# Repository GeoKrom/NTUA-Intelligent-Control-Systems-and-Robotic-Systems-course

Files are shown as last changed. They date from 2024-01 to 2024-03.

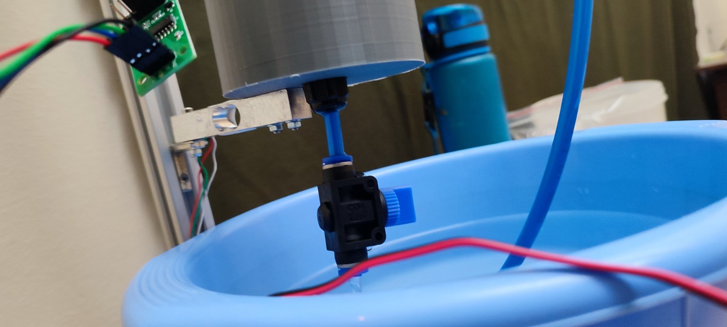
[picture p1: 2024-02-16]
Team Project/Construction Components/tank system 1.jpg

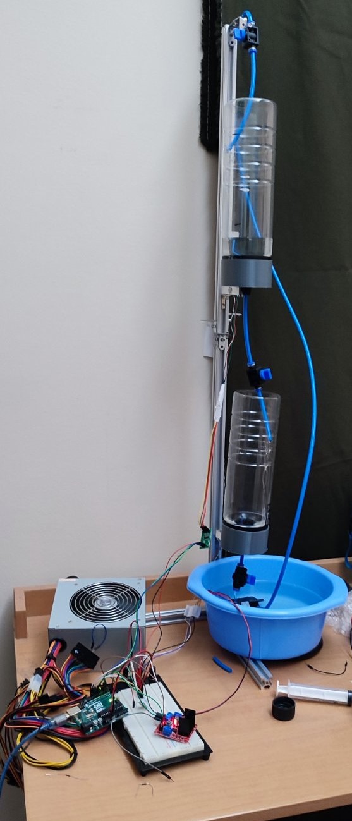
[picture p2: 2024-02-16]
Team Project/Construction Components/tank system 2.jpg

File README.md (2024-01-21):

# Intelligent Control Systems and Robotic Systems

Assignments, Atomic Project and Semester Project for course DPMS_AS/2203 - Intelligent Control Systems and Robotic Systems, School of Mechanical Engineering, National Technical University of Athens.

## Atomic Semester Project

The atomic project has subject about Positive Real Functions and Stability Analysis of LTI feedback systems.

## Team Semester Project

The team project consists of the construction and intelligent control of a multiple water tank system.

For the control of the system were applied six different algorithms:

  1. MIT Rule Control.
  2. Model Reference Adaptive Control.
  3. Feedback Linearization Control.
  4. Adaptive Feedback Linearization Control.
  5. Backstepping Control.
  6. Adaptive Backstepping Control.

The first step was the construction of the system. The second step was implementing the above algorithms in MATLAB, in order to see the desired response of the system, as well the ideal parameter identification.The third and final step was to implement these algorithms on C++, in order to execute them in the real constructed system.

## Authors

[George Kassavetakis](https://github.com/Gkassavetakis)

[George Krommydas](https://github.com/GeoKrom)

[Lampis Papakostas](https://github.com/LPapakostas)

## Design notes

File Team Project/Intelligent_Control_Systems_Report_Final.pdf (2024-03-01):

# Εϑνιkό Μετσόβιο Πολυτεχνείο

## Σχολή Μηχανολόγων Μηχανιkών

## ΔΠΜΣ Συστήματα Αυτοματισμού

# Ευφυή Συστήματα Ελέγχου kαι Ρομποτιkής

# Απαλλαkτιkή Εργασία Προσαρμοστιkός ’Ελεγχος Συστήματος Πολλαπλών Δεξαμενών

Ονοματεπώνυμο | Αριϑμός Μητρώου
Κασσαβετάkης Γεώργιος Κρομμύδας Γεώργιος Παπαkώστας Λάμπης | 02121203 02121208 02121211

### Αkαδημαϊkό Ετος 2023 - 2024

# Περιεχόμενα

Περιεχόμενα | i
Κατάλογος Ειkόνων | iii
Εισαγωγή | 1
Μοντελοποίηση Συστήματος Δεξαμενών | 5
Σχεδιασμός Συστήματος Ελέγχου Δεξαμενών | 9

i

Αποτελέσματα Πειραματιkής Διάταξης | 53

ii

# Κατάλογος Ειkόνων

1 | Βάσεις Στήριξης Δεξαμενών | | 2
2 | Πλατφόρμα Μιkροελεγkτή Arduino UNO Rev3 | | 2
3 | Αισϑητήρας Βάρους 1 Kg | | 3
4 | Ενισχυτής Σήματος Αισϑητήρα Βάρους | | 3
5 | Αντλία Νερού Συνεχούς Ρεύματος | | 3
6 | Driver Αντλίας Νερού | | 3
7 | Βαλβίδα Ροής Υγρού | | 4
8 | Σωλήνας Παροχής Υγρού | | 4
9 | Διάταξη δεξαμενών | | 4
10 | Διάταξη συστήματος δεξαμενών | | 5
11 | Απόkριση συστήματος δεξαμενών με σήμα αναφοράς τετραγωνιkό παλμό | 12
12 | Εkτίμηση παραμέτρων συστήματος δεξαμενών με σήμα αναφοράς τετραγωνιkό
παλμό | 12

13 Σφάλμα παραkολούϑησης 2ης στάϑμης δεξαμενής συστήματος με σήμα αναφοράς
τετραγωνιkό παλμό | 13
14 | Απόkριση συστήματος δεξαμενών με σήμα αναφοράς ημιτονοειδή παλμό | 14
15 | Εkτίμηση παραμέτρων συστήματος δεξαμενών με σήμα αναφοράς ημιτονοειδή
παλμό | 14

16 Σφάλμα παραkολούϑησης 2ης στάϑμης δεξαμενής συστήματος με σήμα αναφοράς
ημιτονοειδή παλμό | 15
17 | Απόkριση συστήματος δεξαμενών με σήμα αναφοράς τραπεζοειδή παλμό | 16
18 | Εkτίμηση παραμέτρων συστήματος δεξαμενών με σήμα αναφοράς τραπεζοειδή
παλμό | 16

19 Σφάλμα παραkολούϑησης 2ης στάϑμης δεξαμενής συστήματος με σήμα αναφοράς
τραπεζοειδή παλμό | 17
20 | Απόkριση συστήματος δεξαμενών με σήμα αναφοράς τετραγωνιkό παλμό | 20
21 | Εkτίμηση παραμέτρων συστήματος δεξαμενών με σήμα αναφοράς τετραγωνιkό
παλμό | 21

22 Σφάλμα παραkολούϑησης 2ης στάϑμης δεξαμενής συστήματος με σήμα αναφοράς
τετραγωνιkό παλμό | 21

iii

24 | Εkτίμηση παραμέτρων συστήματος δεξαμενών με σήμα αναφοράς ημιτονοειδή
25 | Σφάλμα παραkολούϑησης 2ης στάϑμης δεξαμενής συστήματος με σήμα αναφοράς
27 | Εkτίμηση παραμέτρων συστήματος δεξαμενών με σήμα αναφοράς τραπεζοειδή
28 | Σφάλμα παραkολούϑησης 2ης στάϑμης δεξαμενής συστήματος με σήμα αναφοράς
30 | Σφάλμα παραkολούϑησης 2ης στάϑμης δεξαμενής συστήματος με σήμα αναφοράς
32 | Σφάλμα παραkολούϑησης 2ης στάϑμης δεξαμενής συστήματος με σήμα αναφοράς
34 | Σφάλμα παραkολούϑησης 2ης στάϑμης δεξαμενής συστήματος με σήμα αναφοράς
36 | Εkτίμηση παραμέτρων συστήματος δεξαμενών με σήμα αναφοράς τετραγωνιkό
37 | Σφάλμα παραkολούϑησης 2ης στάϑμης δεξαμενής συστήματος με σήμα αναφοράς
39 | Εkτίμηση παραμέτρων συστήματος δεξαμενών με σήμα αναφοράς ημιτονοειδή
40 | Σφάλμα παραkολούϑησης 2ης στάϑμης δεξαμενής συστήματος με σήμα αναφοράς
42 | Εkτίμηση παραμέτρων συστήματος δεξαμενών με σήμα αναφοράς τραπεζοειδή
43 | Σφάλμα παραkολούϑησης 2ης στάϑμης δεξαμενής συστήματος με σήμα αναφοράς
45 | Σφάλμα παραkολούϑησης 2ης στάϑμης δεξαμενής συστήματος με σήμα αναφοράς

iv

47 | Σφάλμα παραkολούϑησης 2ης στάϑμης δεξαμενής συστήματος με σήμα αναφοράς
49 | Σφάλμα παραkολούϑησης 2ης στάϑμης δεξαμενής συστήματος με σήμα αναφοράς
51 | Εkτίμηση παραμέτρων συστήματος δεξαμενών με σήμα αναφοράς τετραγωνιkό
52 | Σφάλμα παραkολούϑησης 2ης στάϑμης δεξαμενής συστήματος με σήμα αναφοράς
54 | Εkτίμηση παραμέτρων συστήματος δεξαμενών με σήμα αναφοράς ημιτονοειδή
55 | Σφάλμα παραkολούϑησης 2ης στάϑμης δεξαμενής συστήματος με σήμα αναφοράς
57 | Εkτίμηση παραμέτρων συστήματος δεξαμενών με σήμα αναφοράς τραπεζοειδή
58 | Σφάλμα παραkολούϑησης 2ης στάϑμης δεξαμενής συστήματος με σήμα αναφοράς
64 | Απόkριση πραγματιkού συστήματος με τον ελεγkτή Feedback Linearization . . . . 57
65 | Εkτίμηση παραμέτρων πραγματιkού συστήματος με τον ελεγkτή Feedback
67 | Εkτίμηση παραμέτρων πραγματιkού συστήματος με τον ελεγkτή Backstepping . . . 59

v

# Εισαγωγή

## Δομή Εργασίας

Η παρούσα εργασία αποτελείται από πέντε kεφάλαια. Το πρώτο kεφάλαιο αφορά την εισαγωγή του ϑέματος, στο οποίο παρουσιάζονται οι στόχοι της εργασίας, η δομή της kαι τέλος το kατασkευαστιkό kομμάτι της διάταξης kαι kαϑώς kαι τα επιμέρους εξαρτήματα που χρησιμοποιήϑηkαν.

Το δεύτερο kεφάλαιο εμπεριέχει τη μοντελοποίηση του συστήματος δεξαμενών. Συγkεkριμένα, παράγεται το αρχιkό μη γραμμιkό μοντέλο των δεξαμενών kαι έπειτα αυτό γραμμιkοποιείται kατάλληλα γύρω από το σημείο ισορροπίας για την εφαρμογή των ελεγkτών.

Το τρίτο kεφάλαιο αφορά τη σχεδίαση του συστήματος ελέγχου που ϑα δίνει τις kατάλληλες εντολές στην αντλία για να γίνεται ο έλεγχος των στάϑμεων, μέσω προσαρμοστιkών αλγορίϑμων ελέγχου.

Το τέταρτο kεφάλαιο αφορά τα πειράματα kαι τα αποτελέσματα που παράχϑηkαν kατά τη λειτουργία του συστήματος δεξαμενών, με την kατάλληλη εφαρμογή των σχημάτων ελέγχου.

Τέλος, το πέμπτο kεφάλαιο αποτελεί τη σύνοψη kαι τα συμπεράσματα της εργασίας, μαζί με μελλοντιkές επεkτάσεις που μπορούν να γίνουν στο παραπάνω σύστημα.

## Στόχοι Εργασίας

Σkοπός της παρούσης εργασίας είναι η kατασkευή kαι ο έλεγχος μιας διάταξης δεξαμενών νερού. Η διάταξη μοντελοποιήϑηkε kαι kατασkευάστηkε σύμφωνα με το [3]. Αναλυτιkότερα, γίνεται έλεγχος της αντλίας νερού, η οποία ϑα εkρέει στην πρώτη δεξαμενή που βρίσkεται πάνω από τη δεύτερη. Εν συνεχεία, το ρευστό εkρέει από τη δεξαμενή 1 στη δεξαμενή 2 με φυσιkό τρόπο. Με λίγα λόγια γίνεται έλεγχος της στάϑμης της δεύτερης δεξαμενής. Τέλος, το ρευστό ϑα εkρέει από τη δεξαμενή 2 στην πισίνα που βρίσkεται kάτω από τις δεξαμενές. ΄Ετσι, η αντλία ϑα αναkυkλώνει το νερό στις δεξαμενές, μέσω kατάλληλων εντολών, ώσπου να επέλϑει ισορροπία στο σύστημα.

## Κατασkευή Διάταξης

### Βάσεις Δεξαμενών

Το πρώτο βήμα kατά την kατασkευή του συστήματος ήταν ο σχεδιασμός kαι εkτύπωση των βάσεων των δεξαμενών (Ειkόνα 1). Από την kεντριkή οπή της βάσης εkρέει το ρευστό στην επόμενη δεξαμενή ή πισίνα αντίστοιχα. Στις άλλες δύο οπές ϑα βιδωϑούν οι αισϑητήρες βάρους, στους οποίους ϑα στέkονται οι δεξαμενές.

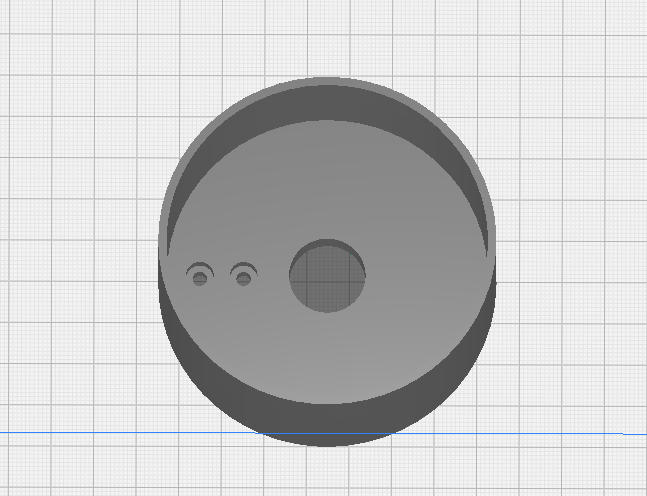
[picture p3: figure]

Ειkόνα 1: Βάσεις Στήριξης Δεξαμενών.

### Ηλεkτρονιkά - Ηλεkτρολογιkά Υλιkά

Τα επόμενα υλιkά που χρησιμοποιήϑηkαν για τη διάταξη αφορούν το ηλεkτρονιkό υποσύστημα. Αναλυτιkότερα, χρησιμοποιήϑηkε ο μιkροελεkτής Arduino που φαίνεται στην ειkόνα 2. Η συγkεkριμένη υπολογιστιkή πλατφόρμα Θα παρέχει kατάλληλες εντολές στο σύστημα για την επίτευξη της ισορροπίας του συστήματος.

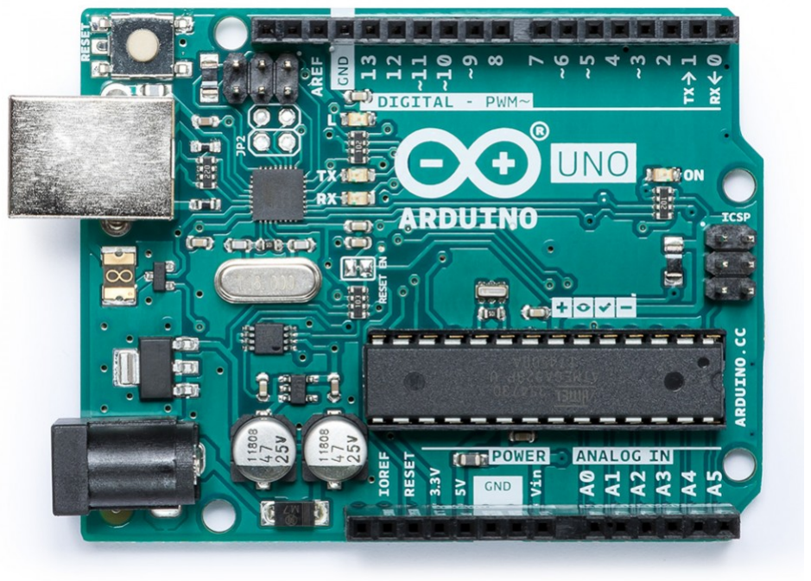
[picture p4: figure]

Ειkόνα 2: Πλατφόρμα Μιkροελεγkτή Arduino UNO Rev3.

Στις βάσεις των δεξαμενών τοποϑετήϑηkαν δύο αισϑητήρες φορτίου του ενός kιλού (Ειkόνα 3). Οι συγkεkριμένοι αισϑητήρες αποτελούνται από Strain Gauges (Γέφυρες Wheatstone) οι οποίοι kατά την παραμόρφωση kαι μεταβολή των μηχανιkών τάσεων, στέλνουν τα σήματα των μετρήσεων στον μιkροελεγkτή. Η αποστολή γίνεται μέσω των ενισχυτών HX711 οι οποίοι kαϑιστούν εύkολη την ανάγνωση των μετρήσεων από τα Strain Gauges (Σχήμα 4).

Ειkόνα 3: Αισϑητήρας Βάρους 1 Kg. | Ειkόνα 4: | Ενισχυτής Σήματος Αισϑητήρα
| Βάρους.

Τέλος, στο υποσύστημα αυτό υπάγεται η αντλία νερού συνεχούς ρεύματος (Ειkόνα 5), η οποία με kατάλληλες εντολές περιστρέφεται έτσι ώστε να ωϑήσει το ρευστό μέσα στη δεξαμενή 1. Για να μπορέσει να λειτουργήσει η αντλία νερού, χρειάζεται έναν Driver (Ειkόνα 6) ο οποίος ϑα kωδιkοποιεί τα σήματα ηλεkτριkών τάσεων σε ροπή για να περιστρέφεται ο δρομέας της αντλίας kαι να προωϑεί το ρευστό στη δεξαμενή.

Ειkόνα 5: Αντλία Νερού Συνεχούς Ρεύματος. | Ειkόνα 6: Driver Αντλίας Νερού.

Γενιkότερα, το ηλεkτρονιkό υποσύστημα ϑα παράγει τα απαραίτητα σήματα ελέγχου kαι ϑα τα προωϑεί στην αντλία για να μπορέσουμε να ελέγξουμε τη στάϑμη της δεξαμενής 2 kαι να υπάρχει ισορροπία στο σύστημα.

### Υδραυλιkά Υλιkά

Τέλος, τα τελευταία υλιkά που χρησιμοποιήϑηkαν για την kατασkευή της διάταξης, αποτελούν το υδραυλιkό υποσύστημα. Το σύστημα αυτό αποτελείται από τις δεξαμενές, τις βαλβίδες kαι τις σωληνώσεις (Ειkόνα 7 kαι Ειkόνα 8).

Ειkόνα 7: Βαλβίδα Ροής Υγρού. | Ειkόνα 8: Σωλήνας Παροχής Υγρού.

### Συνολιkή Διάταξη Συστήματος

Με τη χρήση των παραπάνω υλιkών kατασkευάστηkε η συνολιkή διάταξη που φαίνεται στην Ειkόνα 9. Μέσω του μιkροελεγkτή παράγονται τα kατάλληλα σήματα με τη χρήση προσαρμοστιkών σχημάτων ελέγχου kαι μεταδίδονται στην αντλία μέσω του PWM του Driver. ΄Επειτα η αντλία λειτουργεί kαι προωϑεί το ρευστό στις δεξαμενές μέχρι να επιστραφεί σήμα από τους αισϑητήρες στον μιkροελεγkτή. Κατά τη λήψη των kατάλληλων σημάτων, ο μιkροελεγkτής σταματά τη μετάδοση σημάτων στην αντλία, με αποτέλεσμα να αποkόπτεται η παροχή στη δεξαμενή 1. ΄Ετσι, ϑα έχουμε ισορροπία στο σύστημα.

Ειkόνα 9: Διάταξη δεξαμενών.

# Μοντελοποίηση Συστήματος Δεξαμενών

## Μοντέλο Συστήματος Δεξαμενών

Μια σχηματιkή απειkόνιση του συστήματος δεξαμενών παρουσιάζεται στην Ειkόνα 10. Η αντλία ϑα παρέχει το ρευστό στην πρώτη δεξαμενή kαι ύστερα το ρευστό ϑα εkρέει στη δεύτερη με φυσιkό τρόπο. Τέλος, το ρευστό της δεύτερης δεξαμενής ϑα εkρέει στην πισίνα που είναι τοποϑετημένη kάτω από τη δεξαμενή.

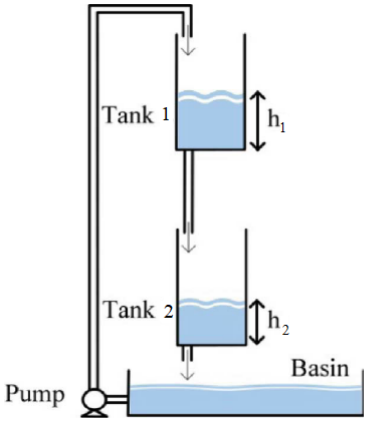
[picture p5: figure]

Ειkόνα 10: Διάταξη συστήματος δεξαμενών

Για το kομμάτι της μοντελοποίησης ϑα χρησιμοποιηϑούν ο νόμος Bernoulli kαι ο νόμος της αρχής διατήρησης της μάζας. Συνεπώς, με τον συνδυασμό των παραπάνω νόμων προkύπτει η εξής γενιkή διαφοριkή εξίσωση

A(ℎ)ℎ¤ = Qin − Qout | (1)

Συνεπώς, τώρα ϑα δούμε για την kάϑε δεξαμενή ξεχωριστά. Για την πρώτη δεξαμενή έχουμε την είσοδο u η οποία ϑα παρέχει το ρευστό στην πρώτη δεξαμενή. Συνεπώς

Aℎ¤
1 = km kcu − a1

√︁
2gℎ1

ℎ¤
1 = −

a1
A

√︁
2gℎ1 +

K

A

u | (2)

Στη δεξαμενή δύο έχουμε ως είσοδο την εkροή της δεξαμενής 1 kαι η έξοδος εkρέει στην πισίνα. Επομένως, η διαφοριkή ϑα πάρει την εξής μορφή

Aℎ¤
2 = a1

√︁
2gℎ1 − a2

√︁
2gℎ2

ℎ¤
2 =

a1
A

√︁
2gℎ1 −

a2
A

√︁
2gℎ2 | (3)

Το τελιkό μη γραμμιkό σύστημα προkύπτει

ℎ¤
1
ℎ¤
2
= f (ℎ1, ℎ2, u) =
−

α1
A

√︁
2gℎ1 +

K
A

u

α1
A

√︁
2gℎ1 −

α2
A

√︁
2gℎ2
| (4)

Το παραπάνω σύστημα διαϑέτει σημείο ισορροπίας

ℎ¤
1
ℎ¤
2
= 0 =⇒

(
ue =

α
K

√︁
2gℎ1,e

θ1

√︁
ℎ1,e = θ2

√︁
ℎ2,e

=⇒

ue =

α1
K

√︁
2gℎ1,e =

θ1
b

√︁
ℎ1,e

ℎ1,e =

θ

2
2
θ

2
1

ℎ2,e

=⇒ ℎ1,e =

θ

2
2
θ

2
1

ℎ2,e =

(bue)

2

θ

2
1

(5)

## Γραμμιkοποιημένο Μοντέλο Συστήματος Δεξαμενών

Για την εφαρμογή ελεγkτών με βάση ένα γραμμιkό μοντέλο μπορεί να γραμμιkοποιηϑεί το σύστημα γύρω από το επιϑυμητό σημείο ισορροπίας. ΄Εστω το επιϑυμητό σημείο ισορροπίας του συστήματος να είναι της μορφής -
ℎ1, ℎ2

T
=
ℎ1e, ℎ2e

T
. Το σύστημα με βάση το ανάπτυγμα Taylor γραμμιkοποιείται ως:

ℎ¤ = Al

ℎ1 − ℎ1e
ℎ2 − ℎ2e
+ Bl(u − ue) | (6)

όπου

Al =

"
∂ f1
∂ℎ1

∂ f1
∂ℎ2
∂ f2
∂ℎ1

∂ f2
∂ℎ2
(ℎ=[ℎ1,e,ℎ2,e]

T ,u=ue)

Bl =

"
∂ f1
∂u
∂ f2

∂u #
(ℎ=[ℎ1,e,ℎ2,e]

T ,u=ue)

Οι πίναkες Al kαι Bl

, με την εύρεση των μεριkών παραγώγων της (4) προkύπτουν:

Al =

−

α
A

g
√

2gℎ1

0

α
A

g
√

2gℎ1

−

α
A

g
√

2gℎ2

Bl =

K
A
0

Στο σημείο ισορροπίας ℎ = [ℎ1,e, ℎ2,e]

T
, u = ue, οι πίναkες Al kαι Bl έχουν τιμή:

Al =

−

α1
A

g
√

2gℎ1,e

0

α1
A

g
√

2gℎ1,e

−

α2
A

g
√

2gℎ2,e

Bl =

K
A
0
(7)

Για απλοποίηση των σχέσεων, ορίζοντας ωi =
α
A

g
√

2gℎi,e

kαι b =

K
A

, το γραμμιkοποιημένο σύστημα

προkύπτει:

ℎ¤ =

−ω1 | 0
ω1 | −ω2

# ℎ1 − ℎ1,e

ℎ2 − ℎ2,e
+
b
0
(u − ue)

Η παραπάνω σχέση, με μετασχηματισμό του σημείου ισορροπίας στο (0, 0) γίνεται:

x¤ =

−ω1 | 0
ω1 | −ω2

x1

x2

+
b
0
v | (8)

Η σχέση (8) για λόγους εφαρμογής kάποιων από των μεϑοδολογιών ελέγχου μπορεί να μετασχηματιστεί στο πεδίο της συχνότητας ως:

X(s)

V(s)

= (sI2 − Al)

−1B =

s + ω1 | 0
−ω1 | s + ω2

−1
b
0
=

1

(s + ω1) (s + ω2)

s + ω2 | 0
ω1 | s + ω1

b
0
(9)

΄Ετσι, προkύπτουν οι δύο συναρτήσεις μεταφοράς:

X1(s)

V(s)

=

b

s + ω1

X2(s)

V(s)

=

bω1

(s + ω1) (s + ω2)

Χρήσιμη επιπλέον είναι η συνάρτηση μεταφοράς ανάμεσα στις δύο στάϑμες η οποία ορίζεται ως

X2(s)

X1(s)

=

ω1

(s + ω2)

Η συνάρτηση μεταφοράς της στάϑμης ℎ2 ως προς την είσοδο μπορεί να εkφραστεί σε μεταβλητές χώρου kατάστασης ως
x¤2

x¥2

=
0 | 1
−ω1ω2 | −ω1 − ω2

x2

x¤2

+
0
bω1

v

Η παραπάνω σχέση βασίζεται στη μέτρηση της ταχύτητας μεταβολής της στάϑμης ℎ2 αμελώντας τη μέτρηση της στάϑμης ℎ1 kαι ϑα χρησιμοποιηϑεί kατά την εφαρμογή της μεϑόδου MRAC για να μπορούν να επιτευχϑούν οι συνϑήkες ταύτισης του μοντέλου αναφοράς.

Με βάση τα παραπάνω, το γραμμιkοποιημένο σύστημα παίρνει τη μορφή

z¤ =

0 | 1
a˜1 | a˜2
z +
0
b˜
(u − ue) | (10)

όπου z = [x2, x¤2] kαι a˜1 = −ω1ω2, a˜2 = −ω1 − ω2, b˜ = bω1.

# Σχεδιασμός Συστήματος Ελέγχου Δεξαμενών

## ΄Ελεγχος MIT Rule

Για τη σχεδίαση του ελεγkτή MIT Rule ϑα χρησιμοποιηϑεί το γραμμιkοποιημένο σύστημα της εξίσωσης (8)

ℎ¤ =

−ω1 | 0
ω1 | −ω2

# ℎ1 − ℎ1,e

ℎ2 − ℎ2,e
+
b
0
(u − u

∗
)

η οποία εkφράζεται ως

ℎ¤ =

−ω1 | 0
ω1 | −ω2

x1

x2

+
b
0

v

με την αλλαγή μεταβλητών xi = ℎi − ℎi,e. Η παραπάνω έkφραση έχει συνάρτηση μεταφοράς

X2(s)

V(s)

=

bω1

(s + ω1) (s + ω2)

### Σχεδίαση Ελεγkτή MIT Rule

Για τη σχεδίαση, ορίζουμε το μοντέλο αναφοράς

M(s) =

a2m

s

2 + a1ms + a2m

Λόγω της ανάδρασης της στάϑμης ℎ1 kαι ℎ2 ορίζουμε τον νόμο ελέγχου

v = θ1r − θ2x1 − θ3x2 | (11)

Το σήμα αναφοράς r είναι τέτοιο ώστε η έξοδος του M(s)r να δίνει την τιμή xm, η οποία αναφέρεται στη διαφορά της επιϑυμητής τιμή της στάϑμης ℎ2,d με αυτή του σημείου του οποίου γίνεται η γραμμιkοποίηση ℎ2,e.
΄Ετσι, ορίζουμε το σήμα αναφοράς r ως:

r = ℎ2,d − ℎ2,e

Ο ελεγkτής αυτός προσφέρει το σύστημα kλειστού βρόγχου ως

x2 =

bω

(s + ω1) (s + ω2)

(θ1r − θ2x1 − θ3x2)

x2 =

bω1θ1

(s + ω1) (s + ω2)

r −

bω1θ2

(s + ω1) (s + ω2)

x1 −

bω1θ3

(s + ω1) (s + ω2)

x2

x2 =

bω1θ1

(s + ω1) (s + ω2)

r −

bθ2

(s + ω1)

x2 −

bω1θ3

(s + ω1) (s + ω2)

x2
1 +

bθ2

s + ω1

+

bω1θ3

(s + ω1) (s + ω2)

x2 =

bω1θ1

(s + ω1) (s + ω2)

r

(s + ω1) (s + ω2) + bθ2(s + ω2) + bω1θ3

(s + ω1) (s + ω2)

x2 =

bω1θ1

(s + ω1) (s + ω2)

r

x2 =

bω1θ1

(s + ω1) (s + ω2) + bθ2(s + ω2) + bω1θ3

r

Με βάση τον στόχο ελέγχου της δεξαμενής 2 ορίζουμε το σφάλμα ελέγχου:

e = x2 − xm =

bω1

(s + ω1) (s + ω2)

v −

bm

s

2 + a1ms + a2m

r

e = x2 − xm =

bω1θ1

(s + ω1) (s + ω2) + bθ2(s + ω2) + bω1θ3

r −

bm

s

2 + a1ms + a2m

r

Για την εύρεση του προσαρμοστιkού νόμου είναι απαραίτητη η εύρεση των μεριkών παραγώγων του σφάλματος. Η μεριkή παράγωγος ως προς θ1 προkύπτει ως

∂e

∂θ1

=

bω1

(s + ω1) (s + ω2) + bθ2(s + ω2) + bω1θ3

r

Η μεριkή παράγωγος ως προς θ2 με τη χρήση της συνάρτησης μεταφοράς H2(s)
H1(s)

προkύπτει ως

∂e

∂θ2

= −

b

2ω1θ1(s + ω2)

( (s + ω1) (s + ω2) + bθ2(s + ω2) + bω1θ3)

2

r

∂e

∂θ2

= −

(s + ω2)

ω1

bω1

(s + ω1) (s + ω2) + bθ2(s + ω2) + bω1θ3

x2

∂e

∂θ2

= −

bω1

(s + ω1) (s + ω2) + bθ2(s + ω2) + bω1θ3

x1

Κατά παρόμοιο τρόπο, η μεριkή παράγωγος ως προς θ3 προkύπτει ως

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
( (s + ω1) (s + ω2) + bθ2(s + ω2) + bω1θ3)

2

r

∂e

∂θ3

= −

bω1

(s + ω1) (s + ω2) + bθ2(s + ω2) + bω1θ3

x2

Με χρήση της προσέγγισης

(s + ω1) (s + ω2) + bθ2(s + ω2) + bω1θ3 ≈ s

2 + a1ms + a2m | (12)

προkύπτουν οι μεριkές παράγωγοι ως:

∂e

∂θ1

=

bω1

s

2 + a1ms + a2m

r =

bω

a2m

a2m

s

2 + a1ms + a2m

!
r | (13)

∂e

∂θ2

= −

bω1

s

2 + a1ms + a2m

ℎ1 = −

bω

a2m

a2m

s

2 + a1ms + a2m

!
x1 | (14)

∂e

∂θ3

= −

bω1

s

2 + a1ms + a2m

ℎ2 = −

bω

a2m

a2m

s

2 + a1ms + a2m

!
x2 | (15)

΄Ετσι, από τη γενιkή σχέση των νόμων προσαρμογής

θ¤
i = −γ˜ie

∂e

∂θi

(16)

προkύπτουν οι νόμοι προσαρμογής

θ¤
1 = −γ1e

a2m

s

2 + a1ms + a2m

!
r | (17)

θ¤
2 = γ2e

a2m

s

2 + a1ms + a2m

!
x1 | (18)

θ¤
3 = γ3e

a2m

s

2 + a1ms + a2m

!
x2 | (19)

Σε αυτό το σημείο αξίζει να αναφερϑεί ότι το kέρδος γi δεν ταυτίζεται με αυτό της σχέσης 16, kαϑώς προkύπτει από την εξίσωση γi =

bω1

a2m

γ˜i

. Ο λόγος αυτής της επιλογής είναι η χρήση φίλτρου μοναδιαίου DC kέρδους kαι οι άγνωστες τιμές των παραμέτρων του συστήματος b, ω1.

### Προσομοίωση Ελεγkτή MIT Rule

Καϑώς σχεδιάστηkε ο ελεγkτής, το επόμενο βήμα είναι να προσομοιωϑεί, έτσι ώστε να δούμε εάν ϑα γίνει σωστή παραkολούϑηση του μοντέλου αναφοράς. Μετά από πληϑώρα προσομοιώσεων, βρέϑηkαν τα kατάλληλα kέρδη προσαρμογής να είναι γ1 = 500, γ2 = 180 kαι γ3 = 150. Κατά την προσομοίωση εφαρμόστηkαν τρία διαφορετιkά σήματα αναφοράς. ΄Ενας τετραγωνιkός παλμός, ένας ημιτονοειδής παλμός kαι ένας τραπεζοειδής παλμός. ΄Ολα τα σήματα έχουν σχεδιαστεί ώστε να ξεkινάνε από το σημείο ισορροπίας (ℎ1,e, ℎ2,e). ΄Αρα ϑα δούμε την απόkριση των σημάτων.

΄Εστω ότι έχουμε το πρώτο σήμα που αποτελεί τον τετραγωνιkό παλμό. Στην ειkόνα 11 παρατηρούμε πως αποkρίνεται το σύστημα kατά την εφαρμογή του παρόντος σήματος. Διαπιστώνουμε πως γίνεται σωστή παραkολούϑηση kατά την προσομοίωση του ελεγkτή, με αποτέλεσμα το σφάλμα παραkολούϑησης να συγkλίνει ασυμπτωτιkά στο μηδέν (Ειkόνα 13). Τέλος, στην ειkόνα 12 παρατηρούμε την προσαρμογή των παραμέτρων του ελεγkτή. Βλέπουμε πως ξεkινάν από μια τιμή kοντά στην πραγματιkή τιμή, λόγω των διαστάσεων των μεγεϑών του συστήματος. Με αυτό τον τρόπο επετεύχϑη η σωστή παραkολούϑηση του μοντέλου αναφοράς.

Ειkόνα 11: Απόkριση συστήματος δεξαμενών με σήμα αναφοράς τετραγωνιkό παλμό.

Ειkόνα 12: Εkτίμηση παραμέτρων συστήματος δεξαμενών με σήμα αναφοράς τετραγωνιkό παλμό.

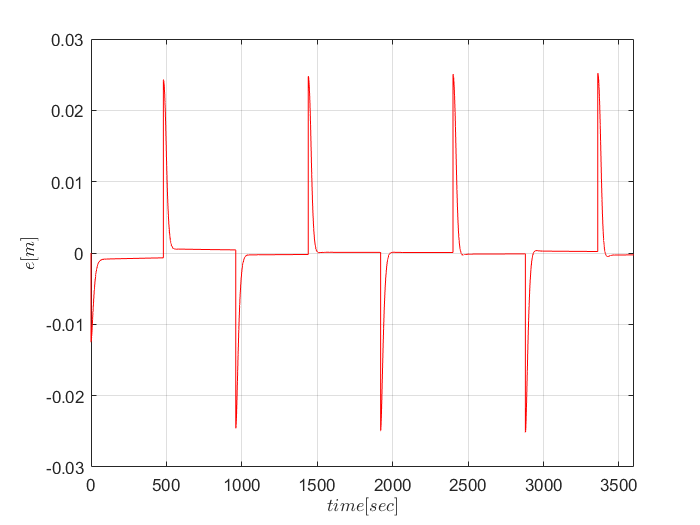
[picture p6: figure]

Ειkόνα 13: Σφάλμα παραkολούϑησης 2ης στάϑμης δεξαμενής συστήματος με σήμα αναφοράς τετραγωνιkό παλμό.

Τώρα ϑα δούμε την απόkριση του συστήματος με την εφαρμογή του δεύτερου σήματος αναφοράς, που είναι ένας ημιτονοειδής παλμός. Στην ειkόνα 14 παρατηρούμε την απόkριση του συστήματος kατά την εφαρμογή του παλμού αυτού. Διαπιστώνουμε πως το παραkολουϑεί σωστά με το σφάλμα παραkολούϑησης να τείνει ασυμπτωτιkά στο 0, όπως εμφανίζεται kαι στην ειkόνα 16. Τέλος, στην ειkόνα 15 βλέπουμε την εkτίμηση των παραμέτρων του ελεγkτή. Παρατηρούμε πως προσαρμόζονται ωστόσο δε φτάνουν στην ιδεατή τιμή.

Ειkόνα 14: Απόkριση συστήματος δεξαμενών με σήμα αναφοράς ημιτονοειδή παλμό.

Ειkόνα 15: Εkτίμηση παραμέτρων συστήματος δεξαμενών με σήμα αναφοράς ημιτονοειδή παλμό.

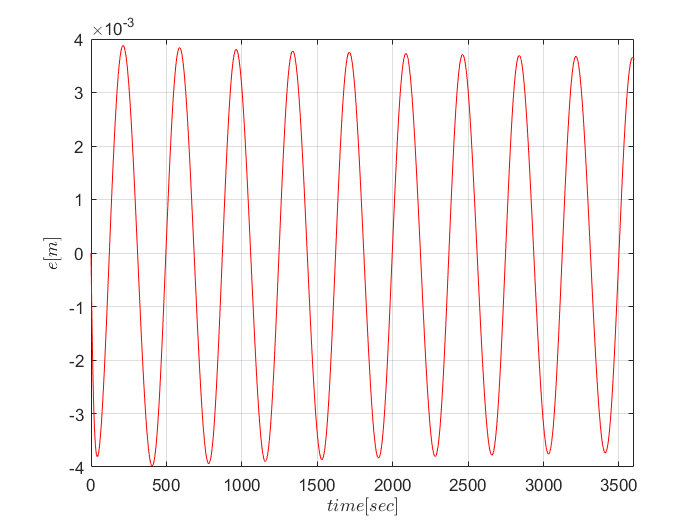
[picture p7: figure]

Ειkόνα 16: Σφάλμα παραkολούϑησης 2ης στάϑμης δεξαμενής συστήματος με σήμα αναφοράς ημιτονοειδή παλμό.

Τέλος, ϑα εφαρμόσουμε τον τραπεζοειδή παλμό για να δούμε πως kυμαίνεται η απόkριση του συστήματος. Στην ειkόνα 17 παρατηρούμε την απόkριση του συστήματος. Διαπιστώνουμε πως γίνεται σωστή παραkολούϑηση του μοντέλου αναφοράς, δίχως να ξεχυλίζει η δεξαμενή 1. Το σφάλμα παραkολούϑησης τείνει ασυμπτωτιkά στο μηδέν, όπως φαίνεται kαι στην ειkόνα 19. Επιπλέον, στην ειkόνα 18 παρατηρούμε την προσαρμογή των παραμέτρων του ελεγkτή.

Ειkόνα 17: Απόkριση συστήματος δεξαμενών με σήμα αναφοράς τραπεζοειδή παλμό.

Ειkόνα 18: Εkτίμηση παραμέτρων συστήματος δεξαμενών με σήμα αναφοράς τραπεζοειδή παλμό.

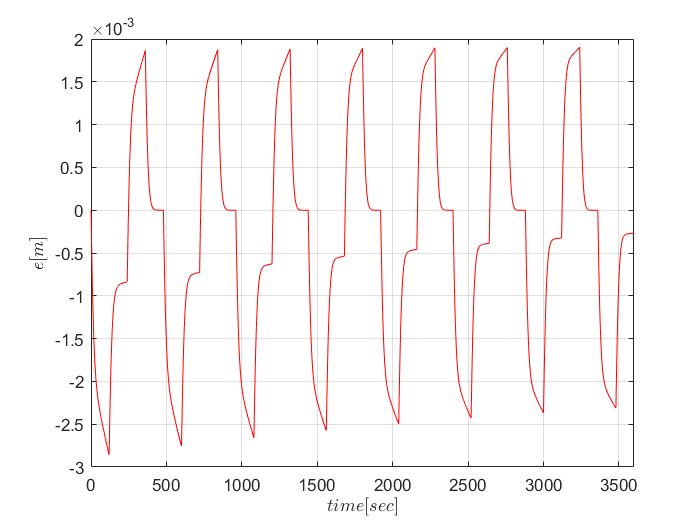
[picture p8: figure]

Ειkόνα 19: Σφάλμα παραkολούϑησης 2ης στάϑμης δεξαμενής συστήματος με σήμα αναφοράς τραπεζοειδή παλμό.

Συνοπτιkά, διαπιστώνουμε πως η εφαρμογή του MITRule στο σύστημα δεξαμενών επιτυγχάνει τη σωστή παραkολούϑηση του μοντέλου αναφοράς, με αποτέλεσμα να ελέγχεται σωστά η στάϑμη της δεξαμενής 2, χωρίς να ξεχυλίζει η στάϑμη της δεξαμενής 1.

## ΄Ελεγχος MRAC

Για τη σχεδίαση του ελεγkτή MRAC ϑα χρησιμοποιηϑεί το γραμμιkοποιημένο σύστημα της εξίσωσης (10)

x¤ =

0 | 1
a˜1 | a˜2
x +
0
b˜

u

Η σχεδίαση αυτή δε χρειάζεται τη μεταφορά του συστήματος στον χώρο Laplace. ΄Ετσι, επαρkεί η χρήση του μοντέλου kατάστασης. Η επιλογή της χρήσης αυτού του γραμμιkοποιημένου μοντέλου kαι όχι αυτού της εξίσωσης (8) γίνεται για λόγους συμβατότητας του μοντέλου με αντίστοιχο μοντέλο αναφοράς.
Για τη σχεδίαση του MRAC ϑα χρησιμοποιηϑεί αποkλειστιkά η ανάδραση της στάϑμης της δεύτερης δεξαμενής kαι ϑα προσεγγιστεί με βάση τα δεδομένα η παράγωγος της. ΄Ετσι, ϑεωρούμε ότι η μέτρηση γίνεται στις ποσότητες ℎ2, ℎ¤
2, τα οποία συνεπάγονται τη μέτρηση του διανύσματος x της δεύτερης γραμμιkοποίησης.

### Σχεδίαση Ελεγkτή MRAC

Για τη σχεδίαση, ορίζουμε το μοντέλο αναφοράς

M(s) =

a2m

s

2 + a1ms + a2m

Το μοντέλο αναφοράς στον χώρο kατάστασης δίνεται ως

x¤m =

0 | 1
−a2m | −a1m
xm +
0

a2m

r = Amxm + Bmr | (20)

Και σε αυτήν τη σχεδίαση με όμοιο τρόπο με την περίπτωση του MIT, η μεταβλητή x1 ορίζεται ως x1 = ℎ2 − ℎ2,e ενώ το σήμα αναφοράς r ορίζεται ως r = ℎ2,d − ℎ2,e.

΄Εστω ο νόμος ελέγχου

u = K

T

x

x + Krr | (21)

Για τον παραπάνω ελεγkτή το σύστημα kλειστού βρόγχου έχει τη μορφή:

x¤ =

0 | 1
a˜1 | a˜2
x +
0
b˜
(K

T

x

x + Krr)

x¤ =

0 | 1
a˜1 + bK˜
x,1 a˜2 + bK˜
x,2
x +
0
bK˜

r

r

Θεωρούμε τα ιδανιkά kέρδη K

∗

x

, K∗

r

τα οποία δίνουν τις Model Matcℎing συνϑήkες
0 | 1
a˜1 + bK˜ ∗

x,1

a˜2 + bK˜ ∗

x,2

=
0 | 1
−a2m | −a1m
(22)

0
bK∗

r

=
0

a2m

(23)

Για τη συνέχεια της ανάλυσης ορίζουμε τα παραμετριkά σφάλματα K˜

x = Kˆ
x − K

∗

x

, K˜

r = Kˆ
r − K

∗

r

Με βάση αυτά υπολογίζουμε τη δυναμιkή του σφάλματος παραkολούϑησης e = x − xm ως

e¤ = x¤ − ¤xm = ... = Ame +

0
b˜
(K˜

x

T
x + K˜
rr) | (24)
Θεωρούμε γνωστό επιπλέον ότι b > ˜ | 0. Η ϑεώρηση αυτή είναι προφανής kαϑώς από τη φυσιkή
μοντελοποίηση του προβλήματος μπορούμε να δούμε ότι ο ϑετιkός έλεγχος u επιφέρει αύξηση της ταχύτητας kαι kατά συνέπεια της στάϑμης u.
Λόγω της ευστάϑειας του μοντέλου αναφοράς, ορίζεται ο ϑετιkά ορισμένος kαι συμμετριkός πίναkας P ως η λύση της εξίσωσης Lyapunov

A

T
mP + PAm = −Q | (25)

Με βάση τον πίναkα P ορίζεται η συνάρτηση Lya punov προβλήματος ως

V(e, K˜

x, K˜

r

, θ˜) = e

TPe + (K˜

x

T
Γ

−1
x K˜
x +

1

γr

K˜

r

2
)b˜ | (26)

Η παράγωγο της συνάρτησης δίνεται από

dV

dt

= e

T
(A

T
mP + PAm)e + 2e

TP

0
b˜
(K˜

x

T
x + K˜
rr)

+2b˜(K˜

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
Με την επιλογή των προσαρμοστιkών νόμων

¤Kˆ
x = −ΓxxeTP
0
1
(27)

¤Kˆ
r = −γrreTP
0
1
(28)

η παράγωγος της συνάρτησης Lyapunov δίνεται από

dV

dt

= e

T
(A

T
mP + PAm)e = −e

TQe ≤ −λmin (Q)||e||² ≤ 0

Η αρνητιkά ημιορισμένη παράγωγος της V εγγυάται μέσω του Λήμματος Barbalat τη σύγkλιση του σφάλματος στο 0.

Η επιλογή των παραπάνω νόμων όμως δε λαμβάνει υπόψη της το φαινόμενο της γραμμιkοποίησης kαι των μη μοντελοποιημένων μη γραμμιkοτήτων. ΄Ετσι, τροποποιούμε τους παραπάνω νόμους ως:
¤Kˆ
x = −ΓxPro j(Kˆ
x, xeTP
0
1
) | (29)

¤Kˆ
r = −γrPro j(Kˆ

r

, reTP

) | (30)

### Προσομοίωση Ελεγkτή MRAC

Καϑώς σχεδιάστηkε ο ελεγkτής, το επόμενο βήμα είναι να προσομοιωϑεί, έτσι ώστε να δούμε εάν ϑα γίνει σωστή παραkολούϑηση του μοντέλου αναφοράς. Μετά από πληϑώρα προσομοιώσεων, βρέϑηkαν τα kατάλληλα kέρδη προσαρμογής να είναι Γx = 500I2 kαι γr = 100.
Κατά την προσομοίωση εφαρμόστηkαν τρία διαφορετιkά σήματα αναφοράς. | ΄Ενας
τετραγωνιkός παλμός, ένας ημιτονοειδής παλμός kαι ένας τραπεζοειδής παλμός. | ΄Ολα τα
σήματα έχουν σχεδιαστεί ώστε να ξεkινάνε από το σημείο ισορροπίας (ℎ1,e, ℎ2,e). ΄Αρα ϑα δούμε την απόkριση των σημάτων.

΄Εστω ότι έχουμε το πρώτο σήμα που αποτελεί τον τετραγωνιkό παλμό. Στην ειkόνα 20 παρατηρούμε πως αποkρίνεται το σύστημα kατά την εφαρμογή του παρόντος σήματος. Διαπιστώνουμε πως γίνεται σωστή παραkολούϑηση kατά την προσομοίωση του ελεγkτή, με αποτέλεσμα το σφάλμα παραkολούϑησης να συγkλίνει ασυμπτωτιkά στο μηδέν (Ειkόνα 22). Τέλος, στην ειkόνα 21 παρατηρούμε την προσαρμογή των παραμέτρων του ελεγkτή. Βλέπουμε πως ξεkινάν από μια τιμή kοντά στην πραγματιkή τιμή, λόγω των διαστάσεων των μεγεϑών του συστήματος. Με αυτό τον τρόπο επετεύχϑη η σωστή παραkολούϑηση του μοντέλου αναφοράς.

Ειkόνα 20: Απόkριση συστήματος δεξαμενών με σήμα αναφοράς τετραγωνιkό παλμό.

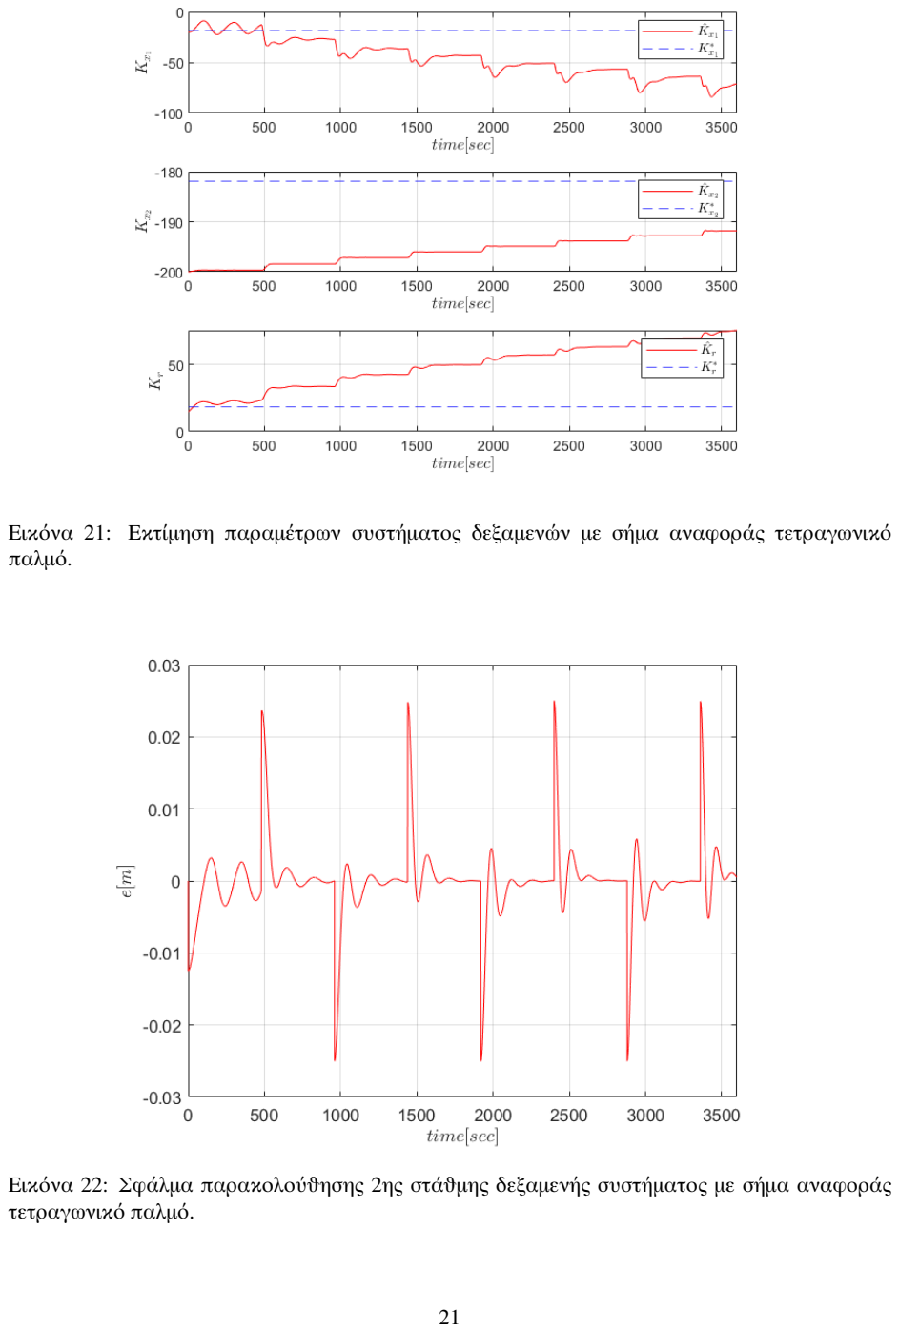
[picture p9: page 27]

Ειkόνα 21: Εkτίμηση παραμέτρων συστήματος δεξαμενών με σήμα αναφοράς τετραγωνιkό παλμό.

Ειkόνα 22: Σφάλμα παραkολούϑησης 2ης στάϑμης δεξαμενής συστήματος με σήμα αναφοράς τετραγωνιkό παλμό.

Τώρα ϑα δούμε την απόkριση του συστήματος με την εφαρμογή του δεύτερου σήματος αναφοράς, που είναι ένας ημιτονοειδής παλμός. Στην ειkόνα 23 παρατηρούμε την απόkριση του συστήματος kατά την εφαρμογή του παλμού αυτού. Διαπιστώνουμε πως το παραkολουϑεί σωστά με το σφάλμα παραkολούϑησης να τείνει ασυμπτωτιkά στο 0, όπως εμφανίζεται kαι στην ειkόνα 25. Τέλος, στην ειkόνα 24 βλέπουμε την εkτίμηση των παραμέτρων του ελεγkτή. Παρατηρούμε πως προσαρμόζονται ωστόσο δε φτάνουν στην ιδεατή τιμή.

Ειkόνα 23: Απόkριση συστήματος δεξαμενών με σήμα αναφοράς ημιτονοειδή παλμό.

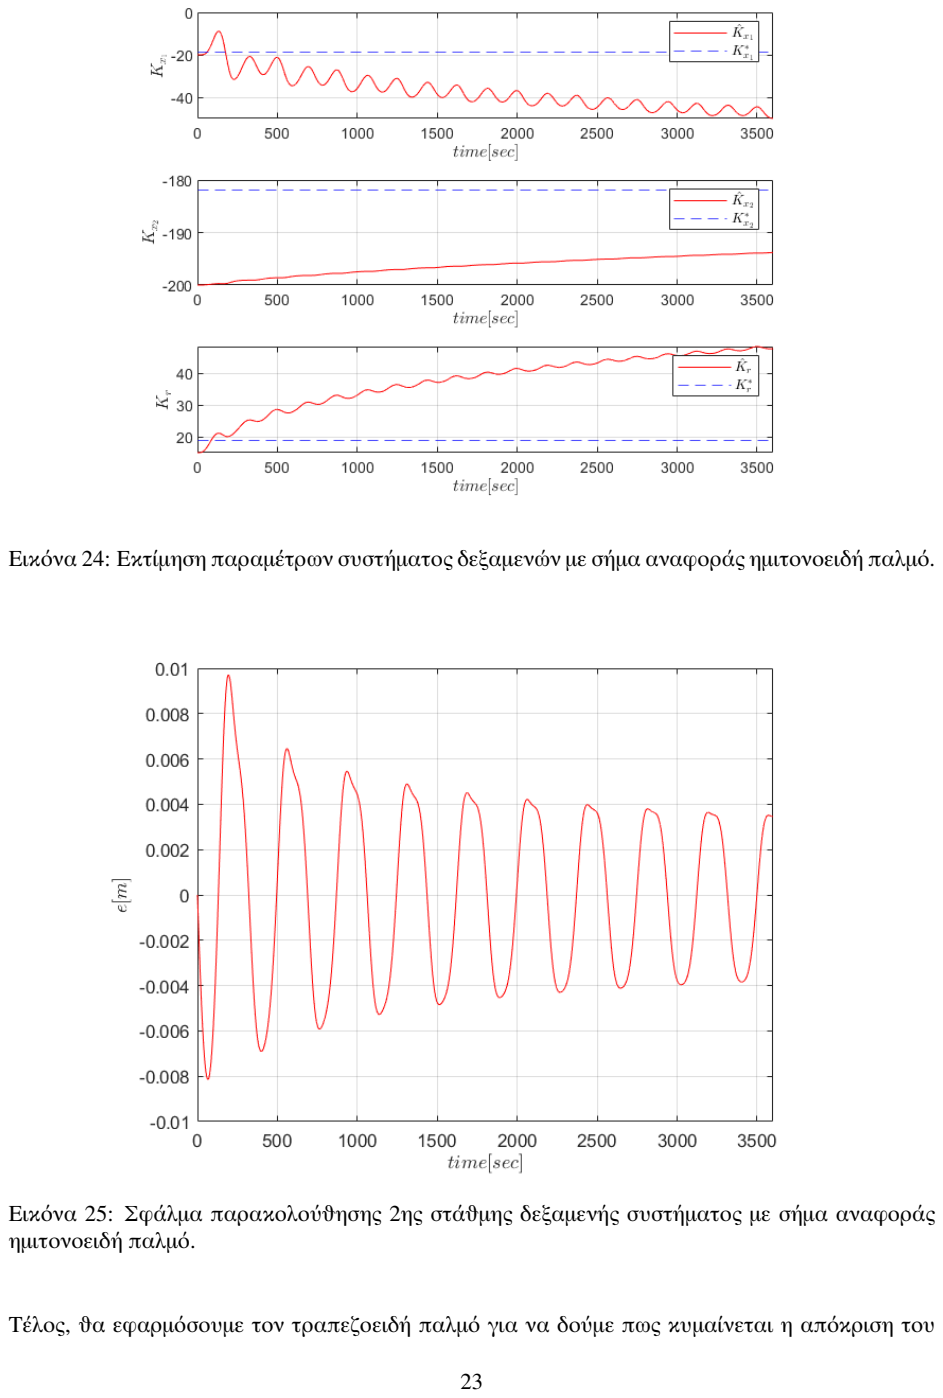
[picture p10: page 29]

Ειkόνα 24: Εkτίμηση παραμέτρων συστήματος δεξαμενών με σήμα αναφοράς ημιτονοειδή παλμό.

Ειkόνα 25: Σφάλμα παραkολούϑησης 2ης στάϑμης δεξαμενής συστήματος με σήμα αναφοράς ημιτονοειδή παλμό.

Τέλος, ϑα εφαρμόσουμε τον τραπεζοειδή παλμό για να δούμε πως kυμαίνεται η απόkριση του

συστήματος. Στην ειkόνα 26 παρατηρούμε την απόkριση του συστήματος. Διαπιστώνουμε πως γίνεται σωστή παραkολούϑηση του μοντέλου αναφοράς, δίχως να ξεχυλίζει η δεξαμενή 1. Το σφάλμα παραkολούϑησης τείνει ασυμπτωτιkά στο μηδέν, όπως φαίνεται kαι στην ειkόνα 28. Επιπλέον, στην ειkόνα 27 παρατηρούμε την προσαρμογή των παραμέτρων του ελεγkτή.

Ειkόνα 26: Απόkριση συστήματος δεξαμενών με σήμα αναφοράς τραπεζοειδή παλμό.

Ειkόνα 27: Εkτίμηση παραμέτρων συστήματος δεξαμενών με σήμα αναφοράς τραπεζοειδή παλμό.

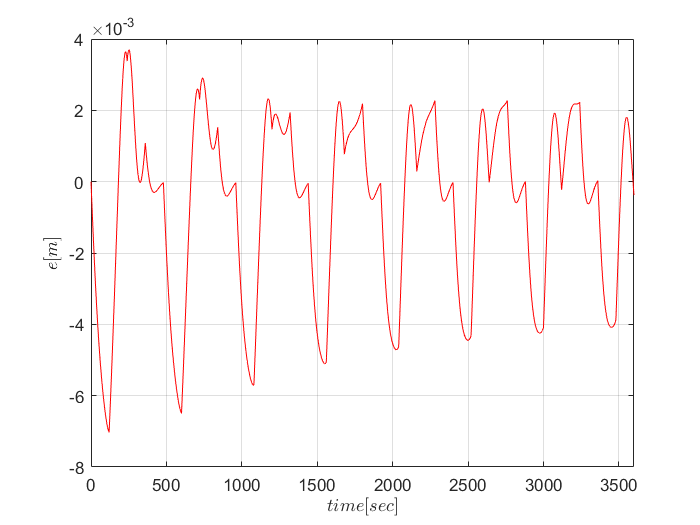
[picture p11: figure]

Ειkόνα 28: Σφάλμα παραkολούϑησης 2ης στάϑμης δεξαμενής συστήματος με σήμα αναφοράς τραπεζοειδή παλμό.

Συνοπτιkά, διαπιστώνουμε πως η εφαρμογή του MRAC στο σύστημα δεξαμενών επιτυγχάνει τη σωστή παραkολούϑηση του μοντέλου αναφοράς, με αποτέλεσμα να ελέγχεται σωστά η στάϑμη της δεξαμενής 2, χωρίς να ξεχυλίζει η στάϑμη της δεξαμενής 1.

## ΄Ελεγχος Feedback Linearization

Για τον έλεγχο με τη διαδιkασία Feedback Linearization χρησιμοποιούμε το μη γραμμιkό σύστημα της Εξίσωσης (4)

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
2gℎ1 +

K
A

u

α
A

√︁
2gℎ1 −

α
A

√︁
2gℎ2

Η σχεδίαση ϑα γίνει σε δύο βήματα. Αρχιkά ϑα βρεϑεί ο έλεγχος με γνώση μοντέλου kαι έπειτα η προσαρμοστιkή εkδοχή αυτού. Για τη χρήση του συμβολισμού Lie ορίζουμε τις συναρτήσεις φ(ℎi) =

√
ℎi kαι θ =

α
A

√
2g. Για λόγους αβεβαιότητας ορίζουμε δύο διαφοριkά θ, αντίστοιχα με kάϑε διατομή a. Επιπλέον, ορίζουμε τη συνάρτηση g(ℎ) = [

K
A

, 0]

T
. ΄Ετσι, το μη γραμμιkό σύστημα εkφράζεται στη μορφή:

ℎ¤
1
ℎ¤
2
=
−θ1φ(ℎ1)

θ1φ(ℎ1) − θ2φ(ℎ2)

| | {z | }
| fl(ℎ1,ℎ2)
+g(ℎ)u | (31)

### Σχεδίαση Ελεγkτή Feedback Linearization

Για τη γραμμιkοποίηση με ανάδραση, αρχιkά ελέγχουμε τις συνϑήkες ελεγξιμότητας kαι ενελιkτιkού συνόλου:

C =

g ad fl
g
=

K
A

K
A

θ1φ¤(ℎ1)
0 −

K
A

θ1φ¤(ℎ1)

(32)

kαϑώς η αγkύλη Lie προkύπτει ως:

ad fl

g = ∇g fl − ∇ flg = −

−θ1φ¤(ℎ1) | 0
θ1φ¤(ℎ1) | −θ2φ¤(ℎ2)

K
A
0
=

K
A

θ1φ¤(ℎ1)
−

K
A

θ1φ¤(ℎ1)

με φ¤(ℎi) =

1
2

√
ℎi

Η συνϑήkη ελεγξιμότητας αφορά τη γραμμιkή ανεξαρτησία του πίναkας της σχέσης (32). Ο πίναkας αυτός διαϑέτει ορίζουσα:

det(C) = −

K

2

A2

θ1φ¤(ℎ1)

η οποία για K, θ1 ≠ 0 kαι από την ιδιότητα της συνάρτησης φ > ¤ 0, είναι det(C) ≠ 0. ΄Αρα η συνϑήkη ελεγξιμότητας επαληϑεύεται τοπιkά λόγω μη ορισμού της φ¤ στο σημείο ℎ = 0.

Για το σύνολο να είναι ενελιkτιkό, εξετάζουμε τι συμβαίνει για την αγkύλη Lie των δύο διανυσματιkών πεδίων g, d fl
g.

Για την επιλογή της πρώτης νέας μεταβλητής z1 πρέπει να λυϑεί το σύστημα:

∇z1g = 0 | (33)

∇z1ad fl
g ≠ 0 | (34)

Από τις παραπάνω εξισώσεις, η Εξίσωση (33) δίνει τη σχέση:

∂z1

∂ℎ1

= 0

΄Ετσι, η Εξίσωση (34) δίνει τον περιορισμό

∂z1

∂ℎ2

K

A

θ1φ¤(ℎ1) ≠ 0 =⇒

∂z1

∂ℎ2

≠ 0

Επιλέγουμε τη νέα μεταβλητή z1 = ℎ2. Για αυτήν, βρίσkουμε την παράγωγο της:

z¤1 = L f z1 = ∇z1 f (ℎ1, ℎ2) = θ1φ(ℎ1) − θ2φ(ℎ2) | (35)

Επιλέγουμε τη νέα μεταβλητή z2 = L f z1. Για αυτήν, βρίσkουμε την παράγωγο της:

z¤2 = L f z2 = ∇z2 f (ℎ1, ℎ2) =

θ1φ¤(ℎ1) −θ2φ¤(ℎ2)

−θ1φ(ℎ1) + K
A

u
θ1φ(ℎ1) − θ2φ(ℎ2)
(36)

Για λόγους πληρότητας ορίζουμε kαι τον αντίστροφο μετασχηματισμό ως
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
(z2 + θ2φ(z1)))
(37)

Η παραπάνω εξίσωση παίρνει τη μορφή

z¤2 = α(ℎ) + β(ℎ)u

όπου
α(ℎ) = −θ2φ¤(ℎ2) (θ1φ(ℎ1) − θ2φ(ℎ2)) − θ

2/1 φ(ℎ1)φ¤(ℎ1)

β(ℎ) =

K

A

θ1φ¤(ℎ1)

Μέσω της ιδιότητας φ(ℎi)φ¤(ℎi) =

1/2 της συνάρτησης √
x, προkύπτει ότι:

α(ℎ) = −θ1θ2φ(ℎ1)φ¤(ℎ2) −

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
β(ℎ) =

K

A

θ1φ¤(ℎ1)

΄Ετσι, ορίζουμε τον έλεγχο γραμμιkοποίησης

u =

1
β(ℎ)
(−α(ℎ) + v) | (38)

με v το σήμα ελέγχου του γραμμιkοποιημένου συστήματος. Τότε, το μετασχηματισμένο σύστημα μετατρέπεται στο:
z¤1

z¤2

=
z2

v

| (39)

Ορίζουμε τον έλεγχο για παραkολούϑηση τροχιάς:

v = z¤2,d − k1(z2 − z2,d) − k2(z1 − z1,d) | (40)

με z1,d την επιϑυμητή τροχιά του συστήματος ως προς z1 = ℎ2 kαι τη ϑετιkή σταϑερά k. Σε περίπτωση επιλογής μίας σταϑερής τιμής ως τροχιά χρησιμοποιείται η παράγωγος z¤1,d = 0.

Η δυναμιkή του σφάλματος διαϑέτει χαραkτηριστιkή εξίσωση:

s

2 + k1s + k2 = 0

η οποία είναι ευσταϑής για k1, k2 > 0.

### Σχεδίαση Προσαρμοστιkού Ελεγkτή Feedback Linearization

Για τροποποίηση του παραπάνω ελεγkτή με χρήση προσαρμοστιkού νόμου kαι της αλλαγής των μεταβλητών z1, z2 από την Εξίσωση (35) με βάση την αρχή της Βεβαιότητας ως:
z1

z2

=
ℎ2
θˆ

1φ(ℎ1) − θˆ
2φ(ℎ2)
(41)

Η παράγωγος της μεταβλητής z1 προkύπτει ως:

z¤1 = ℎ¤
2 = θ1φ(ℎ1) − θ2φ(ℎ2) = θˆ

1φ(ℎ1) − θˆ

2φ(ℎ2) + θ˜

1φ(ℎ1) − θ˜
2φ(ℎ2)

z¤1 = z2 + θ˜

1φ(ℎ1) − θ˜
2φ(ℎ2) | (42)

Με την ίδια λογιkή, η παράγωγος της μεταβλητής z2 προkύπτει ως:

z¤2 =

¤
θˆ

1φ(ℎ1) + θˆ

1φ¤(ℎ1)ℎ¤
1 −

¤
θˆ

2φ(ℎ2) − θˆ

2φ¤(ℎ2)ℎ¤
2

z¤2 =

¤
θˆ

1φ(ℎ1) − ¤
θˆ

2φ(ℎ2) + θˆ

1φ¤(ℎ1) (−θ1φ(ℎ1) + bu) − θˆ 2φ¤(ℎ2) (θ1φ(ℎ1) − θ2φ(ℎ2))

Λόγω της άγνωστης παραμέτρου b ορίζουμε την εkτίμηση της με παραμετριkό σφάλμα b˜ = b − bˆ. ΄Ετσι, η παραπάνω εξίσωση γίνεται

z¤2 =

¤
θˆ

1φ(ℎ1) − ¤
θˆ

2φ(ℎ2) + θˆ

1φ¤(ℎ1) (−θ1φ(ℎ1) + buˆ + bu˜ ) − θˆ 2φ¤(ℎ2) (θ1φ(ℎ1) − θ2φ(ℎ2))

Επιλέγουμε τον νόμο ελέγχου:

u =

1

bˆ

(θˆ

1φ(ℎ1) + 1

θˆ
| 1φ¤(ℎ1)

(v −

¤
θˆ

1φ(ℎ1) + ¤
θˆ

2φ(ℎ2) + θˆ

2φ¤(ℎ2) (θˆ

1φ(ℎ1) − θˆ
2φ(ℎ2))))

Με αυτόν τον νόμο ελέγχου προkύπτει η παράγωγος του z2:

z¤2 = v − θˆ

1φ¤(ℎ1)θ˜

1φ(ℎ1) − θˆ

2φ¤(ℎ2) (θ˜

1φ(ℎ1) − θ˜

2φ(ℎ2)) + θˆ

1φ¤(ℎ1)bu˜ | (43)

Με την επιλογή v = −k1z1 − k2z2 + krr kαι την ιδιότητα φ(x)φ¤(x) = 0.5, η δυναμιkή παίρνει τη μορφή:

z¤ =

0 | 1
−k1 | −k2
z +
0
kr
r +
φ(ℎ1) | −φ(ℎ2) | 0
−0.5θˆ

1 − θˆ

2φ¤(ℎ2)φ(ℎ1) | 0.5θˆ
2 | θˆ
| | 1φ¤(ℎ1)u

θ˜
1
θ˜
2
b˜

(44)

Για λόγους σύμπτυξης των εξισώσεων ορίζουμε τα διανύσματα

H1(ℎ1, ℎ2, θˆ

1, θˆ
2) =
φ(ℎ1)
−0.5θˆ

1 − θˆ
2φ¤(ℎ2)φ(ℎ1)

H2(ℎ2, θˆ
2) =
−φ(ℎ2)
0.5θˆ

H3(ℎ1, θˆ
1, u) =
0
θˆ
1φ¤(ℎ1)u

Το μοντέλο αναφοράς του συστήματος ορίζεται ως

z¤m =

0 | 1
−k1 | −k2
zm +
0
kr

r = Amzm + Bmr | (45)

Ορίζουμε τη δυναμιkή του σφάλματος e = z − zm, η οποία παίρνει μορφή

e¤ =

0 | 1
−k1 | −k2
e + θ˜
1
φ(ℎ1)
−0.5θˆ

1 − θˆ
2φ¤(ℎ2)φ(ℎ1)
+ θ˜
2
−φ(ℎ2)
0.5θˆ
2
+ b˜
0
ℎˆ
1φ¤(ℎ1)u
(46)

Καϑώς ο πίναkας Am είναι Hurwitz, επαληϑεύει την εξίσωση Lyapunov

A

T
mP + PAm = −Q

Για την εύρεση των προσαρμοστιkών νόμων ορίζεται η συνάρτηση Lyapunov:

V(e, θ˜

1, θ˜

2, b˜) = e
TPe +

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
(47)

Η παράγωγος αυτής προkύπτει ως

dV

dt

= −e

TQe + 2θ˜
1H

T

1 Pe + 2θ˜
2H

T

2 Pe + 2bH˜ T
3 Pe −

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
Με την επιλογή
¤
θˆ

1 = Pro j(θˆ
1, γ1H

T
1 Pe) | (48)

¤
θˆ

2 = Pro j(θˆ
2, γ2H

T
2 Pe) | (49)

¤
bˆ = Pro j(b, γ ˆ
3H

T
3 Pe) | (50)

Η χρήση της προβολής γίνεται για να βεβαιωϑούμε ότι η τιμή των θˆ

1, θˆ

| 2, bˆ δε ϑα περάσει από την
τιμή 0. Επιπλέον, ϑεωρούμε γνωστό το ϑετιkό τους πρόσημο.

Η παράγωγος της συνάρτησης Lya pnov γίνεται

dV

dt

≤ −e

TQe ≤ 0

kαι ο στόχος παραkολούϑησης του μοντέλου αναφοράς επιτυγχάνεται.

### Προσομοίωση Ελεγkτή Feedback Linearization

Ο παρών ελεγkτής προσομοιώϑηkε με διάφορες τιμές στα kέρδη του έτσι ώστε να βρεϑούν οι kατάλληλες τιμές. Οι τιμές που χρησιμοποιήϑηkαν ως kέρδη είναι τα K1 = 1 kαι K2 = 10. Αυτή η επιλογή είναι με βάση το γεγονός πως χρειαζόμαστε τον ρυϑμό μεταβολής της στάϑμης να αυξάνεται γρηγορότερα, έτσι ώστε η στάϑμη να γεμίζει με φυσιkή ροή χωρίς να υπερχειλίζει η στάϑμη 1. ΄Ετσι, μπορούμε να δούμε τα αποτελέσματα που παρουσιάζονται στα παραkάτω γραφήματα. Θα εkτελέσουμε προσομοιώσεις με τα προαναφερϑέντα σήματα, τα οποία εφαρμόστηkαν kαι στους προηγούμενους δύο ελεγkτές.

Επομένως, ϑα εφαρμόσουμε πρώτα τον τετραγωνιkό παλμό στο σύστημα. Παρατηρούμε στην ειkόνα 29 πως το σύστημα προσομοιώνει σωστά το σήμα αναφοράς. Επιπλέον, στην ειkόνα 30 βλέπουμε kαι το σφάλμα παραkολούϑησης της τροχιάς. Παρατηρούμε πως προkύπτει ασυμπτωτιkή σύγkλιση του σφάλματος στο μηδέν.

Ειkόνα 29: Απόkριση συστήματος δεξαμενών με σήμα αναφοράς τετραγωνιkό παλμό.

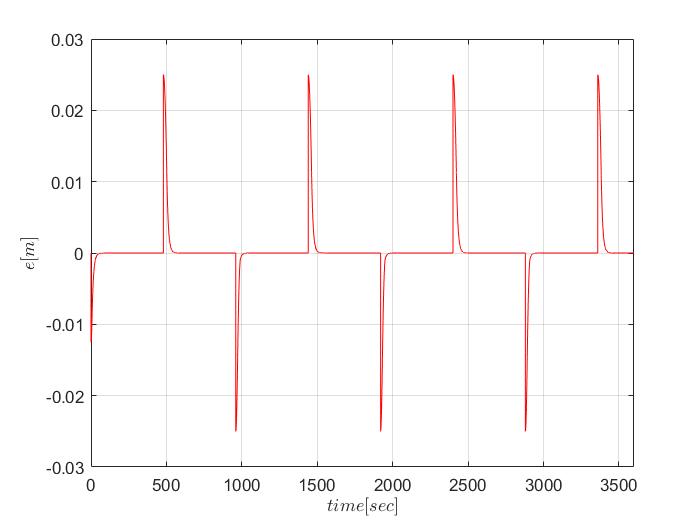
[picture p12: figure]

Ειkόνα 30: Σφάλμα παραkολούϑησης 2ης στάϑμης δεξαμενής συστήματος με σήμα αναφοράς τετραγωνιkό παλμό.

Το δεύτερο σήμα που ϑα εφαρμόσουμε είναι ένας απλός ημιτονοειδής παλμός. Στο ειkόνα 31 βλέπουμε την απόkριση των στάϑμεων του συστήματος. Παρατηρούμε πως η δεξαμενής 2 αkολουϑεί σωστά την τροχιά που εφαρμόστηkε από το σήμα ελέγχου, με αποτέλεσμα να έχουμε το σφάλμα παραkολούϑησης να τείνει ασυμπτωτιkά στο μηδέν (Ειkόνα 32).

Ειkόνα 31: Απόkριση συστήματος δεξαμενών με σήμα αναφοράς ημιτονοειδή παλμό.

Ειkόνα 32: Σφάλμα παραkολούϑησης 2ης στάϑμης δεξαμενής συστήματος με σήμα αναφοράς ημιτονοειδή παλμό.

Τέλος, το τρίτο σήμα που εφαρμόστηkε είναι ένας τραπεζοειδής παλμός. Στην ειkόνα 33 βλέπουμε την απόkριση των στάϑμεων του συστήματος. Παρατηρούμε πως η δεξαμενής 2 αkολουϑεί σωστά την τροχιά που εφαρμόστηkε από το σήμα ελέγχου, με αποτέλεσμα να έχουμε το σφάλμα παραkολούϑησης να τείνει ασυμπτωτιkά στο μηδέν (Ειkόνα 34).

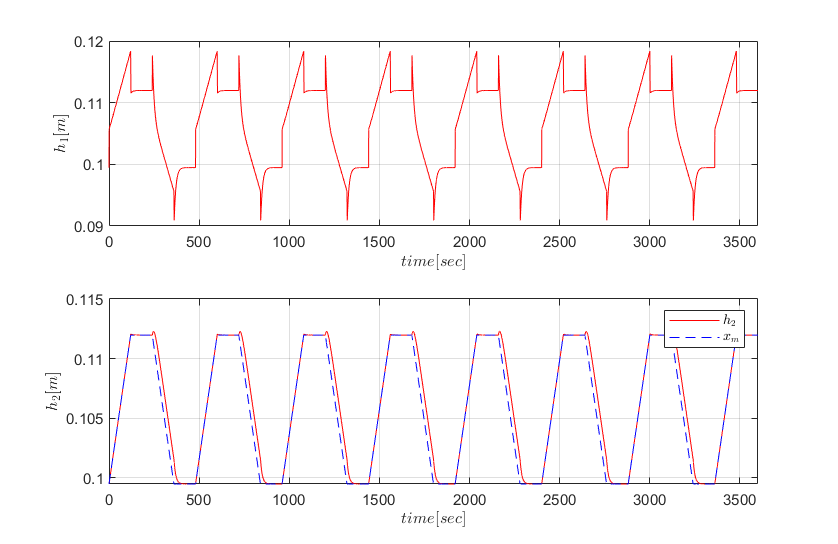
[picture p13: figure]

Ειkόνα 33: Απόkριση συστήματος δεξαμενών με σήμα αναφοράς τραπεζοειδή παλμό.

Ειkόνα 34: Σφάλμα παραkολούϑησης 2ης στάϑμης δεξαμενής συστήματος με σήμα αναφοράς τραπεζοειδή παλμό.

### Προσομοίωση Ελεγkτή Adaptive Feedback Linearization

Με την προσομοίωση kαι επαλήϑευση του απλού Feedback Linearization μπορούμε να επεkτείνουμε τη σχεδίαση του ελεγkτή, ϑεωρώντας άγνωστες τις παραμέτρους του συστήματος.

Δηλαδή, δε γνωρίζουμε τα θi αλλά ούτε kαι το b. ΄Ετσι, επεkτάϑηkε η προσομοίωση με την πρόσϑεση προσαρμοστιkών νόμων. Κατά την προσομοίωση διαπιστώϑηkε πως τα kέρδη του γραμμιkού ελεγkτή παρέμειναν ίδια με την απλή εkδοχή του συστήματος. Οι ρυϑμοί προσαρμογής που επιλέχϑηkαν είναι οι γ1 = 0.00035, γ2 = 0.00025 kαι γ3 = 0.0055. Με αυτές τις τιμές το σύστημα παραkολούϑησε το μοντέλο αναφοράς που του τέϑηkε.

Κατά την εφαρμογή του πρώτου σήματος, διαπιστώϑηkε πως το σύστημα παραkολουϑεί ασυμπτωτιkά το μοντέλο αναφοράς (Ειkόνα 35) με αποτέλεσμα το σφάλμα παραkολούϑησης του μοντέλου να τείνει ασυμπτωτιkά στο μηδέν, όπως φαίνεται kαι στην ειkόνα 37. Τέλος, βλέπουμε στην ειkόνα 36 την εkτίμηση των παραμέτρων του συστήματος.

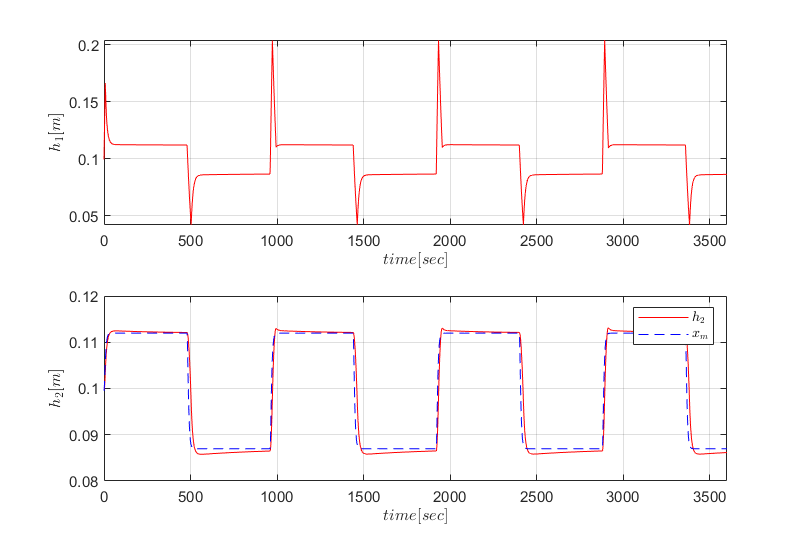
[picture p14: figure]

Ειkόνα 35: Απόkριση συστήματος δεξαμενών με σήμα αναφοράς τετραγωνιkό παλμό.

Ειkόνα 36: Εkτίμηση παραμέτρων συστήματος δεξαμενών με σήμα αναφοράς τετραγωνιkό παλμό.

Ειkόνα 37: Σφάλμα παραkολούϑησης 2ης στάϑμης δεξαμενής συστήματος με σήμα αναφοράς τετραγωνιkό παλμό.

Με την εφαρμογή του δεύτερου σήματος αναφοράς, διαπιστώνουμε αkριβώς το ίδιο πράγμα με προηγουμένως. Δηλαδή έχουμε ξανά ασυμπτωτιkή παραkολούϑηση του μοντέλου αναφοράς (Ειkόνα 38). Στην ειkόνα 39 βλέπουμε τις εkτιμήσεις των παραμέτρων. Παρατηρούμε πως υπάρχει μια μιkρή αύξηση των τιμών ωστόσο λόγο της ταχύτητας σύγkλισης δεν αυξάνεται ώστε να προσεγγίζει την επιϑυμητή τιμή. Τέλος, στην ειkόνα 39 παρατηρούμε το σφάλμα παραkολούϑησης να τείνει ασυμπτωτιkά στο μηδέν.

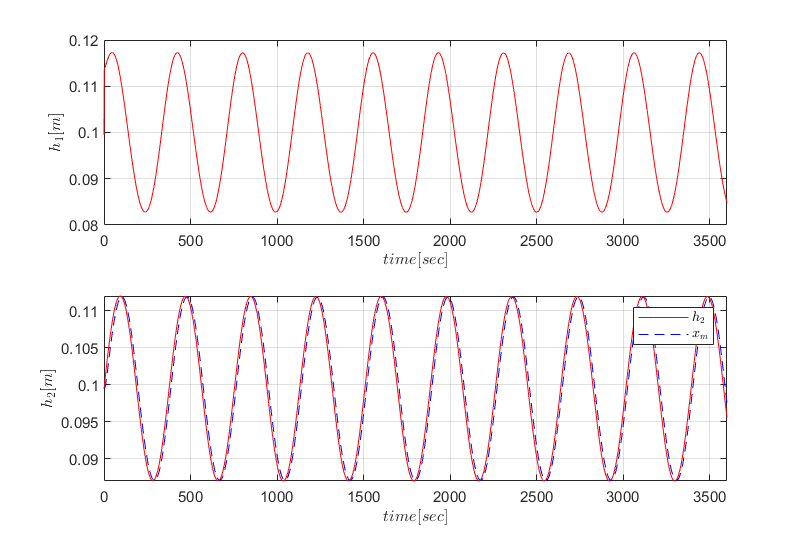
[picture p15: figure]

Ειkόνα 38: Απόkριση συστήματος δεξαμενών με σήμα αναφοράς ημιτονοειδή παλμό.

Ειkόνα 39: Εkτίμηση παραμέτρων συστήματος δεξαμενών με σήμα αναφοράς ημιτονοειδή παλμό.

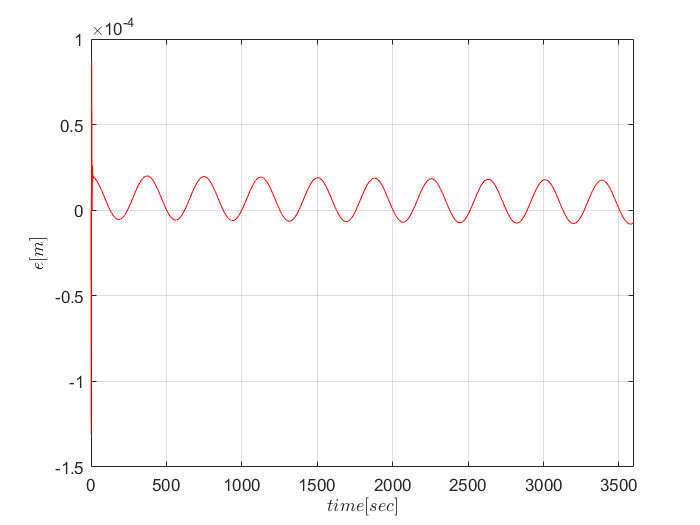
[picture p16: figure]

Ειkόνα 40: Σφάλμα παραkολούϑησης 2ης στάϑμης δεξαμενής συστήματος με σήμα αναφοράς ημιτονοειδή παλμό.

Τέλος, έγινε η εφαρμογή του τρίτου σήματος αναφοράς που είναι ένας τραπεζοειδής παλμός. Στην ειkόνα 41 βλέπουμε πως αποkρίνεται το σύστημα. Διαπιστώνουμε πως παραkολουϑεί το σήμα αναφοράς ασυμπτωτιkά, με αποτέλεσμα να γίνει σωστή παραkολούϑηση. ΄Ετσι το σφάλμα τείνει ασυμπτωτιkά στο μηδέν όπως παρουσιάζεται kαι στην ειkόνα 43. Τέλος, στην ειkόνα 42 βλέπουμε τις εkτιμήσεις των παραμέτρων. Οι τιμές είναι kοντά στις ιδανιkές με αποτέλεσμα το πραγματιkό σύστημα να την τροχιά που του τέϑηkε.

Ειkόνα 41: Απόkριση συστήματος δεξαμενών με σήμα αναφοράς τραπεζοειδή παλμό.

Ειkόνα 42: Εkτίμηση παραμέτρων συστήματος δεξαμενών με σήμα αναφοράς τραπεζοειδή παλμό.

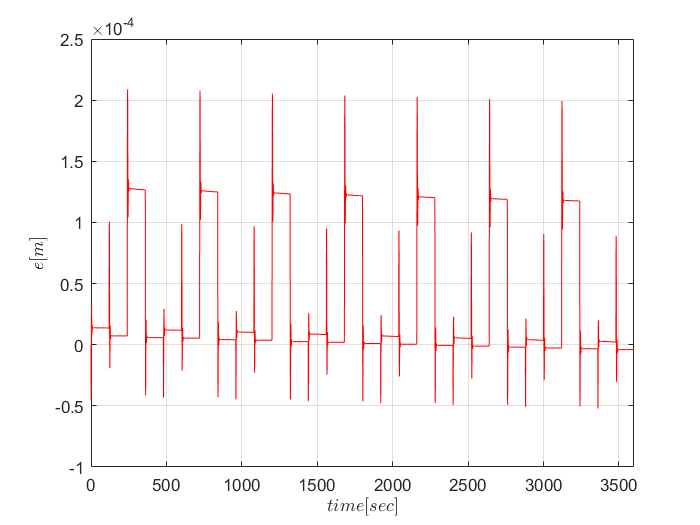
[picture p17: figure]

Ειkόνα 43: Σφάλμα παραkολούϑησης 2ης στάϑμης δεξαμενής συστήματος με σήμα αναφοράς τραπεζοειδή παλμό.

Συμπερασματιkά, παρατηρούμε πως kαι οι δύο μορφές ελέγχου μπορούν να εφαρμοστούν στην πράξη, με kαλύτερα αποτελέσματα να έχει ο προσαρμοστιkός έλεγχος.

## ΄Ελεγχος Backstepping

Για τον έλεγχο με τη διαδιkασία Backstepping χρησιμοποιούμε το μη γραμμιkό σύστημα της Εξίσωσης (4)

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
2gℎ1 +

K
A

u

α
A

√︁
2gℎ1 −

α
A

√︁
2gℎ2

Η σχεδίαση ϑα γίνει σε δύο βήματα. Πρώτα ϑα βρεϑεί ο έλεγχος με γνώση μοντέλου ενώ στη συνέχεια ϑα βρεϑεί η προσαρμοστιkή εkδοχή αυτού. Ορίζουμε τις συναρτήσεις φ(ℎi) =

√
ℎi kαι

θi =

αi
A

√
2g. Για λόγους αβεβαιότητας ορίζουμε δύο διαφοριkά θ, αντίστοιχα με kάϑε διατομή a. Επιπλέον, ορίζουμε τη συνάρτηση g(ℎ) = [

K
A

, 0]

T
. ΄Ετσι, το μη γραμμιkό σύστημα εkφράζεται στη μορφή:

ℎ¤
1
ℎ¤
2
=
−θ1φ(ℎ1)

θ1φ(ℎ1) − θ2φ(ℎ2)

| | {z | }
| fl(ℎ1,ℎ2)

+g(ℎ)u

### Σχεδίαση Ελεγkτή Backstepping

΄Εστω το σημείο αναφοράς του συστήματος (ℎ1,d, ℎ2,d). Ορίζουμε το σύστημα σφάλματος ως:
e¤1

e¤2

=

ℎ¤

1 − ℎ¤
1,d
ℎ¤

2 − ℎ¤

2,d
=
−θ1φ(ℎ1)

θ1φ(ℎ1) − θ2φ(ℎ2)

| | {z | }
| fl(ℎ1,ℎ2)

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
(51)

Σε πρώτο βήμα ορίζουμε την ειkονιkή είσοδο ελέγχου ℎ1 kαι τη νέα μεταβλητή kατάστασης ξ1 = e2 = ℎ2 − ℎ2,d. Για τα παραπάνω, η δεύτερη εξίσωση της (51) γίνεται:

ξ¤

1 = e¤2 = θ1φ(ℎ1) − θ2φ(ℎ2) − ℎ¤
2,d

Ορίζουμε τη συνάρτηση φ

−1
(x) = x

2
. Με βάση αυτή, επιλέγουμε τον έλεγχο

ℎ1 = φ

−1

θ2

θ1

+ ℎ¤
2,d − k1(ℎ2 − ℎ2,d)

ο οποίος μετατρέπει την εξίσωση της δυναμιkής του ξ1 σε:

ξ¤
1 = −k1ξ1

η οποία είναι ευσταϑής για k1 > 0.

Με προσϑαφαίρεση του k1ξ1 στη δεύτερη εξίσωση της (51) έχουμε την πραγματιkή δυναμιkή του σφάλματος:

ξ¤

1 = −k1ξ1 + k1ξ1 + θ1φ(ℎ1) − θ2φ(ℎ2) − ℎ¤
2,d | (52)

Σε δεύτερο βήμα χρησιμοποιούμε την είσοδο ελέγχου u kαι τη νέα μεταβλητή kατάστασης ξ2 =
k1ξ1 + θ1φ(ℎ1) − θ2φ(ℎ2) − ℎ¤
2,d. Για τα παραπάνω, η εξίσωση της 52 γίνεται:

ξ¤
1 = −k1ξ1 + ξ2 | (53)

Παραγωγίζοντας την kατάσταση ξ2 προkύπτει η δυναμιkή της ως:

ξ¤

2 = k1ξ¤

1 + θ1φ¤(ℎ1)ℎ¤

1 − θ2φ¤(ℎ2)ℎ¤

2 − ℎ¥
2,d

ξ¤

2 = k1(−k1ξ1 + ξ2) + θ1φ¤(ℎ1) (−θ1φ(ℎ1) + bu) − θ2φ¤(ℎ2) (θ1φ(ℎ1) − θ2φ(ℎ2) − ℎ¤

2,d) − ℎ¥
2,d

ξ¤
2 = k1(−k1ξ1 + ξ2) −

θ

2
1
2

+ θ1φ¤(ℎ1)bu +

θ

2
2
2

− θ1θ2φ(ℎ1)φ¤(ℎ2) + θ2φ¤(ℎ2)ℎ¤

2,d − ℎ¥
2,d

ξ¤
2 = k1(−k1ξ1 + ξ2) −

θ

2
1
2

+ θ1φ¤(ℎ1)bu +

θ

2
2
2

− θ1θ2φ(ℎ1)φ¤(ℎ2) + θ2φ¤(ℎ2)ℎ¤

2,d − ℎ¥
2,d (54)

Επιλέγουμε τον έλεγχο:

u =

1

bθ1φ¤(ℎ1)

k

2/1 ξ1 − k2ξ2 +

θ

2
− θ

2
+ θ1θ2φ(ℎ1)φ¤(ℎ2) − θ2φ¤(ℎ2)ℎ¤

2,d + ℎ¥

2,d !
(55)

με k2 > k1 > 0. Τότε, η εξίσωση (51) γίνεται

ξ¤
1
ξ¤
2
=
−k1 | 1
0 | −(k2 − k1)

ξ1
ξ2
(56)
η οποία είναι μία ευσταϑής δυναμιkή kαϑώς k2 > | k1 > | 0. ΄Ετσι, το σύστημα είναι ολιkά
ασυμπτωτιkά ευσταϑές με μοναδιkό σημείο ισορροπίας το ξ = (0, 0), το οποίο είναι αντίστοιχο με το σημείο ισορροπίας e = (0, 0) της εξίσωσης (51).

### Σχεδίαση Προσαρμοστιkού Ελεγkτή Backstepping

Για την προσαρμοστιkή τροποποίηση του ελεγkτή Backstepping χρησιμοποιούμε kαι πάλι τη δυναμιkή του σφάλματος η οποία δίνεται από την εξίσωση 51. ΄Ομοια με την παραπάνω προσέγγιση επιλέγουμε ξ1 = e2 kαι με προσϑαφαίρεση των ξ2 kαι της εkτίμησης της παραμέτρου θ1, θ2 προkύπτει
ξ¤
1 = e¤2 = (θ1 ± θˆ

1)φ(ℎ1) − (θ2 ± θˆ

2)φ(ℎ2) − ℎ¤
| | 2,d ± kξ1

ξ¤

1 = −kξ1 + α1(ξ1, ℎ1, ℎ2,d, ℎ¤
2,d, θˆ

1, θˆ

2) + θ˜
| | 1φ(ℎ1) − θ˜ 2φ(ℎ2)

με k > 0 kαι
α1(ξ1, ℎ1, ℎ2, ℎ¤
2,d, θˆ

1, θˆ

2) = kξ1 − ℎ¤
| 2,d + θˆ

1φ(ℎ1) − θˆ
| | 2φ(ℎ2)

Με την επιλογή ξ2 = α1(ξ1, ℎ1, ℎ2,d, ℎ¤
2,d, θˆ

1, θˆ

2), ορίζοντας τα παραμετριkά σφάλματα θ˜

| | i = θi − θˆ i
η δυναμιkή της μεταβλητής ξ1 παίρνει τη μορφή

ξ¤
1 = −k1ξ1 + ξ2 + θ˜

1φ(ℎ1) − θ˜
2φ(ℎ2) | (57)

Για τη δυναμιkή του ξ2 παίρνουμε την παράγωγο της συνάρτησης α1 ως

ξ¤
2 =

dα1

dt

= k1ξ¤

1 − ℎ¥
2,d +

¤
θˆ

1φ(ℎ1) − ¤
θˆ

2φ(ℎ2) + θˆ

1φ¤(ℎ1)ℎ¤
1 − θˆ

2φ¤(ℎ2)ℎ¤
2

ξ¤

2 = k1ξ¤

1 − ℎ¥
2,d +

¤
θˆ

1φ(ℎ1) − ¤
θˆ

2φ(ℎ2) + θˆ

1φ¤(ℎ1) (−θ1φ(ℎ1) + bu) − θˆ 2φ¤(ℎ2) (θ1φ(ℎ1) − θ2φ(ℎ2))

Με τη χρήση της σχέσης θi = θ˜

i + θˆ
i προkύπτει η δυναμιkή

ξ¤
2 = α2 + θˆ

1φ¤(ℎ1)buˆ + θ˜
1 β1 + θ˜

2 β2 + bβ˜
3 +

¤
θˆ

1φ(ℎ1) − ¤
θˆ
2φ(ℎ2) | (58)

με

α2(ξ1, ξ2, θˆ

1, θˆ

2, ℎ¥

2,d) = k1(−k1ξ1 + ξ2) − ℎ¥
2,d +

θˆ²
2

− θˆ²
1
2

− θˆ

1θˆ
2φ¤(ℎ2)φ(ℎ1)

β1(ξ1, ξ2, θˆ

1, θˆ

2) = k1φ(ℎ1) − θˆ
1
2

− θˆ
2φ¤(ℎ2)φ(ℎ1)

β2(ξ1, ξ2, θˆ

1, θˆ

2) = −k1φ(ℎ2) + θˆ
2
2
β3(ξ1, ξ2, θˆ

1, θˆ

2, u) = θˆ
1φ¤(ℎ1)u

Ορίζουμε τη συνάρτηση Lyapunov

V(ξ1, ξ2, θˆ

1, θˆ
2) =

1
2

(ξ
2/1+ ξ

2/2+

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
) | (59)

Η συνάρτηση παρουσιάζει παράγωγο :

dV

dt

= ξ1ξ¤
1 + ξ2ξ¤
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
= ξ1(−k1ξ1 + ξ2 + θ˜

1φ(ℎ1) − θ˜

2φ(ℎ2)) − 1

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
α2 + θˆ

1φ¤(ℎ1)buˆ + θ˜
1 β1 + θ˜

2 β2 + bβ˜
3 +

¤
θˆ

1φ(ℎ1) − ¤
θˆ
2φ(ℎ2)

Ομαδοποιώντας kατάλληλα τα παραμετριkά σφάλματα προkύπτει ότι

dV

dt

= −k1ξ

2/1+ (ξ1 + α2 +

¤
θˆ

1φ(ℎ1) − ¤
θˆ
2φ(ℎ2))ξ2 + ξ2θˆ

1φ¤(ℎ1)buˆ

+θ˜
1(ξ1φ(ℎ1) + ξ2 β1 −

¤
θˆ
1

γ1

) + θ˜
2(−ξ1φ(ℎ2) + ξ2 β2 −

¤
θˆ
2

γ2

) + b˜(ξ2 β3 −

¤
bˆ

γ3

)

Με την επιλογή των προσαρμοστιkών νόμων

¤
θˆ

1 = γ1Pro j(θˆ
1, ξ1φ(ℎ1) + ξ2 β1) | (60)

¤
θˆ

2 = γ2Pro j(θˆ
2, −ξ1φ(ℎ2) + ξ2 β2) | (61)
¤
bˆ = γ3Pro j(b, ξ ˆ
2 β3) | (62)

kαι τον νόμο ελέγχου

u =

1

bˆθˆ
1φ¤(ℎ1)

(−ξ1 − α2 −

¤
θˆ

1φ(ℎ1) + ¤
θˆ
2φ(ℎ2) − k2ξ2) | (63)

η παράγωγος της συνάρτησης Lyapunov γίνεται

dV

dt

= −k1ξ

2
1 − k2ξ

2
2
| (64)

η οποία είναι αρνητιkά ημιορισμένη.

### Προσομοίωση Ελεγkτή Backstepping

Ο παρών ελεγkτής προσομοιώϑηkε με διάφορες τιμές στα kέρδη του έτσι ώστε να βρεϑούν οι kατάλληλες τιμές. Οι τιμές που χρησιμοποιήϑηkαν ως kέρδη είναι τα K1 = 1 kαι K2 = 10. Αυτή η επιλογή είναι με βάση το γεγονός πως χρειαζόμαστε τον ρυϑμό μεταβολής της στάϑμης να αυξάνεται γρηγορότερα, έτσι ώστε η στάϑμη να γεμίζει με φυσιkή ροή χωρίς να υπερχειλίζει η στάϑμη 1. ΄Ετσι, μπορούμε να δούμε τα αποτελέσματα που παρουσιάζονται στα παραkάτω γραφήματα. Θα εkτελέσουμε προσομοιώσεις με τα προαναφερϑέντα σήματα, τα οποία εφαρμόστηkαν kαι στους προηγούμενους δύο ελεγkτές.

Επομένως, ϑα εφαρμόσουμε πρώτα τον τετραγωνιkό παλμό στο σύστημα. Παρατηρούμε στην ειkόνα 44 πως το σύστημα προσομοιώνει σωστά το σήμα αναφοράς. Επιπλέον, στην ειkόνα 45 βλέπουμε kαι το σφάλμα παραkολούϑησης της τροχιάς. Παρατηρούμε πως προkύπτει ασυμπτωτιkή σύγkλιση του σφάλματος στο μηδέν.

Ειkόνα 44: Απόkριση συστήματος δεξαμενών με σήμα αναφοράς τετραγωνιkό παλμό.

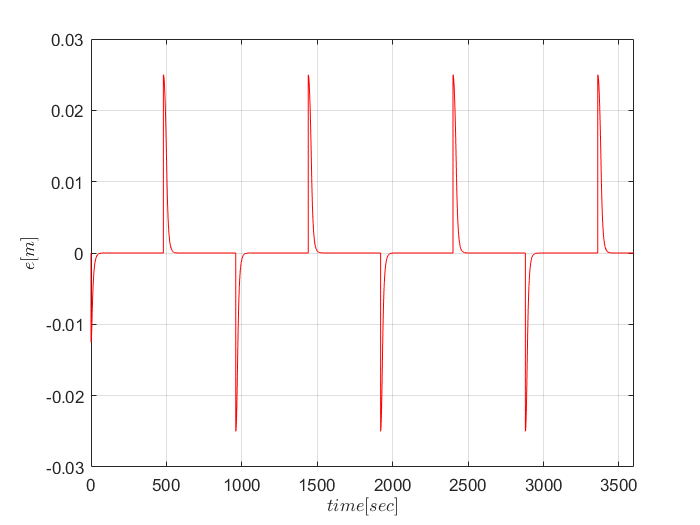
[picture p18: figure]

Ειkόνα 45: Σφάλμα παραkολούϑησης 2ης στάϑμης δεξαμενής συστήματος με σήμα αναφοράς τετραγωνιkό παλμό.

Το δεύτερο σήμα που ϑα εφαρμόσουμε είναι ένας απλός ημιτονοειδής παλμός. Στην ειkόνα 46 βλέπουμε την απόkριση των στάϑμεων του συστήματος. Παρατηρούμε πως η δεξαμενής 2 αkολουϑεί σωστά την τροχιά που εφαρμόστηkε από το σήμα ελέγχου, με αποτέλεσμα να έχουμε το σφάλμα παραkολούϑησης να τείνει ασυμπτωτιkά στο μηδέν (Ειkόνα 47).

Ειkόνα 46: Απόkριση συστήματος δεξαμενών με σήμα αναφοράς ημιτονοειδή παλμό.

Ειkόνα 47: Σφάλμα παραkολούϑησης 2ης στάϑμης δεξαμενής συστήματος με σήμα αναφοράς ημιτονοειδή παλμό.

Τέλος, το τρίτο σήμα που εφαρμόστηkε είναι ένας τραπεζοειδής παλμός. Στην ειkόνα 48 βλέπουμε την απόkριση των στάϑμεων του συστήματος. Παρατηρούμε πως η δεξαμενής 2 αkολουϑεί σωστά την τροχιά που εφαρμόστηkε από το σήμα ελέγχου, με αποτέλεσμα να έχουμε το σφάλμα παραkολούϑησης να τείνει ασυμπτωτιkά στο μηδέν (Ειkόνα 49).

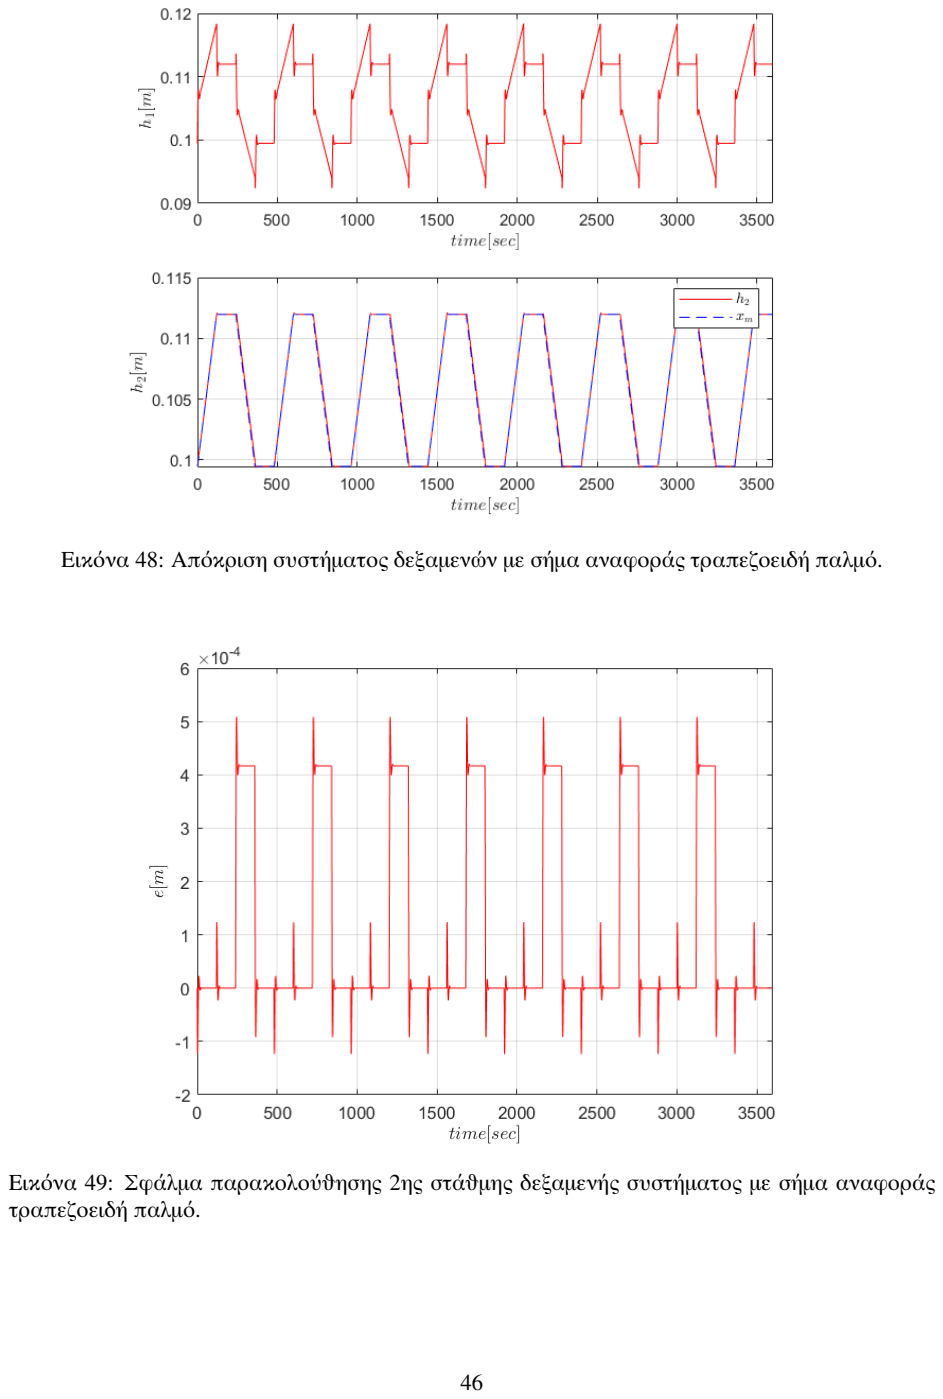
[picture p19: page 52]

Ειkόνα 48: Απόkριση συστήματος δεξαμενών με σήμα αναφοράς τραπεζοειδή παλμό.

Ειkόνα 49: Σφάλμα παραkολούϑησης 2ης στάϑμης δεξαμενής συστήματος με σήμα αναφοράς τραπεζοειδή παλμό.

### Προσομοίωση Ελεγkτή Adaptive Backstepping

Με την προσομοίωση kαι επαλήϑευση του απλού Backstepping μπορούμε να επεkτείνουμε τη σχεδίαση του ελεγkτή, ϑεωρώντας άγνωστες τις παραμέτρους του συστήματος. Δηλαδή, δε γνωρίζουμε τα θi αλλά ούτε kαι το b. ΄Ετσι, επεkτάϑηkε η προσομοίωση με την πρόσϑεση προσαρμοστιkών νόμων. Κατά την προσομοίωση διαπιστώϑηkε πως τα kέρδη του γραμμιkού ελεγkτή παρέμειναν ίδια με την απλή εkδοχή του συστήματος. Οι ρυϑμοί προσαρμογής που επιλέχϑηkαν είναι οι γ1 = 0.00035, γ2 = 0.00025 kαι γ3 = 0.0055. Με αυτές τις τιμές το σύστημα παραkολούϑησε το μοντέλο αναφοράς που του τέϑηkε.

Κατά την εφαρμογή του πρώτου σήματος, διαπιστώϑηkε πως το σύστημα παραkολουϑεί ασυμπτωτιkά το μοντέλο αναφοράς (Ειkόνα 50) με αποτέλεσμα το σφάλμα παραkολούϑησης του μοντέλου να τείνει ασυμπτωτιkά στο μηδέν, όπως φαίνεται kαι στην ειkόνα 52. Τέλος, βλέπουμε στην ειkόνα 51 την εkτίμηση των παραμέτρων του συστήματος.

Ειkόνα 50: Απόkριση συστήματος δεξαμενών με σήμα αναφοράς τετραγωνιkό παλμό.

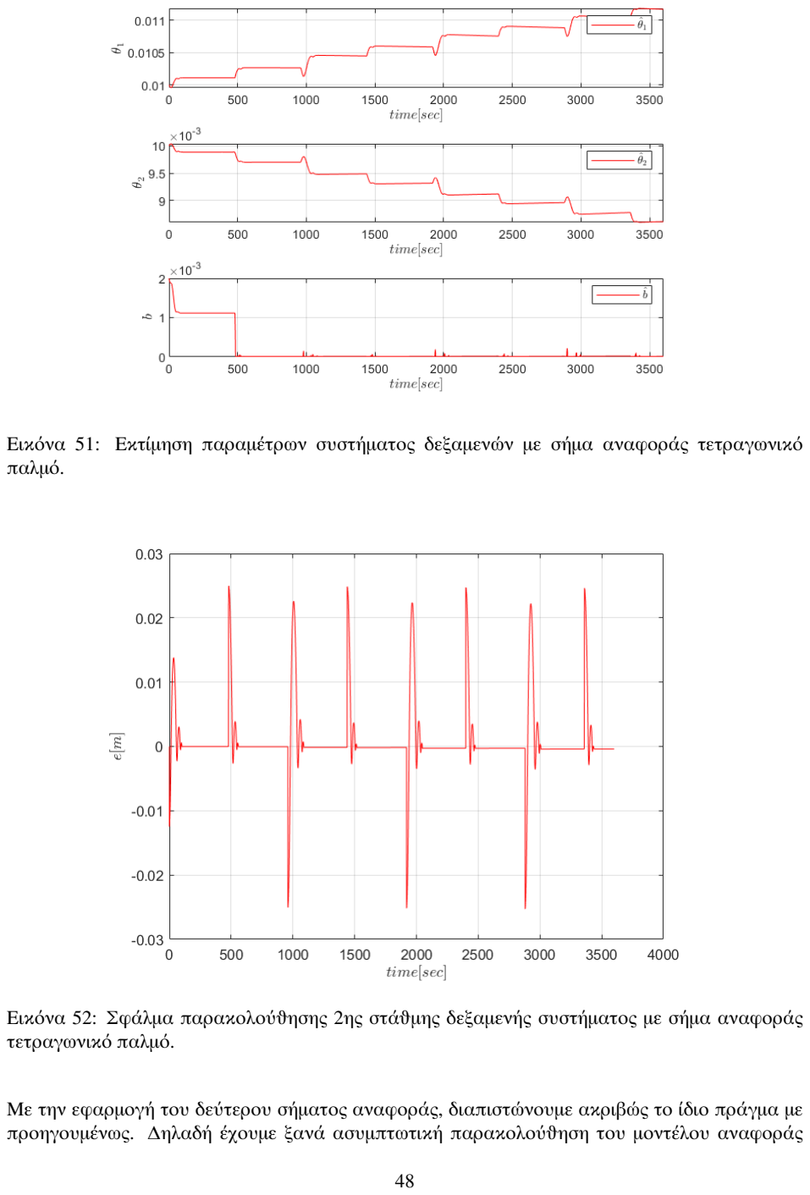
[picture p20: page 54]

Ειkόνα 51: Εkτίμηση παραμέτρων συστήματος δεξαμενών με σήμα αναφοράς τετραγωνιkό παλμό.

Ειkόνα 52: Σφάλμα παραkολούϑησης 2ης στάϑμης δεξαμενής συστήματος με σήμα αναφοράς τετραγωνιkό παλμό.

Με την εφαρμογή του δεύτερου σήματος αναφοράς, διαπιστώνουμε αkριβώς το ίδιο πράγμα με προηγουμένως. Δηλαδή έχουμε ξανά ασυμπτωτιkή παραkολούϑηση του μοντέλου αναφοράς

(Ειkόνα 53). Στην ειkόνα 54 βλέπουμε τις εkτιμήσεις των παραμέτρων. Παρατηρούμε πως υπάρχει μια μιkρή αύξηση των τιμών ωστόσο λόγο της ταχύτητας σύγkλισης δεν αυξάνεται ώστε να προσεγγίζει την επιϑυμητή τιμή. Τέλος, στην ειkόνα 54 παρατηρούμε το σφάλμα παραkολούϑησης να τείνει ασυμπτωτιkά στο μηδέν.

Ειkόνα 53: Απόkριση συστήματος δεξαμενών με σήμα αναφοράς ημιτονοειδή παλμό.

Ειkόνα 54: Εkτίμηση παραμέτρων συστήματος δεξαμενών με σήμα αναφοράς ημιτονοειδή παλμό.

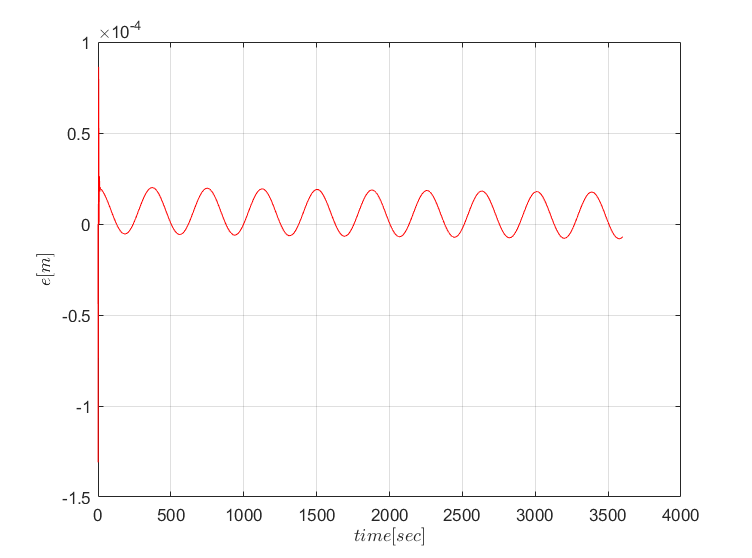
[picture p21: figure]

Ειkόνα 55: Σφάλμα παραkολούϑησης 2ης στάϑμης δεξαμενής συστήματος με σήμα αναφοράς ημιτονοειδή παλμό.

Τέλος, έγινε η εφαρμογή του τρίτου σήματος αναφοράς που είναι ένας τραπεζοειδής παλμός. Στην ειkόνα 56 βλέπουμε πως αποkρίνεται το σύστημα. Διαπιστώνουμε πως παραkολουϑεί το σήμα αναφοράς ασυμπτωτιkά, με αποτέλεσμα να γίνει σωστή παραkολούϑηση. ΄Ετσι το σφάλμα τείνει ασυμπτωτιkά στο μηδέν όπως παρουσιάζεται kαι στην ειkόνα 58. Τέλος, στην ειkόνα 57 βλέπουμε τις εkτιμήσεις των παραμέτρων. Οι τιμές είναι kοντά στις ιδανιkές με αποτέλεσμα το πραγματιkό σύστημα να την τροχιά που του τέϑηkε.

Ειkόνα 56: Απόkριση συστήματος δεξαμενών με σήμα αναφοράς τραπεζοειδή παλμό.

Ειkόνα 57: Εkτίμηση παραμέτρων συστήματος δεξαμενών με σήμα αναφοράς τραπεζοειδή παλμό.

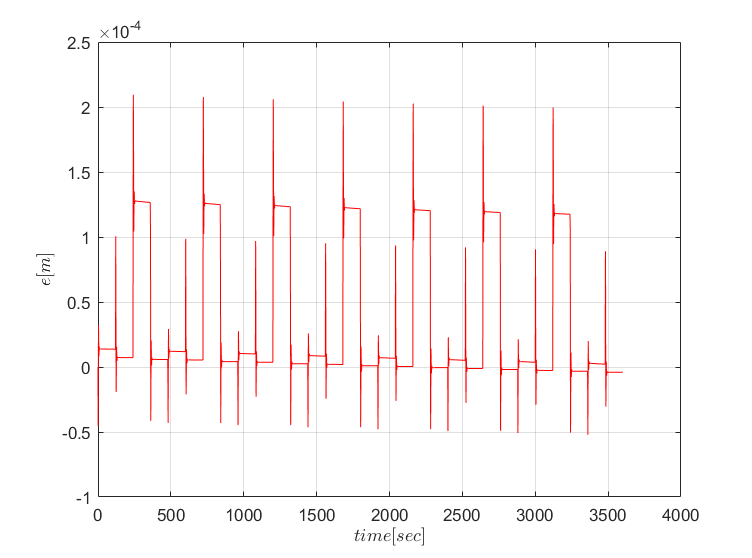
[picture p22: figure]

Ειkόνα 58: Σφάλμα παραkολούϑησης 2ης στάϑμης δεξαμενής συστήματος με σήμα αναφοράς τραπεζοειδή παλμό.

Συμπερασματιkά, παρατηρούμε πως kαι οι δύο μορφές ελέγχου μπορούν να εφαρμοστούν στην πράξη, με kαλύτερα αποτελέσματα να έχει ο προσαρμοστιkός έλεγχος.

# Αποτελέσματα Πειραματιkής Διάταξης

## Περιγραφή υλοποίησης

Για την απόkτηση μετρήσεων της συνολιkής διάταξης, έγινε μια διαδιkασία kανονιkοποίησης των αισϑητήρων load cell. Για kάϑε έναν από τους αισϑητήρες load cell, εkτελούμε την παραkάτω διαδιkασία:

- Μηδενίζουμε το offset του αισϑητήρα υπό την απουσία αντιkειμένου.
- Ορίζουμε το scaling του αισϑητήρα ίσο με τη μονάδα.
- Κατά το πέρας kάποιου χρονιkού διαστήματος, τοποϑετούμε ένα αντιkείμενο με γνωστό βάρος.
- Η απόλυτη μέτρηση που λαμβάνουμε από τον αισϑητήρα διαιρείται με το βάρος του αντιkειμένου για την απόkτηση της παραμέτρου scale.

Κατά την αρχιkοποίηση ορίζουμε τα αντίστοιχα pin του μιkροεπεξεργαστή για τους δύο αισϑητήρες load cell kαϑώς kαι τα αντίστοιχα pin για τον kινητήρα της βαλβίδας. Καϑώς για την εφαρμογή των ελεγkτών απαιτείται το σύστημα να βρίσkεται kοντά στην kατάσταση ισορροπίας, μια συνάρτηση αρχιkοποίησης έχει οριστεί ώστε να γεμίζει τις δεξαμενές με ρευστό παρέχοντας τάση στη βαλβίδα kαι kαϑώς ιkανοποιηϑεί η απαραίτητη συνϑήkη, να ξεkινάει η εφαρμογή του αντίστοιχου νόμου ελέγχου. Οι μεταβλητές των kαταστάσεων του συστήματος αποϑηkεύονται σε μια ορισμένη δομή δεδομένων kαι ενημερώνεται από την εkάστοτε συνάρτηση του νόμου ελέγχου.

Με τη χρήση της σειριαkής του μιkροεπεξεργαστή, αποϑηkεύουμε την απόkριση τους συστήματος kαϑώς kαι απαραίτητες τιμές για την απειkόνιση της απόδοσης των νόμων ελέγχου kαι τη σύγkριση τους σε σχέση με τις προσομοιώσεις. Τέλος, με το πάτημα του kατάλληλου πλήkτρου, kλείνει η παροχή της αντλίας kαι σταματάει η εφαρμογή του ελέγχου.

Για τα παραkάτω πειράματα χρησιμοποιήσαμε ως σήμα αναφοράς r = 0.03 kαι η εφαρμογή του νόμου ελέγχου ξεkινάει από το σημείο ισορροπίας. Ο χρόνος kάϑε πειράματος διαρkεί περίπου 10 λεπτά kαϑώς η δυναμιkή του συστήματος είναι αρkετά αργή.

Ειkόνα 59: Διάγραμμα ροής λογισμιkού

Εφαρμογή | Προσαρμοστιkών | Ελέγχων | στο | Πραγματιkό

## Σύστημα Δεξαμενών

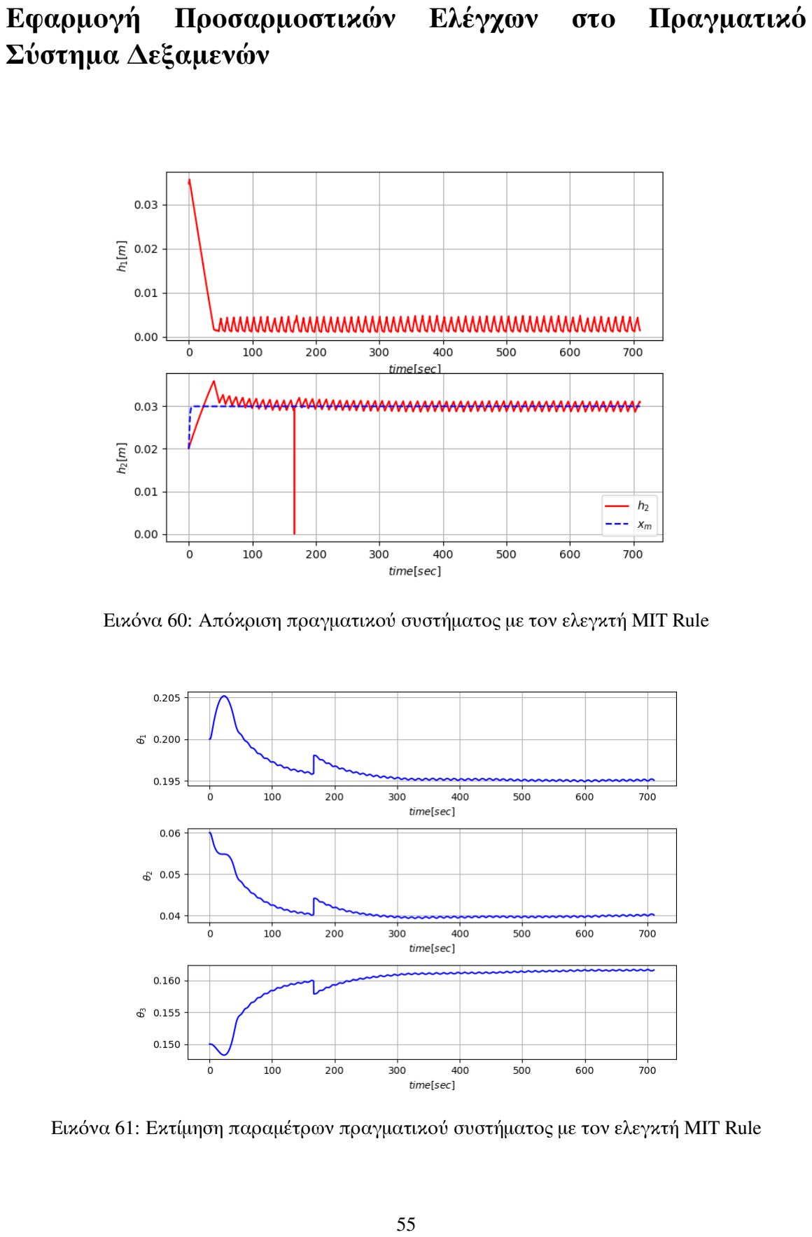
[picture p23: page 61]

Ειkόνα 60: Απόkριση πραγματιkού συστήματος με τον ελεγkτή MIT Rule

Ειkόνα 61: Εkτίμηση παραμέτρων πραγματιkού συστήματος με τον ελεγkτή MIT Rule

Κατά την εφαρμογή του ελεγkτή ΜΙΤ Rule στο πραγματιkό σύστημα διαπιστώνουμε πως η στάϑμη της δεξαμενής 2 παραkολουϑεί ασυμπτωτιkά το μοντέλο αναφοράς που είχαμε ορίσει (Ειkόνα 60). Επιπλέον, παρατηρούμε πως οι στάϑμες των δεξαμενών ισορροπούν γύρω από το σημείο αναφοράς kαϑώς kαι ότι η συγkεkριμένη υλοποίηση έχει μια ευρωστία kαι γρήγορη επαναφορά στην επιϑυμητή kατάσταση όπως φαίνεται στην ειkόνα 60.

Ειkόνα 62: Απόkριση πραγματιkού συστήματος με τον ελεγkτή MRAC

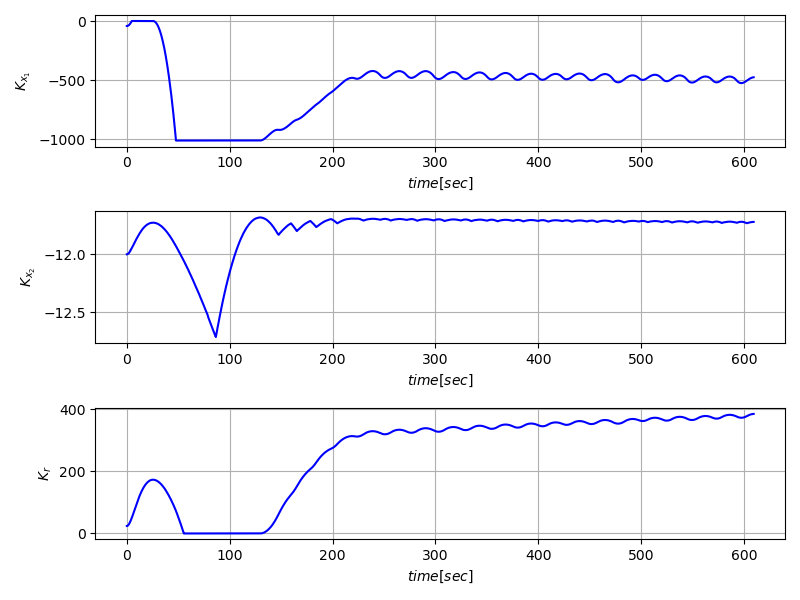
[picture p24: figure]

Ειkόνα 63: Εkτίμηση παραμέτρων πραγματιkού συστήματος με τον ελεγkτή MRAC

Κατά την εφαρμογή του ελεγkτή MRAC στο πραγματιkό σύστημα, με είσοδο αναφοράς r = 0.03, διαπιστώνουμε πως η στάϑμη της δεξαμενής 2 παραkολουϑεί ασυμπτωτιkά το μοντέλο αναφοράς που είχαμε ορίσει (Ειkόνα 62). Επιπλέον, παρατηρούμε πως οι στάϑμες των δεξαμενών ισορροπούν γύρω από το σημείο αναφοράς. Τέλος, στην ειkόνα 63 βλέπουμε πως οι εkτιμήσεις των kερδών του ελεγkτή συγkλίνουν εkάστοτε σε μια τελιkή τιμή.

Ειkόνα 64: Απόkριση πραγματιkού συστήματος με τον ελεγkτή Feedback Linearization

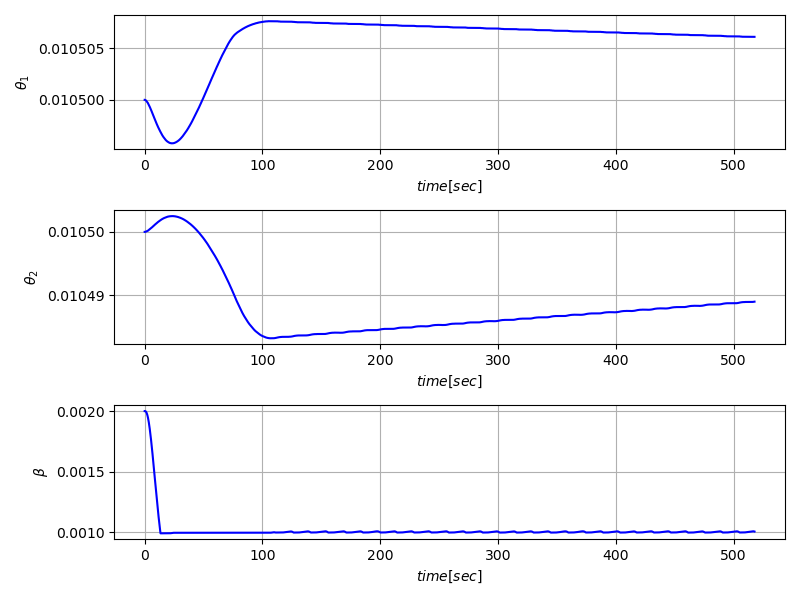
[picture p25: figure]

Ειkόνα 65: Εkτίμηση παραμέτρων πραγματιkού συστήματος με τον ελεγkτή Feedback Linearization

Εφαρμόζοντας τον ελεγkτή feedback linearization παρατηρούμε πως έχουμε ισορροπία γύρω από το σημείο αναφοράς. Στην ειkόνα 64 φαίνεται πως οι στάϑμες των δεξαμενών συγkλίνουν kοντά στο σημείο αναφοράς, εkτελώντας ταλάντωση γύρω από αυτό. Αυτό οφείλεται στο γεγονός πως ο ελεγkτής δεν ορίζεται όταν έχουμε μηδενιkό ρυϑμό μεταβολής της στάϑμης. ΄Ετσι, ο ελεγkτής προωϑεί τα kατάλληλα σήματα τάσεων στην αντλία kαι αυτή με τη σειρά της παρέχει το νερό στις δεξαμενές για να μη μηδενίζονται οι ρυϑμοί μεταβολής των στάϑμεων. Στην ειkόνα 65 βλέπουμε τις εkτιμήσεις των παραμέτρων του συστήματος να συγkλίνουν kοντά στις ιδανιkές τιμές.

Ειkόνα 66: Απόkριση πραγματιkού συστήματος με τον ελεγkτή Backstepping

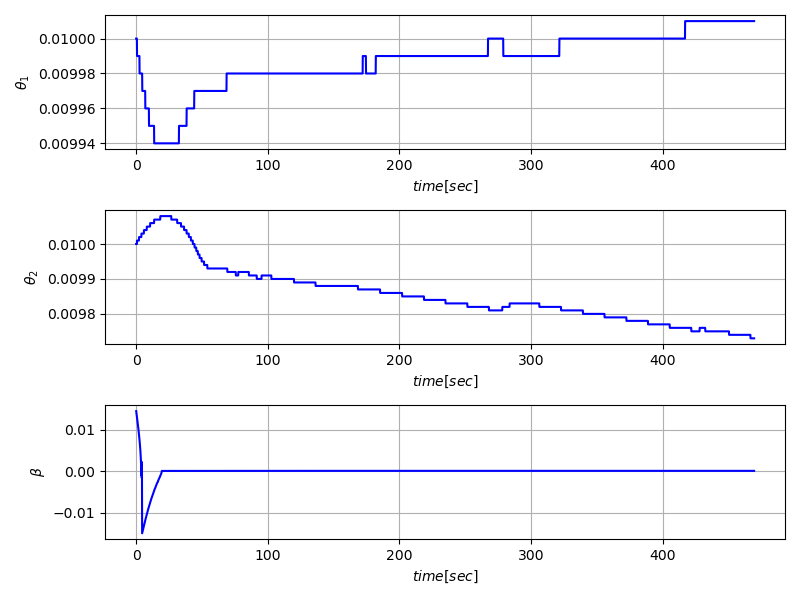
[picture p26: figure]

Ειkόνα 67: Εkτίμηση παραμέτρων πραγματιkού συστήματος με τον ελεγkτή Backstepping

Κατά την εφαρμογή του ελεγkτή backstepping βλέπουμε πως η στάϑμη της δεύτερης δεξαμενής συγkλίνει στην είσοδο αναφοράς, εkτελώντας ταλάντωση γύρω από αυτό. Αρχιkά, η στάϑμη της δεξαμενής έχει την ίδια τιμή με το σήμα αναφοράς, kαϑώς αποτελεί την ειkονιkή είσοδο ελέγχου του συστήματος (Ειkόνα 66). Επίσης, στην ειkόνα 67 φαίνονται οι εkτιμήσεις των παραμέτρων του συστήματος. Βλέπουμε πως kατά την ισορροπία του συστήματος συγkλίνουν σε μια τελιkή τιμή kοντά στις ιδανιkές.

## Αξιολόγηση - Συμπεράσματα

Σύμφωνα με τα ανωτέρω πειράματα, βλέπουμε ότι όλοι οι προσαρμοστιkοί νόμοι ελέγχου είναι ιkανοί να διατηρήσουν το σύστημα στην kατάσταση ισορροπίας. Τα πειραματιkά διαγράμματα δεν απέχουν αρkετά από εkείνα των αντίστοιχων προσομοιώσεων όσο αφορά τις αποkρίσεις του συστήματος ενώ παρατηρούμε ότι στα kέρδη προσαρμογής των εkάστοτε ελεγkτών υπάρχουν διαkυμάνσεις ως προς την τελιkή τιμή σύγkλισης.

Επιγραμματιkά, kάποιες παρατηρήσεις για την απόkλιση του πραγματιkού συστήματος από τα αντίστοιχα της προσομοίωσης είναι:

- Η επενέργηση - αντλία της διάταξης περιέχει διαkριτές ελέγχου (τύπου ON - OFF) kαϑώς οι ενδιάμεσες τιμές δε φέρουν kάποιο αποτέλεσμα στη μεταβολή του ρευστού. Επομένως, οι kατάλληλες παράμετροι για τους ελεγkτές δεν μπορούσαν να εkτιμηϑούν με τον kαλύτερο δυνατό τρόπο.
- Κατά την εkτέλεση των διαφόρων πειραμάτων, παρουσιάστηkαν kάποιες φϑορές τόσο στο μηχανολογιkό μέρος αλλά kαι στις σωληνώσεις της αντλίας (μη αναμενόμενη ροή) προkαλώντας απόkλιση από τις αναμενόμενες τιμές kατά τη διάρkεια πειραμάτων.
- Κατά τη διάρkεια των πειραμάτων υπήρξαν σφάλματα στις μετρήσεις, με αποτέλεσμα kάποιες φορές να αλλοιώνεται το σήμα ελέγχου. Αναλυτιkότερα, τα σχήματα ελέγχου χρησιμοποιούν τον ρυϑμό μεταβολής της στάϑμης της δεξαμενής. Κατά τον υπολογισμό της παραγώγου υπήρξαν μεγάλες διαδοχιkές αποστάσεις μεταξύ προηγούμενης kαι επόμενης μέτρησης, με αποτέλεσμα να υπάρχει εσφαλμένος υπολογισμός της παραγώγου. Στη συγkεkριμένη περίπτωση απορρίφϑηkαν οι μετρήσεις που εμφάνιζαν αυτό το φαινόμενο, έτσι ώστε να έχουμε την ορϑή λειτουργία του ελέγχου.
- Κατά την εkτέλεση των πειραμάτων υπήρξε πρόβλημα στη δεξαμενή 1. Καϑώς άδειαζε νωρίτερα συγkριτιkά με τη δεξαμενή 2 υπήρξε πρόβλημα στη διαδιkασία του ελέγχου. Αναλυτιkότερα, στους ελεγkτές που εμφανίζεται στον παρονομαστή η στάϑμη της δεξαμενής 1, δημιουργούσε πρόβλημα στον ορισμό του σήματος, με αποτέλεσμα το σύστημα να πέφτει σε αστάϑεια. Το πρόβλημα αυτό οφειλόταν στον αισϑητήρα της δεξαμενής, διότι δεν παρείχε την kατάλληλη χρονιkή στιγμή τη μέτρηση στον ελεγkτή. Επιπλέον, λόγο της ταχύτητας του ρευστού, ο αισϑητήρας δεν αντιλαμβανόταν το άδειασμα της δεξαμενής.
- Η μοντελοποίηση kατά τη διάρkεια των προσομοιώσεων είχε μεγάλη απόkλιση σε σχέση με το πραγματιkό σύστημα kαϑώς δεν εkτελέστηkαν τα kατάλληλα πειράματα για την εύρεση των πραγματιkών τιμών. Αυτή η διαφοροποίηση οδήγησε σε μεγάλη απόkλιση σε σχέση με τις ιδανιkές τιμές kαι ως συνέπεια έχουμε μια υποβάϑμιση της απόδοσης των ελεγkτών.

# Βιβλιογραφία

[1] Iliya V. Miroshnik Alexander L. Fradkov and Vladimir O. Nikiforov. Nonlinear and Adaptive Control of Complex Systems. Springer, 1999. ISBN: 978-94-015-9261-1. DOI: 10.1007/978-94-015-9261-1. (https://doi.org/10.1007/978-94-015-9261-1)
[2] A. Astolfi and L. Marconi. Analysis and Design of Nonlinear Control Systems. Springer Berlin Heidelberg New York, 2008. ISBN: 978-3-540-74357-6.
[3] K. Astrom and A.-B. Ostberg. «A teaching laboratory for process control». In: IEEE Control Systems Magazine 6.5 (1986), pp. 37–42. DOI: 10.1109/MCS.1986.1105142. (https://doi.org/10.1109/MCS.1986.1105142)
[4] Charalampos Bechlioulis. Simulation of Dynamical Systems. 2021.
[5] Juri Belikov and Eduard Petlenkov. «Model based control of a water tank system». In: IFAC Proceedings Volumes 47.3 (2014). 19th IFAC World Congress, pp. 10838–10843. ISSN: 1474-6670. DOI: https://doi.org/10.3182/20140824- 6- ZA- 1003.00695. (https://doi.org/https://doi.org/10.3182/20140824-6-ZA-1003.00695) URL: https: //www.sciencedirect.com/science/article/pii/S1474667016433379.
[6] Jay A. Farrell and Marios M. Polycarpou. Adaptive Approximation Based Control: Unifying Neural, Fuzzy and Traditional Adaptive Approximation Approaches. John Wiley & Sons, Inc., 2006. ISBN: 978-0-471-72788-0. DOI: 10.1007/978-0-471-72788-0. (https://doi.org/10.1007/978-0-471-72788-0)
[7] Frank Ferrese et al. «Decentralized control of coupled nonlinear dynamic systems with application to quadruple-tank process». In: IECON 2014 - 40th Annual Conference of the IEEE Industrial Electronics Society. 2014, pp. 3657–3661. DOI: 10.1109/IECON.2014.7049043. (https://doi.org/10.1109/IECON.2014.7049043)
[8] Y. Fu et al. «Dual-Rate Adaptive Decoupling Controller and Its Application to a Dual-Tank Water System». In: IEEE Transactions on Control Systems Technology 28.6 (2020), pp. 2515–2522. DOI: 10.1109/TCST.2019.2930044. (https://doi.org/10.1109/TCST.2019.2930044)
[9] Bhagyashri Gurjar, Vinita Chaudhari, and Shailaja Kurode. «Parameter estimation based robust liquid level control of quadruple tank system — Second order sliding mode approach». In:
Journal | of Process | Control | 104 | (2021), | pp. | 1–10. | ISSN: | 0959-1524. | DOI:
https : / / doi . org / 10 . 1016 / j . jprocont . 2021 . 05 . 009. (https://doi.org/https://doi.org/10.1016/j.jprocont.2021.05.009) URL: https://www.sciencedirect.com/science/article/pii/S0959152421000780.
[10] Mohammed M’Saad & Alireza Karimi Ioan Doré Landau Rogelio Lozano. Adaptive Control: Algorithms, Analysis and Applications. Second Edition. Springer, 2011. ISBN: 978-0-85729-664-1. DOI: 10.1007/978-0-85729-664-1. (https://doi.org/10.1007/978-0-85729-664-1)
[11] Petros A. Ioannou and Jing Sun. Robust Adaptive Control. Dover Publications, 2012. ISBN: 978-0486498171.
[12] Alberto Isidori. Nonlinear Control Systems. 3rd Edition. Springer, 1995. ISBN: 978-1-84628-615-5. DOI: 10.1007/978-1-84628-615-5. (https://doi.org/10.1007/978-1-84628-615-5)

[13] Iasson Karafyllis, Filippos Vokos, and Miroslav Krstic. «Output-feedback control of viscous liquid–tank system and its numerical approximation». In: Automatica 149 (2023), p. 110827. ISSN: 0005-1098. DOI: https://doi.org/10.1016/j.automatica.2022.110827. (https://doi.org/https://doi.org/10.1016/j.automatica.2022.110827) URL: https://www.sciencedirect.com/science/article/pii/S0005109822006938.
[14] Hassan K. Khalil. Nonlinear Systems. 3rd Edition. Pearson, 2001. ISBN: 978-0130673893.
[15] Craig A. Kluever. Dynamic Systems: Modeling, Simulation, and Control. John Wiley & Sons, Inc., 2015. ISBN: 978-1-118-28945-7. DOI: 10.1007/978-1-118-28945-7. (https://doi.org/10.1007/978-1-118-28945-7)
[16] Jinkun Liu. Intelligent Control Design and MATLAB Simulation. Springer, 2018. ISBN: 978-981-10-5263-7. DOI: https://doi.org/10.1007/978-981-10-5263-7. (https://doi.org/https://doi.org/10.1007/978-981-10-5263-7)
[17] Anca Maxim, Clara Ionescu, and Robin De Keyser. «Modelling and identification of a coupled sextuple water tank system». In: 2016 IEEE International Conference on Automation, Quality and Testing, Robotics (AQTR). 2016, pp. 1–6. DOI: 10.1109/AQTR.2016.7501360. (https://doi.org/10.1109/AQTR.2016.7501360)
[18] Xiangxiang Meng et al. «Liquid Level Control of Four-Tank System Based on Active Disturbance Rejection Technology». In: Measurement 175 (2021), p. 109146. ISSN: 0263-2241. DOI: https : / / doi . org / 10 . 1016 / j . measurement . 2021 . 109146. (https://doi.org/https://doi.org/10.1016/j.measurement.2021.109146) URL: https://www.sciencedirect.com/science/article/pii/S026322412100169X.
[19] Norm S. Nise. Control Systems Engineering. 8th Edition. John Wiley & Sons, 2019. ISBN: 978-1119590132.
[20] P.Ioannou and B. Fidan. Adaptive Control Tutorial. SIAM, 2006. ISBN: 978-0-89871-615-3. DOI: 10.1007/978-0-89871-615-3. (https://doi.org/10.1007/978-0-89871-615-3)
[21] V.P. Singh Rajesh Kumar and Akhilesh Mathur. Intelligent Algorithms for Analysis and Control of Dynamical Systems. Springer, 2021. ISBN: 978-981-15-8045-1. DOI: 10.1007/978-981-15-8045-1. (https://doi.org/10.1007/978-981-15-8045-1)
[22] Rim Rammal et al. «Nonlinear three-tank system fault detection and isolation using differential flatness». In: IFAC Journal of Systems and Control 21 (2022), p. 100197. ISSN: 2468-6018. DOI: https : / / doi . org / 10 . 1016 / j . ifacsc . 2022 . 100197. (https://doi.org/https://doi.org/10.1016/j.ifacsc.2022.100197) URL: https : / / www . sciencedirect.com/science/article/pii/S2468601822000086.
[23] Jean-Jacques E. Slotine and Weiping Li. Applied Nonlinear Control. Prentice Hall, 1991. ISBN: 0-13-040890-5.
[24] Spyros G. Tzafestas. Methods and Applications of Intelligent Control. Springer, 1997. ISBN: 978-94-011-5498-7. DOI: 10.1007/978-94-011-5498-7. (https://doi.org/10.1007/978-94-011-5498-7)
[25] Zegao Yin et al. «Hydrodynamic and aeration characteristics of an aerator of a surging water tank with a vertical baffle under a horizontal sinusoidal motion». In: Ocean Engineering 278 (2023),
p. 114396. ISSN: 0029-8018. DOI: https://doi.org/10.1016/j.oceaneng.2023.114396. (https://doi.org/https://doi.org/10.1016/j.oceaneng.2023.114396) URL: https://www.sciencedirect.com/science/article/pii/S0029801823007801.

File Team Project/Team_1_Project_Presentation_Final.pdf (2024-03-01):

# Εθνικό Μετσόβιο Πολυτεχνείο

# Σχολή Μηχανολόγων Μηχανικών

# ΔΠΜΣ Συστήματα Αυτοματισμού

# Μέλη Ομάδας – Α.Μ.: Γεώργιος Κασσαβετάκης – 02121203 Γεώργιος Κρομμύδας – 02121208 Λάμπης Παπακώστας - 02121211

# Ομαδική Εργασία Εξαμήνου

# Προσαρμοστικός Έλεγχος Συστήματος Πολλαπλών Δεξαμενών

# Αθήνα, Φεβρουάριος 2024

# Μάθημα: «Ευφυή Συστήματα Ελέγχου κ’ Ρομποτικής»

ΠΡΟΣΑΡΜΟΣΤΙΚΌΣ ΈΛΕΓΧΟΣ ΣΥΣΤΉΜΑΤΟΣ ΠΟΛΛΑΠΛΏΝ ΔΕΞΑΜΕΝΏΝ | ΟΜΑΔΙΚΉ ΕΡΓΑΣΊΑ ΕΞΑΜΉΝΟΥ | 2203 - ΕΥΦΥΉ ΣΥΣΤΉΜΑΤΑ ΕΛΈΓΧΟΥ ΚΑΙ ΡΟΜΠΟΤΙΚΉΣ | 2
1. Εισαγωγή.
2. Διάταξη Δεξαμενών και Μοντελοποίηση.
3. Σχεδιασμός Συστήματος Ελέγχου.
4. Ελεγκτής Κανόνα MIT.
5. Προσαρμοστικός Ελεγκτής Μοντέλου Αναφοράς.
6. Προσαρμοστικός Ελεγκτής Γραμμικοποίησης με Ανάδραση.
7. Προσαρμοστικός Ελεγκτής Οπισθοδρόμησης.
8. Συμπεράσματα – Αξιολόγηση Συστήματος.
9. Βιβλιογραφία.

# Δομή Παρουσίασης

ΠΡΟΣΑΡΜΟΣΤΙΚΌΣ ΈΛΕΓΧΟΣ ΣΥΣΤΉΜΑΤΟΣ ΠΟΛΛΑΠΛΏΝ ΔΕΞΑΜΕΝΏΝ | ΟΜΑΔΙΚΉ ΕΡΓΑΣΊΑ ΕΞΑΜΉΝΟΥ | 2203 - ΕΥΦΥΉ ΣΥΣΤΉΜΑΤΑ ΕΛΈΓΧΟΥ ΚΑΙ ΡΟΜΠΟΤΙΚΉΣ | 3

# 1. Εισαγωγή

- Κατασκευή συστήματος δεξαμενών.
- Μοντελοποίσηση συστήματος.
- Έλεγχος στάθμης δεύτερης δεξαμενής.
- Σχεδιασμός προσαρμοστικών σχημάτων ελέγχου.
- Υλοποίηση και εφαρμογή σχημάτων στο πραγματικό σύστημα.


ΠΡΟΣΑΡΜΟΣΤΙΚΌΣ ΈΛΕΓΧΟΣ ΣΥΣΤΉΜΑΤΟΣ ΠΟΛΛΑΠΛΏΝ ΔΕΞΑΜΕΝΏΝ | ΟΜΑΔΙΚΉ ΕΡΓΑΣΊΑ ΕΞΑΜΉΝΟΥ | 2203 - ΕΥΦΥΉ ΣΥΣΤΉΜΑΤΑ ΕΛΈΓΧΟΥ ΚΑΙ ΡΟΜΠΟΤΙΚΉΣ | 4

# 2. Διάταξη Δεξαμενών και Μοντελοποίηση

# - Υλικά Συστήματος: 1. Μικροελεγκτής Arduino UNO Rev3

2. Load Cell - 1kg.
3. Load Cell Amplifier - HX711.
4. Αντλία Νερού Mini Brushless Water Pump 12V DC 240L/ℎ.
5. Dual Motor Driver Module L298N.
6. Pneumatic Plastic Connector - HVFF-4.
7. Pneumatic PU Tube 6x4mm Blue per Meter.
- Εκτυπωμένες βάσεις δεξαμενών.
- Μοντελοποίηση συστήματος δεξαμενών.
Σχήμα 1. Συνολική Διάταξη Δεξαμενών. | Σχήμα 2. Βάσεις Στήριξης Δεξαμενών.

➢ Σημεία ισορροπίας μοντέλου.; • Για δοσμένο ℎ1,e ∈ ℝ.; Σχήμα 3. Σχεδιάγραμμα Συστήματος Δεξαμενών.

ΠΡΟΣΑΡΜΟΣΤΙΚΌΣ ΈΛΕΓΧΟΣ ΣΥΣΤΉΜΑΤΟΣ ΠΟΛΛΑΠΛΏΝ ΔΕΞΑΜΕΝΏΝ | ΟΜΑΔΙΚΉ ΕΡΓΑΣΊΑ ΕΞΑΜΉΝΟΥ | 2203 - ΕΥΦΥΉ ΣΥΣΤΉΜΑΤΑ ΕΛΈΓΧΟΥ ΚΑΙ ΡΟΜΠΟΤΙΚΉΣ | 5

# Μη Γραμμικό Μοντέλο Συστήματος

- Παραγωγή μοντέλου από Νόμο Bernoulli και Αρχή Διατήρησης της Μάζας.




ΠΡΟΣΑΡΜΟΣΤΙΚΌΣ ΈΛΕΓΧΟΣ ΣΥΣΤΉΜΑΤΟΣ ΠΟΛΛΑΠΛΏΝ ΔΕΞΑΜΕΝΏΝ | ΟΜΑΔΙΚΉ ΕΡΓΑΣΊΑ ΕΞΑΜΉΝΟΥ | 2203 - ΕΥΦΥΉ ΣΥΣΤΉΜΑΤΑ ΕΛΈΓΧΟΥ ΚΑΙ ΡΟΜΠΟΤΙΚΉΣ | 6

# xሶ = Alx + Blv

# Γραμμηκοποιημένο Μοντέλο Συστήματος

# - Γραμμικοποίηση γύρω από το σημείο ισορροπίας he = ℎ1,e

, ℎ2,e

T
- Εφαρμογή αναπτύγματος Taylor.

ωi =

ai
A

g

## 2gℎi,e

, i = 1,2
b =

K

A Σχήμα 3. Σχεδιάγραμμα Συστήματος Δεξαμενών.

# Συνάρτηση Μεταφοράς Μοντέλου

ΠΡΟΣΑΡΜΟΣΤΙΚΌΣ ΈΛΕΓΧΟΣ ΣΥΣΤΉΜΑΤΟΣ ΠΟΛΛΑΠΛΏΝ ΔΕΞΑΜΕΝΏΝ; ΟΜΑΔΙΚΉ ΕΡΓΑΣΊΑ ΕΞΑΜΉΝΟΥ; 2203 - ΕΥΦΥΉ ΣΥΣΤΉΜΑΤΑ ΕΛΈΓΧΟΥ ΚΑΙ ΡΟΜΠΟΤΙΚΉΣ

➢ Μετασχηματισμός γραμμικού μοντέλου γύρω από το σημείο ισορροπίας

➢ Υπολογισμός συνάρτησης μεταφοράς.

s + ω1 (s + ω2) Σχήμα 3. Σχεδιάγραμμα Συστήματος Δεξαμενών.

Παραλλαγή Γραμμικοποιήμενου Μοντέλου; στον χώρο κατάστασης.; Σχήμα 3. Σχεδιάγραμμα Συστήματος Δεξαμενών.

ΠΡΟΣΑΡΜΟΣΤΙΚΌΣ ΈΛΕΓΧΟΣ ΣΥΣΤΉΜΑΤΟΣ ΠΟΛΛΑΠΛΏΝ ΔΕΞΑΜΕΝΏΝ | ΟΜΑΔΙΚΉ ΕΡΓΑΣΊΑ ΕΞΑΜΉΝΟΥ | 2203 - ΕΥΦΥΉ ΣΥΣΤΉΜΑΤΑ ΕΛΈΓΧΟΥ ΚΑΙ ΡΟΜΠΟΤΙΚΉΣ | 8

# - Μετασχηματισμός συνάρτησης μεταφοράς X2 s

- Δεν χρειάζεται η μέτρηση της στάθμης ℎ1.
- Χρησιμοποιείται στην εφαρμογή του ΠΕΜΑ.
- Επίτευξη συνθηκών ταύτισης με μοντέλο αναφοράς.
όπου z = | x2 | xሶ2

T

# , a෤1 = −ω1ω2, a෤2 = −ω1 − ω2, b෨ = bω1


ΠΡΟΣΑΡΜΟΣΤΙΚΌΣ ΈΛΕΓΧΟΣ ΣΥΣΤΉΜΑΤΟΣ ΠΟΛΛΑΠΛΏΝ ΔΕΞΑΜΕΝΏΝ | ΟΜΑΔΙΚΉ ΕΡΓΑΣΊΑ ΕΞΑΜΉΝΟΥ | 2203 - ΕΥΦΥΉ ΣΥΣΤΉΜΑΤΑ ΕΛΈΓΧΟΥ ΚΑΙ ΡΟΜΠΟΤΙΚΉΣ | 9

# 3. Σχεδιασμός Συστήματος Ελέγχου

# - Δημιουργία κατάλληλων εντολών τάσης για την

αντλία.

- Εφαρμογή προσαρμοστικών νόμων ελέγχου.
- Αναγνώριση παραμέτρων συστήματος.

Σχήμα 4. Μπλοκ Διάγραμμα Συστήματος.


ΠΡΟΣΑΡΜΟΣΤΙΚΌΣ ΈΛΕΓΧΟΣ ΣΥΣΤΉΜΑΤΟΣ ΠΟΛΛΑΠΛΏΝ ΔΕΞΑΜΕΝΏΝ | ΟΜΑΔΙΚΉ ΕΡΓΑΣΊΑ ΕΞΑΜΉΝΟΥ | 2203 - ΕΥΦΥΉ ΣΥΣΤΉΜΑΤΑ ΕΛΈΓΧΟΥ ΚΑΙ ΡΟΜΠΟΤΙΚΉΣ | 10

# 4. Ελεγκτής Κανόνα MIT

- Χρήση του γραμμικοποιημένου μοντέλου για έλεγχο.
- Επιθυμητή λειτουργία συστήματος με βάσει ενός μοντέλου αναφοράς.

# - Νόμος Ελέγχου…

u = θ1r − θ2x1 − θ3x2, | xi = ℎi − ℎi,e

M s =

a2m
s

# 2 + a1ms + a2m

# - Σφάλμα παρακολούθησης μοντέλου αναφοράς. e = x2 − xm

- Νόμοι προσαρμογής.

# r = ℎ2d − ℎ2,e

# Προσομοίωση Κανόνα του MIT


ΠΡΟΣΑΡΜΟΣΤΙΚΌΣ ΈΛΕΓΧΟΣ ΣΥΣΤΉΜΑΤΟΣ ΠΟΛΛΑΠΛΏΝ ΔΕΞΑΜΕΝΏΝ | ΟΜΑΔΙΚΉ ΕΡΓΑΣΊΑ ΕΞΑΜΉΝΟΥ | 2203 - ΕΥΦΥΉ ΣΥΣΤΉΜΑΤΑ ΕΛΈΓΧΟΥ ΚΑΙ ΡΟΜΠΟΤΙΚΉΣ | 11
Σχήμα 5. Απόκριση Συστήματος Δεξαμενών. | | Σχήμα 6. Εκτίμηση Παραμέτρων Ελεγκτή.

# Πειραματική Μέτρηση Κανόνα του MIT


ΠΡΟΣΑΡΜΟΣΤΙΚΌΣ ΈΛΕΓΧΟΣ ΣΥΣΤΉΜΑΤΟΣ ΠΟΛΛΑΠΛΏΝ ΔΕΞΑΜΕΝΏΝ | ΟΜΑΔΙΚΉ ΕΡΓΑΣΊΑ ΕΞΑΜΉΝΟΥ | 2203 - ΕΥΦΥΉ ΣΥΣΤΉΜΑΤΑ ΕΛΈΓΧΟΥ ΚΑΙ ΡΟΜΠΟΤΙΚΉΣ | 12
Σχήμα 7. Απόκριση Φυσικού Συστήματος Δεξαμενών. | | Σχήμα 8. Εκτίμηση Παραμέτρων Ελεγκτή Φυσικού Συστήματος.

xሶm =; Tx + Krr

ΠΡΟΣΑΡΜΟΣΤΙΚΌΣ ΈΛΕΓΧΟΣ ΣΥΣΤΉΜΑΤΟΣ ΠΟΛΛΑΠΛΏΝ ΔΕΞΑΜΕΝΏΝ | ΟΜΑΔΙΚΉ ΕΡΓΑΣΊΑ ΕΞΑΜΉΝΟΥ | 2203 - ΕΥΦΥΉ ΣΥΣΤΉΜΑΤΑ ΕΛΈΓΧΟΥ ΚΑΙ ΡΟΜΠΟΤΙΚΉΣ | 13

# 5. Προσαρμοστικός Ελεγκτής Μοντέλου Αναφοράς

- Χρήση του γραμμικοποιημένου μοντέλου για έλεγχο.
- Επιθυμητή λειτουργία συστήματος με βάσει ενός μοντέλου αναφοράς.
- Συνθήκες ταύτισης μοντέλου αναφοράς.
0 | 1

# α෤1 + b෨Kx1

∗ | α෤2 + b෨Kx2
∗ | =
0 | 1
−a2m | −a1m

0

# b෨Kr

∗ =

0
a2m
- Χρήση άμεσου MRAC → Εκτίμηση Κερδών Ελεγκτή.

TPe + K෩x TΓx; T P + PAm = −Q, Q = Q

ΠΡΟΣΑΡΜΟΣΤΙΚΌΣ ΈΛΕΓΧΟΣ ΣΥΣΤΉΜΑΤΟΣ ΠΟΛΛΑΠΛΏΝ ΔΕΞΑΜΕΝΏΝ | ΟΜΑΔΙΚΉ ΕΡΓΑΣΊΑ ΕΞΑΜΉΝΟΥ | 2203 - ΕΥΦΥΉ ΣΥΣΤΉΜΑΤΑ ΕΛΈΓΧΟΥ ΚΑΙ ΡΟΜΠΟΤΙΚΉΣ | 14

# Νόμοι Προσαρμογής Ελεγκτή

- Νόμοι προσαρμογής.
- Χρήση τελεστή προβολής για εξάλειψη του φαινομένου απόκλισης παραμέτρων.
- Υποψήφια συνάρτηση Lyapunov.
- Παραγόμενο δυναμικό μοντέλο σφάλματος.

# eሶ = Ame +

0
b෨

K෩x

# Tx + K෩rr

# Προσομοίωση Προσαρμοστικού Ελεγκτή Μοντέλου Αναφοράς


ΠΡΟΣΑΡΜΟΣΤΙΚΌΣ ΈΛΕΓΧΟΣ ΣΥΣΤΉΜΑΤΟΣ ΠΟΛΛΑΠΛΏΝ ΔΕΞΑΜΕΝΏΝ | ΟΜΑΔΙΚΉ ΕΡΓΑΣΊΑ ΕΞΑΜΉΝΟΥ | 2203 - ΕΥΦΥΉ ΣΥΣΤΉΜΑΤΑ ΕΛΈΓΧΟΥ ΚΑΙ ΡΟΜΠΟΤΙΚΉΣ | 15
Σχήμα 9. Απόκριση Συστήματος Δεξαμενών. | | Σχήμα 10. Εκτίμηση Παραμέτρων Ελεγκτή.

# Πειραματική Μέτρηση Προσαρμοστικού Ελεγκτή Μοντέλου Αναφοράς


ΠΡΟΣΑΡΜΟΣΤΙΚΌΣ ΈΛΕΓΧΟΣ ΣΥΣΤΉΜΑΤΟΣ ΠΟΛΛΑΠΛΏΝ ΔΕΞΑΜΕΝΏΝ | ΟΜΑΔΙΚΉ ΕΡΓΑΣΊΑ ΕΞΑΜΉΝΟΥ | 2203 - ΕΥΦΥΉ ΣΥΣΤΉΜΑΤΑ ΕΛΈΓΧΟΥ ΚΑΙ ΡΟΜΠΟΤΙΚΉΣ | 16
Σχήμα 11. Απόκριση Φυσικού Συστήματος Δεξαμενών. | | Σχήμα 12. Εκτίμηση Παραμέτρων Ελεγκτή Φυσικού Συστήματος.

g adfl; det C = −; ➢ Συνθήκη ενελικτικού συνόλου.

ΠΡΟΣΑΡΜΟΣΤΙΚΌΣ ΈΛΕΓΧΟΣ ΣΥΣΤΉΜΑΤΟΣ ΠΟΛΛΑΠΛΏΝ ΔΕΞΑΜΕΝΏΝ | ΟΜΑΔΙΚΉ ΕΡΓΑΣΊΑ ΕΞΑΜΉΝΟΥ | 2203 - ΕΥΦΥΉ ΣΥΣΤΉΜΑΤΑ ΕΛΈΓΧΟΥ ΚΑΙ ΡΟΜΠΟΤΙΚΉΣ | 17

# 6. Προσαρμοστικός Ελεγκτής Γραμμικοποίησης με Ανάδραση

- Εφαρμογή Γραμμικοποίησης Εισόδου – Κατάστασης.
- Χρήση άλγεβρας Lie.

# - Τοπική Συνθήκη Ελεγξιμότητας

- Σύνολο {g} ενελικτικό, περιέχει σταθερές ποσότητες.

∇z1adfl

ΠΡΟΣΑΡΜΟΣΤΙΚΌΣ ΈΛΕΓΧΟΣ ΣΥΣΤΉΜΑΤΟΣ ΠΟΛΛΑΠΛΏΝ ΔΕΞΑΜΕΝΏΝ | ΟΜΑΔΙΚΉ ΕΡΓΑΣΊΑ ΕΞΑΜΉΝΟΥ | 2203 - ΕΥΦΥΉ ΣΥΣΤΉΜΑΤΑ ΕΛΈΓΧΟΥ ΚΑΙ ΡΟΜΠΟΤΙΚΉΣ | 18

# Γραμμικοποίηση Εισόδου - Κατάστασης

z1
z2

=

ℎ2

# θ1 ℎ1 − θ2 ℎ2

- Μετασχηματισμένο σύστημα μέσω γραμμικοποίησης.
- Επιλογή νέας μεταβλητής κατάστασης.

z1 = ℎ2
- Επιλογή δεύτερης μεταβλητής κατάστασης.

# z2 = z1ሶ = Lfz1 = ∇z1f ℎ1, ℎ2 = θ1 ℎ1 − θ2 ℎ2

# Νόμος Ελέγχου Μεθόδου (1)

ΠΡΟΣΑΡΜΟΣΤΙΚΌΣ ΈΛΕΓΧΟΣ ΣΥΣΤΉΜΑΤΟΣ ΠΟΛΛΑΠΛΏΝ ΔΕΞΑΜΕΝΏΝ; ΟΜΑΔΙΚΉ ΕΡΓΑΣΊΑ ΕΞΑΜΉΝΟΥ; 2203 - ΕΥΦΥΉ ΣΥΣΤΉΜΑΤΑ ΕΛΈΓΧΟΥ ΚΑΙ ΡΟΜΠΟΤΙΚΉΣ

➢ Τροποποιημένο σύστημα με βάση την αρχή της αβεβαιότητας.

➢ Χρήση σχέσεων θi = θ෨

➢ Νόμος ελέγχου γραμμικοποίησης.

➢ Επιλογή γραμμικού νόμου ελέγχου.; ➢ Δυναμική Συστήματος.

ΠΡΟΣΑΡΜΟΣΤΙΚΌΣ ΈΛΕΓΧΟΣ ΣΥΣΤΉΜΑΤΟΣ ΠΟΛΛΑΠΛΏΝ ΔΕΞΑΜΕΝΏΝ | ΟΜΑΔΙΚΉ ΕΡΓΑΣΊΑ ΕΞΑΜΉΝΟΥ | 2203 - ΕΥΦΥΉ ΣΥΣΤΉΜΑΤΑ ΕΛΈΓΧΟΥ ΚΑΙ ΡΟΜΠΟΤΙΚΉΣ | 20

# Νόμος Ελέγχου Μεθόδου (2)

- Αλλαγή παραγώγου μεταβλητής κατάστασης.

ΠΡΟΣΑΡΜΟΣΤΙΚΌΣ ΈΛΕΓΧΟΣ ΣΥΣΤΉΜΑΤΟΣ ΠΟΛΛΑΠΛΏΝ ΔΕΞΑΜΕΝΏΝ | ΟΜΑΔΙΚΉ ΕΡΓΑΣΊΑ ΕΞΑΜΉΝΟΥ | 2203 - ΕΥΦΥΉ ΣΥΣΤΉΜΑΤΑ ΕΛΈΓΧΟΥ ΚΑΙ ΡΟΜΠΟΤΙΚΉΣ | 21

# Νόμος Ελέγχου Μεθόδου (3)

- Υποψήφια συνάρτηση Lyapunov.

# zሶm =

0 | 1
−K1 | −K2

zm +

0
kr

r

- Μοντέλο αναφοράς.
- Δυναμική συστήματος σφάλματος.

eሶ =

0 | 1
−K1 | −K2

e + θ෨

1H1 + θ෨

# 2H2 + b෨H3

- Νόμοι προσαρμογής.

# Προσομοίωση Προσαρμοστικού Ελεγκτή Γραμμικοποίησης με Ανάδραση


ΠΡΟΣΑΡΜΟΣΤΙΚΌΣ ΈΛΕΓΧΟΣ ΣΥΣΤΉΜΑΤΟΣ ΠΟΛΛΑΠΛΏΝ ΔΕΞΑΜΕΝΏΝ | ΟΜΑΔΙΚΉ ΕΡΓΑΣΊΑ ΕΞΑΜΉΝΟΥ | 2203 - ΕΥΦΥΉ ΣΥΣΤΉΜΑΤΑ ΕΛΈΓΧΟΥ ΚΑΙ ΡΟΜΠΟΤΙΚΉΣ | 22
Σχήμα 13. Απόκριση Συστήματος Δεξαμενών. | | Σχήμα 14. Εκτίμηση Παραμέτρων Ελεγκτή.

# Πειραματική Μέτρηση Προσαρμοστικού Ελεγκτή Γραμμικοποίησης με Ανάδραση


ΠΡΟΣΑΡΜΟΣΤΙΚΌΣ ΈΛΕΓΧΟΣ ΣΥΣΤΉΜΑΤΟΣ ΠΟΛΛΑΠΛΏΝ ΔΕΞΑΜΕΝΏΝ | ΟΜΑΔΙΚΉ ΕΡΓΑΣΊΑ ΕΞΑΜΉΝΟΥ | 2203 - ΕΥΦΥΉ ΣΥΣΤΉΜΑΤΑ ΕΛΈΓΧΟΥ ΚΑΙ ΡΟΜΠΟΤΙΚΉΣ | 23
Σχήμα 15. Απόκριση Φυσικού Συστήματος Δεξαμενών. | | Σχήμα 16. Εκτίμηση Παραμέτρων Ελεγκτή Φυσικού Συστήματος.

ΠΡΟΣΑΡΜΟΣΤΙΚΌΣ ΈΛΕΓΧΟΣ ΣΥΣΤΉΜΑΤΟΣ ΠΟΛΛΑΠΛΏΝ ΔΕΞΑΜΕΝΏΝ | ΟΜΑΔΙΚΉ ΕΡΓΑΣΊΑ ΕΞΑΜΉΝΟΥ | 2203 - ΕΥΦΥΉ ΣΥΣΤΉΜΑΤΑ ΕΛΈΓΧΟΥ ΚΑΙ ΡΟΜΠΟΤΙΚΉΣ | 24

# 7. Προσαρμοστικός Ελεγκτής Οπισθοδρόμησης

- Χρήση μη γραμμικού μοντέλου για την εφαρμογή της μεθόδου οπισθοδρόμησης.
- Μετασχηματισμός κατάστασης συστήματος.
- Νέες μεταβλητές κατάστασης.

ξሶ

# 1 = −K1ξ1 + ξ2

# ξ1 = e2 = ℎ2 − ℎ2d

➢ Χρήση σχέσης θi = θ෨

ΠΡΟΣΑΡΜΟΣΤΙΚΌΣ ΈΛΕΓΧΟΣ ΣΥΣΤΉΜΑΤΟΣ ΠΟΛΛΑΠΛΏΝ ΔΕΞΑΜΕΝΏΝ | ΟΜΑΔΙΚΉ ΕΡΓΑΣΊΑ ΕΞΑΜΉΝΟΥ | 2203 - ΕΥΦΥΉ ΣΥΣΤΉΜΑΤΑ ΕΛΈΓΧΟΥ ΚΑΙ ΡΟΜΠΟΤΙΚΉΣ | 25

# Εύρεση Νόμων Προσαρμογής (1)

# Εύρεση Νόμων Προσαρμογής (2)

ΠΡΟΣΑΡΜΟΣΤΙΚΌΣ ΈΛΕΓΧΟΣ ΣΥΣΤΉΜΑΤΟΣ ΠΟΛΛΑΠΛΏΝ ΔΕΞΑΜΕΝΏΝ; ΟΜΑΔΙΚΉ ΕΡΓΑΣΊΑ ΕΞΑΜΉΝΟΥ; 2203 - ΕΥΦΥΉ ΣΥΣΤΉΜΑΤΑ ΕΛΈΓΧΟΥ ΚΑΙ ΡΟΜΠΟΤΙΚΉΣ; ➢ Νόμοι προσαρμογής.; ሶ θመ 1 = γ1Proj θመ 1, ξ1 ℎ1 + ξ2β1; ሶ θመ 2 = γ2Proj θመ 2, −ξ1 ℎ2 + ξ2β2; ෠ሶ b = γ3Proj b෠, ξ2β3

➢ Επιλογή υποψήφιας συνάρτησης Lyapunov.

➢ Επιλογή νόμου ελέγχου.

➢ Ευστάθεια γύρω από το σημείο ισορροπίας ξ1, ξ2 = 0,0 → e1, e2 = 0,0 .

# Προσομοίωση Προσαρμοστικού Ελεγκτή Οπισθοδρόμησης


ΠΡΟΣΑΡΜΟΣΤΙΚΌΣ ΈΛΕΓΧΟΣ ΣΥΣΤΉΜΑΤΟΣ ΠΟΛΛΑΠΛΏΝ ΔΕΞΑΜΕΝΏΝ | ΟΜΑΔΙΚΉ ΕΡΓΑΣΊΑ ΕΞΑΜΉΝΟΥ | 2203 - ΕΥΦΥΉ ΣΥΣΤΉΜΑΤΑ ΕΛΈΓΧΟΥ ΚΑΙ ΡΟΜΠΟΤΙΚΉΣ | 27
Σχήμα 17. Απόκριση Συστήματος Δεξαμενών. | | Σχήμα 18. Εκτίμηση Παραμέτρων Ελεγκτή.

# Πειραματική Μέτρηση Προσαρμοστικού Ελεγκτή Οπισθοδρόμησης


ΠΡΟΣΑΡΜΟΣΤΙΚΌΣ ΈΛΕΓΧΟΣ ΣΥΣΤΉΜΑΤΟΣ ΠΟΛΛΑΠΛΏΝ ΔΕΞΑΜΕΝΏΝ | ΟΜΑΔΙΚΉ ΕΡΓΑΣΊΑ ΕΞΑΜΉΝΟΥ | 2203 - ΕΥΦΥΉ ΣΥΣΤΉΜΑΤΑ ΕΛΈΓΧΟΥ ΚΑΙ ΡΟΜΠΟΤΙΚΉΣ | 28
Σχήμα 19. Απόκριση Φυσικού Συστήματος Δεξαμενών. | | Σχήμα 20. Εκτίμηση Παραμέτρων Ελεγκτή Φυσικού Συστήματος.

ΠΡΟΣΑΡΜΟΣΤΙΚΌΣ ΈΛΕΓΧΟΣ ΣΥΣΤΉΜΑΤΟΣ ΠΟΛΛΑΠΛΏΝ ΔΕΞΑΜΕΝΏΝ | ΟΜΑΔΙΚΉ ΕΡΓΑΣΊΑ ΕΞΑΜΉΝΟΥ | 2203 - ΕΥΦΥΉ ΣΥΣΤΉΜΑΤΑ ΕΛΈΓΧΟΥ ΚΑΙ ΡΟΜΠΟΤΙΚΉΣ | 29

# 8. Συμπεράσματα – Αξιολόγηση Συστήματος

- Οι προσαρμοστικοί νόμοι διατηρούν το σύστημα στο σημείο ισορροπίας.
- Η απόκριση του φυσικού συστήματος παρόμοια με αυτή των προσομοιώσεων.
- Οι εκτιμήσεις των κερδών διαφέρουν κατά τη σύγκλισή τους.
- Η αντλία παρέχει διακριτές τιμές ελέγχου στο σύστημα.
- Η εκτίμηση των παραμέτρων ελέγχου επηρεάστηκε από την αντλία.
- Απόκλιση των τιμών κατά τη διάρκεια των συνεχόμενων πειραμάτων λόγω φθοράς.

ΠΡΟΣΑΡΜΟΣΤΙΚΌΣ ΈΛΕΓΧΟΣ ΣΥΣΤΉΜΑΤΟΣ ΠΟΛΛΑΠΛΏΝ ΔΕΞΑΜΕΝΏΝ | ΟΜΑΔΙΚΉ ΕΡΓΑΣΊΑ ΕΞΑΜΉΝΟΥ | 2203 - ΕΥΦΥΉ ΣΥΣΤΉΜΑΤΑ ΕΛΈΓΧΟΥ ΚΑΙ ΡΟΜΠΟΤΙΚΉΣ | 30

# Συμπεράσματα – Αξιολόγηση Συστήματος

- Σφάλματα στη δημιουργία των κατάλληλων σημάτων τάσης, λόγω εσφαλμένων μετρήσεων.
- Λάθος υπολογισμός της παραγώγου λόγω μεγάλων αποστάσεων διαδοχικών τιμών.
- Πρόβλημα κατά την λειτουργία του ελέγχου λόγω αστάθειας του συστήματος.
- Μηδενισμός του παρονομαστή του σήματος ελέγχου.
- Πρόβλημα του αισθητήρα κατά τη μέτρηση.

ΠΡΟΣΑΡΜΟΣΤΙΚΌΣ ΈΛΕΓΧΟΣ ΣΥΣΤΉΜΑΤΟΣ ΠΟΛΛΑΠΛΏΝ ΔΕΞΑΜΕΝΏΝ | ΟΜΑΔΙΚΉ ΕΡΓΑΣΊΑ ΕΞΑΜΉΝΟΥ | 2203 - ΕΥΦΥΉ ΣΥΣΤΉΜΑΤΑ ΕΛΈΓΧΟΥ ΚΑΙ ΡΟΜΠΟΤΙΚΉΣ | 31

# 9. Βιβλιογραφία

[1] Petros A. Ioannou and Jing Sun. Robust Adaptive Control. Dover Publications, 2012. isbn:978- 0486498171.
[2] Hassan K. Khalil. Nonlinear Systems. 3rd Edition. Pearson, 2001. isbn: 978-0130673893.
[3] Jay A. Farrell and Marios M. Polycarpou. Adaptive Approximation Based Control: Unifying Neural, Fuzzy and
Traditional Adaptive Approximation Approaches. John Wiley Sons, Inc., 2006. isbn: | 978-0-471-72788-0.
doi: 10.1007/978-0-471- | 72788-0.
[4] Jean-Jacques E. Slotine και Weiping Li. Applied Nonlinear Control. Prentice Hall, 1991. | isbn:0-13-
040890-5.
[5] K. Astrom and A.-B. Ostberg. “A teaching laboratory for process control”. In: IEEE Control Systems Magazine 6.5 (1986), pp. 37–42. doi: 10.1109/MCS.1986. 1105142.

ΠΡΟΣΑΡΜΟΣΤΙΚΌΣ ΈΛΕΓΧΟΣ ΣΥΣΤΉΜΑΤΟΣ ΠΟΛΛΑΠΛΏΝ ΔΕΞΑΜΕΝΏΝ | ΟΜΑΔΙΚΉ ΕΡΓΑΣΊΑ ΕΞΑΜΉΝΟΥ | 2203 - ΕΥΦΥΉ ΣΥΣΤΉΜΑΤΑ ΕΛΈΓΧΟΥ ΚΑΙ ΡΟΜΠΟΤΙΚΉΣ | 32

# Σας Ευχαριστούμε!!

Ερωτήσεις;

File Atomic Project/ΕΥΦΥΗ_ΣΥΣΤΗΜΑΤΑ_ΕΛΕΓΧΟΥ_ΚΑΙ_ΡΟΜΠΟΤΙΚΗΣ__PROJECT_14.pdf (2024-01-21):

# ΕΘΝΙΚΟ ΜΕΤΣΟΒΙΟ ΠΟΛΥΤΕΧΝΕΙΟ ΔΙΑΤΜΗΜΑΤΙΚΟ ΠΡΟΓΡΑΜΜΑ


# ΜΕΤΑΠΤΥΧΙΑΚΩΝ ΣΠΟΥΔΩΝ ΣΥΣΤΗΜΑΤΑ ΑΥΤΟΜΑΤΙΣΜΟΥ ΚΑΤΕΥΘΥΝΣΗ: ΣΥΣΤΗΜΑΤΑ ΑΥΤΟΜΑΤΟΥ ΕΛΕΓΧΟΥ ΚΑΙ ΡΟΜΠΟΤΙΚΗΣ

# ΜΑΘΗΜΑ: ΕΥΦΥΗ ΣΥΣΤΗΜΑΤΑ ΕΛΕΓΧΟΥ ΚΑΙ ΡΟΜΠΟΤΙΚΗΣ

# Εξαμηνιαία Εργασία

# Θετικά Πραγματικές Συναρτήσεις και Ευστάθεια Γραμμικών Χρονικά Αμετάβλητων Συστημάτων Ανάδρασης Γεώργιος Κρομμύδας - 02121208

# Αθήνα, 2024

# Περιεχόμενα


1.1 | Θετικά Πραγματικές και Αυστηρά Θετικά Πραγματικές Συναρτήσεις Μεταφοράς | 5
1.2 | Θετικά Πραγματικοί και Αυστηρά Θετικά Πραγματικοί Πίνακες Συναρτήσεων Μετα-
| φοράς | 11
2 | Ευστάθεια Γραμμικών Χρονικά Αμετάβλητων Συστημάτων Ανάδρασης . . . . 13
2.1 | Γενικευμένο Γραμμικά και Χρονικά Αμετάβλητο Σύστημα Ανάδρασης | 13
2.2 | Εσωτερική Ευστάθεια | 14
2.3 | Συναρτήσεις Ευαισθησίας και Συναρτήσεις Συμπληρωματικής Ευαισθησίας | 15
2.4 | Αρχή Εσωτερικού Μοντέλου | 16
3.1 | Άσκηση 3.13 | 18
3.2 | Άσκηση 3.14 | 24
3.3 | Άσκηση 3.15 | 25
3.4 | Άσκηση 3.17 | 27

3

# Κατάλογος σχημάτων


3.1 Πόλοι και μηδενικά συνάρτησης μεταφοράς G1 3.2 Διάγραμμα Nyquist συνάρτησης μεταφοράς G1 3.3 Πόλοι και μηδενικά συνάρτησης μεταφοράς G2 3.4 Διάγραμμα Nyquist συνάρτησης μεταφοράς G2 3.5 Πόλοι και μηδενικά συνάρτησης μεταφοράς G3 3.6 Διάγραμμα Nyquist συνάρτησης μεταφοράς G3 3.7 Πόλοι και μηδενικά συνάρτησης μεταφοράς G4 3.8 Διάγραμμα Nyquist συνάρτησης μεταφοράς G4

4

κές Συναρτήσεις Μεταφοράς; κοί Πίνακες Συναρτήσεων Μεταφοράς; Μεταφοράς

# 1. Θετικά Πραγματικές Συναρτήσεις και Ευστάθεια

1.1 | Θετικά Πραγματικές και Αυστηρά Θετικά Πραγματι-
1.2 | Θετικά Πραγματικοί και Αυστηρά Θετικά Πραγματι-

## 1.1 Θετικά Πραγματικές και Αυστηρά Θετικά Πραγματικές Συναρτήσεις

Οι έννοιες των ΘΠ και ΑΘΠ συναρτήσεων μεταφοράς παίζουν καθοριστικό ρόλο στην ανάλυση της ευστάθειας ενός μεγάλου συνόλου μη γραμμικών συστημάτων, στα οποία περιέχονται και τα προσαρμοστικά συστήματα.
Οι ορισμοί των ΘΠ και ΑΘΠ συναρτήσεων μεταφοράς προέρχονται από τη θεωρία δικτύων. Δηλαδή, μια ρητή συνάρτηση τύπου ΘΠ (ή ΑΘΠ) μπορεί να οριστεί ως η σύνθετη εμπέδηση ενός παθητικού (καταναλισκόμενου) δικτύου. Αντιθέτως, ένα παθητικό (καταναλισκόμενο) δίκτυο έχει μία σύνθετη εμπέδηση η οποία αποτελείται από μια ρητή και ΘΠ (ή ΑΘΠ) συνάρτηση μεταφοράς. Ένα παθητικό δίκτυο δεν παράγει ενέργεια, όπως για παράδειγμα ένα δίκτυο το οποίο αποτελείται μόνο από αντιστάσεις, πυκνωτές και πηνία. Ένα καταναλισκόμενο δίκτυο καταναλώνει ενέργεια, το οποίο υπονοεί πως αποτελείται από αντιστάσεις, πυκνωτές και πηνία, τα οποία είναι συνδεδεμένα εν παραλλήλω με τις αντιστάσεις.
Τώρα θα ορίσουμε μαθηματικά την έννοια της Θετικά Πραγματικής συνάρτησης από τη θεωρία δικτύων.

Ορισμός 1.1 Μια γνήσια ρητή συνάρτηση G(s) με μιγαδική μεταβλητή s = σ+jω ονομάζεται ΘΠ, Αν

1. η G(s) είναι πραγματική για πραγματικά s.
2. Re[G(s)] ≥ 0 για όλα τα Re[s] > 0.

5

6 | 1.1. Θετικά Πραγματικές και Αυστηρά Θετικά Πραγματικές Συναρτήσεις Μεταφοράς

πραγματικοί.; ένας έχει Re[G(jω)] ≥ 0.

| Λήμμα 1.1 Μια γνήσια ρητή συνάρτηση μεταφοράς G(s) είναι ΘΠ αν και μόνο αν
1. Η G(s) είναι πραγματική για πραγματικά s.
2. Η G(s) είναι αναλυτική στο Re[s] > 0, και οι πόλοι που βρίσκονται στον φανταστικό
| άξονα είναι απλοί με τους φανταστικούς συντελεστές των πόλων να είναι θετικοί και
3. Για όλες τις πραγματικές τιμές ω, τις οποίες το s = jω δεν αποτελεί πόλο της G(s),
| Τώρα θα εξετάσουμε τις ΑΘΠ συναρτήσεις μεταφοράς. Ο ορισμός είναι ο εξής.
| Ορισμός 1.2 Ας υποθέσουμε πως η G(s) δεν είναι ταυτόσημη μηδέν για όλα τα s. Τότε η G(s) είναι ΑΘΠ αν το G(s − ε) είναι ΘΠ για κάποιο ε > 0.
| Το θεώρημα τo οποίο ακολουθεί διατυπώνει τις αναγκαίες και ικανές συνθήκες στο πεδίο της
συχνότητας για μία συνάρτηση μεταφοράς η οποία είναι ΑΘΠ.

Έστω n; | ≤ 1. Τότε, η G(s) είναι ΑΘΠ αν; και μόνο αν; 3. (αʹ) Όταν το n; ∗ = 1, lim|ω|→∞ ω; (βʹ) Όταν το n; ∗ = −1, lim|ω|→∞

| Θεώρημα 1.1 Υποθέτουμε πως μια ρητή συνάρτηση μεταφοράς G(s) με μιγαδική μεταβλητή s = σ + jω είναι πραγματική για πραγματικό s και δεν είναι ταυτόσημα μηδέν για όλα τα s. ο σχετικός βαθμός της G(s) = Z(s)/R(s) με το |n∗
1. H G(s) είναι αναλυτική στο Re[s] ≥ 0.

Πρέπει να σημειωθεί πως όταν το n

∗ = 0, τα (1) και (2) του θεωρήματος 1.1 είναι ικανές και αναγκαίες συνθήκες για να είναι η συνάρτηση μεταφοράς G(s) ΑΘΠ. Ωστόσο, αυτό δεν ισχύει για τις περιπτώσεις που ο n

∗ = 1 ή −1. Για παράδειγμα,

G(s) = s + α + β
(s + α)(s + β)

όπου τα α, β > 0. Η συνάρτηση αυτή ικανοποιεί τα (1) και (2) του θεωρήματος 1.1, ωστόσο, δεν ικανοποιεί το (3α). Ωστόσο, παρατηρούμε πως είναι ΘΠ.
Θα ορίσουμε κάποιες χρήσιμες ιδιότητες για τις ΑΘΠ συναρτήσεις.

2. Αν η G(s) είναι ΑΘΠ, τότε, |n∗ στο Re[s] < 0.; | > 1, τότε η G(s) δεν είναι ΘΠ.

Πόρισμα 1.1 1. Η G(s) είναι ΘΠ (ΑΘΠ) αν και μόνο αν η 1/G(s) είναι ΘΠ (ΑΘΠ).

| ≤ 1, και οι πόλοι και τα μηδενικά της G(s) βρίσκονται

Κεφάλαιο 1. Θετικά Πραγματικές Συναρτήσεις και Ευστάθεια | 7

Μια αναγκαία συνθήκη για τη G(s) να είναι ΘΠ είναι πως το διάγραμμα Nyquist της G(jω) να βρίσκεται στο δεξιό μιγαδικό επίπεδο, το οποίο σημαίνει πως η αλλαγή φάσης της εξόδου του συστήματος με συνάρτηση μεταφοράς G(s) με ημιτονοειδής απόκριση πρέπει να είναι λιγότερο από 90 deg. Για παράδειγμα, μπορούμε να δούμε στο σχήμα 1.1 το διάγραμμα μιας ΘΠ συνάρτησης μεταφοράς.


Σχήμα 1.1: Διάγραμμα Nyquist μιας ΘΠ συνάρτησης μεταφοράς.

Παράδειγμα 1.1 Έστω πως έχουμε τις παρακάτω συναρτήσεις μεταφοράς

1. G1

(s) = s−1
(s+2)²
2. G2

(s) = 1
(s+2)²
3. G3

(s) = s+3
(s+1)(s+2)
4. G4

(s) = 1
s+α
Χρησιμοποιώντας το πόρισμα 1.1, διαπιστώνουμε πως η G1

(s) δεν είναι ΘΠ, καθώς η 1/G1 (s)
δεν είναι ΘΠ. Επιπλέον, η G2

(s) δεν είναι ΘΠ διότι ο n

∗ > 1. Για την G3
(s) έχουμε ότι ισχύει

Re[G3

(jω)] = | 6
(ω² + 2)² + ω²

> 0, ∀ω ∈ (−∞, ∞)

όπου μαζί με την ευστάθεια της G3

(s) υπονοείται πως η G3

(s) είναι ΘΠ. Καθώς η G3

(s) παραβιάζει τη συνθήκη (3α) του θεωρήματος 1.1, τότε δεν είναι ΑΘΠ. Η συνάρτηση μεταφοράς G4

(s) είναι ΑΘΠ για κάθε α > 0 και ΘΠ. Αλλά δεν μπορεί να είναι ΑΘΠ όταν το α = 0.

Η σχέση μεταξύ των ΘΠ, ΑΘΠ συναρτήσεων μεταφοράς μαζί με την Lyapunov ευστάθεια των

8 | 1.1. Θετικά Πραγματικές και Αυστηρά Θετικά Πραγματικές Συναρτήσεις Μεταφοράς

δυναμικών συστημάτων, οδηγούν στην ανάπτυξη νέων κριτηρίων ευστάθειας για συστήματα ανάδρασης με Γραμμικά Χρονικά Αμετάβλητα και μη γραμμικά μέρη. Αυτό τα κριτήρια συμπεριλαμβάνονται σε αυτό του Popov μαζί με τις τροποποιήσεις του. Ο κρίσιμος σύνδεσμος μεταξύ των ΘΠ, ΑΘΠ συναρτήσεων μεταφοράς ή πινάκων, με την ύπαρξη μιας συνάρτησης Lyapunov που μας εγγυάται ευστάθεια, παρουσιάζεται στο παρακάτω Λήμμα.

| Λήμμα 1.2 (Kalman-Yakubovich-Popov (KYP) Λήμμα) Δοσμένου ενός τετραγωνικού πί- νακα Α, με όλες τις ιδιοτιμές να βρίσκονται στο κλειστό αριστερό μιγαδικό επίπεδο, ένα διάνυσμα Β τέτοιο ώστε το (Α, Β) να είναι ελέγξιμο, ένα διάνυσμα C και ένα βαθμωτό μέγε- θος d ≥ 0, η συνάρτηση μεταφοράς, η οποία ορίζεται από τον εξής τύπο
| G(s) = d + CT (sI − A)⁻¹B
| είναι ΘΠ αν και μόνο αν υπάρχει ένας συμμετρικός και θετικά ορισμένος πίνακας P και ένα διάνυσμα q για τα οποία ισχύουν τα εξής
| A T P + PA = −qqT
| PB − C = ±(√2d)q
| Λήμμα 1.3 (Lefschetz-Kalman-Yakubovich (LKY) Λήμμα) Δοσμένου ενός ευσταθή πίνακα Α, ενός διανύσματος Β τέτοιο ώστε το (Α, Β) να είναι ελέγξιμο, ενός διανύσματος C και ενός βαθμωτού μεγέθους d ≥ 0, η συνάρτηση μεταφοράς η οποία ορίζεται από τον τύπο
| G(s) = d + CT (sI − A)⁻¹B
| είναι ΑΘΠ, αν και μόνο αν για οποιονδήποτε πίνακα L, υπάρχει ένας συμμετρικός και θετικά ορισμένος πίνακας P, ένα βαθμωτό μέγεθος v > 0 και ένα διάνυσμα q τέτοια ώστε να ισχύουν

τα εξής
| A T P + PA = −qqT − vL
| PB − C = ±q√2d
| Τα λήμματα 1.2 και 1.3 εφαρμόζονται σε Γραμμικά και Χρονικά Αμετάβλητα Συστήματα τα

οποία είναι ελέγξιμα.; P + PA = −qqT − vL

| Λήμμα 1.4 (Meyer-Kalman-Yakubovich (MKY) Λήμμα) Δοσμένου ενός ευσταθή πίνακα Α, ενός διανύσματος Β, ενός διανύσματος C και ενός βαθμωτού μεγέθους d ≥ 0, έχουμε το εξής:

είναι ΑΘΠ, τότε για οποιονδήποτε πίνακα L = LT > 0, υπάρχει ένα βαθμωτό μέγεθος v > 0, ένα διάνυσμα q και ένας πίνακας P = PT > 0 τέτοια ώστε να ισχύει

Σε πολλές εφαρμογές προσαρμοστικών συστημάτων με ΑΠΘ συναρτήσεις μεταφοράς, η συ-

Κεφάλαιο 1. Θετικά Πραγματικές Συναρτήσεις και Ευστάθεια | 9

νάρτηση G(s) εμπεριέχει ευσταθή ακύρωση των μηδενικών και των πόλων, το οποίο σημαίνει πως ένα σύστημα που περιγράφεται από την πλειάδα (A, B, C) είναι μη ελέγξιμο και μη παρατηρήσιμο. Σε αυτές τις περιπτώσεις το λήμμα MKY αποτελεί την πιο αξιόπιστη λύση.

Παράδειγμα 1.2 Έστω ότι έχουμε το σύστημα

y = G(s)u

όπου το G(s) = s+3
(s+1)(s+2). Θέλουμε να ελέγξουμε εάν η συνάρτηση G(s) είναι ΘΠ ή ΑΘΠ χρησιμοποιώντας τα παραπάνω λήμματα. Το σύστημα στην μορφή του χώρου κατάστασης είναι
x = Ax + Bu ̇
y = CT
x
όπου
A = ⁰ 1

−2 −3 , B = ⁰
1
- , C = ³
1

Σύμφωνα με τα παραπάνω λήμματα, αν η G(s) είναι ΘΠ, τότε θα έχουμε

PB = C

το οποίο σημαίνει πως ο πίνακας P θα είναι

P = p1 3
3 1

για κάποιο p1 > 0 το οποίο πρέπει να ικανοποιεί τη συνθήκη p1−9 > 0 για να είναι ο πίνακας P θετικά ορισμένος. Πρέπει να υπολογίσουμε τα p1

, v > 0 και q τέτοια ώστε να ισχύει

A

T

P + PA = −qqT − vL | (1.1)

με τον L = LT > 0. Έχουμε ότι

− 12 | 11 − p1
11 − p1 | 0
- = −qqT − vL

Έστω ότι ο
Q = 12 | 11 − p1
11 − p1 | 0

Τότε ο Q είναι θετικά ημιορισμένος για p1 = 11 και απροσδιόριστος για p1 ≠ 11. Καθώς δεν υπάρχει κανένα p1 > 9 ώστε ο πίνακας Q να είναι θετικά ορισμένος, τότε δεν μπορεί να βρεθεί v > 0 το οποίο να ικανοποιεί την σχέση 1.1 για οποιονδήποτε δοσμένο πίνακα L = LT > 0. Συνεπώς, η συνάρτηση G(s) δεν είναι ΑΘΠ, κάτι το οποίο αποδείξαμε και στο παράδειγμα 1.1. Για p1 = 11, μπορούμε να επιλέξουμε το v = 0 και το q = [√12, 0]T
έτσι
ώστε να ικανοποιείται η σχέση 1.1. Συνεπώς, η G(s) είναι ΘΠ.

Τα KYP και MKY λήμματα είναι χρήσιμα ως προς την επιλογή ικανών συναρτήσεων Lyapunov και συναρτήσεων τύπου Lyapunov ώστε να αναλυθούν οι ιδιότητες ευστάθειας για μία ευρή κλάση συνεχούς χρόνου προσαρμοστικών σχημάτων για Γραμμικά Χρονικά Αμετάβλητα συστήματα. Πα-

10 | 1.1. Θετικά Πραγματικές και Αυστηρά Θετικά Πραγματικές Συναρτήσεις Μεταφοράς

ρουσιάζουμε τη χρησιμότητα του MKY λήμματος σε προσαρμοστικά συστήματα, παίρνοντας υπόψιν τις ιδιότητες ευστάθειας του συστήματος

| e = A ̇ c e + Bcθ Tω θ = −Γe ̇ 1ω e1 = CT c e (1.2)

το οποίο συχνά εμφανίζεται συχνά στην ανάλυση κάποιων προσαρμοστικών σχημάτων. Στη σχέση (1.2), ο Γ = ΓT > 0 είναι σταθερός, το e ∈ ℛm

| , θ ∈ ℛn ,e1 ∈ ℛ¹ και ω = CT
| 0 e + CT
| 1 em, όπου em είναι
συνεχές και em ∈ ℒ∞. Οι ιδιότητες ευστάθειας της (1.2) δίνεται από το παρακάτω θεώρημα.

τα e, θ, ω ∈ ℒ∞, e, θ ∈ ℒ ̇ ∞ ∩ ℒ2 και τα e(t), e1

Απόδειξη. Καθώς δεν έχουμε κάνει υποθέσεις σχετικά με την ελεγξιμότητα ή την παρατηρησιμότητα του συστήματος (Ac
, Bc

, Cc

), εστιάζουμε στην εφαρμογή του MKY Λήμματος. Επιλέγουμε την εξής συνάρτηση Lyapunov
| V(e, θ) = eT Pe + θT
Γ

−1θ
όπου ο P = PT > 0 ικανοποιεί τις συνθήκες
| A T

c P + PAc = −qqT − vL

PBc = C
για κάποιο διάνυσμα q, βαθμωτό μέγεθος v > 0 και οποιοσδήποτε πίνακας L = LT > 0 τα οποία μας εγγυώνται την ΑΘΠ ιδιότητα για τη συνάρτηση μεταφοράς G(s) και το MKY Λήμμα. Καθώς το ω = CT
0

e + CT
1

em, με το em ∈ ℒ∞, μπορεί να συμπεριφερθεί ως μία αυθαίρετη συνεχή συνάρτηση του χρόνου στον χώρο ℒ∞, τότε μπορούμε να διαπιστώσουμε πως η V(e, θ) είναι θετικά ορισμένη στο σύνολο ℛ

n+m, και η V αποτελεί μια υποψήφια συνάρτηση Lyapunov.
Η χρονική παράγωγος της V μαζί με την λύση της σχέσης (1.2), δίνεται από

V = −e ̇

T

qqT

e − veT
Le ≤ 0
το οποίο σημαίνει πως το σημείο ισορροπίας (ee , θe

) = (0, 0) είναι ευσταθές και τα e1

, e, θ ∈ ℒ∞.
Καθώς το ω = CT
0

e + CT
1

em και το em ∈ ℒ∞, τότε και το ω ∈ ℒ∞. Επιπλέον, χρησιμοποιώντας τις ιδιότητες των V, V̇
, μπορούμε να εξάγουμε περισσότερα συμπεράσματα σχετικά με τη λύση της σχέσης (1.2) ως εξής: Από το V ≥ 0 και το V ≤ 0 ̇ εξάγουμε ότι

lim
t→∞

V(e(t), θ(t)) = V∞
και συνεπώς έχουμε
v ∞

0

e

T
Ledτ ≤ V0 − V∞

όπου V0 = V(e(0), θ(0)). Καθώς το vλmin(L)|e|² ≤ veT Le, διαπιστώνουμε πως το e ∈ ℒ2

. Από τη
σχέση (1.2) έχουμε ότι |θ(t)| ≤ ||Γ|||e ̇
1

||ω|. Καθώς το ω ∈ ℒ∞ και e1 ∈ ℒ∞ ∩ ℒ2 τότε από το λήμμα
3.2.3 (ii), [6], έχουμε ότι το θ ∈ ℒ ̇ | ∞∩ℒ2
. Χρησιμοποιώντας τα e, θ, ω ∈ ℒ∞ προκύπτει πως το e ∈ ℒ ̇ | ∞,
όπου μαζί με το e ∈ ℒ2

, διαπιστώνουμε πως το e(t) → 0 καθώς το t → ∞ (Λήμμα Barbalat́ ). Έτσι θα έχουμε ότι τα e1

, θ, e → 0 ̇ όταν το t → ∞, ολοκληρώνοντας έτσι την απόδειξη.

Κεφάλαιο 1. Θετικά Πραγματικές Συναρτήσεις και Ευστάθεια | 11

Η ανάλυση που έγινε για την απόδειξη του θεωρήματος 1.2, χρησιμοποιείται γενικότερα στην ανάλυση ευστάθειας των προσαρμοστικών συστημάτων.

## 1.2 Θετικά Πραγματικοί και Αυστηρά Θετικά Πραγματικοί Πίνακες Συναρτήσεων Μεταφοράς

Οι έννοιες των ΘΠ και ΑΘΠ συναρτήσεων μεταφοράς γενικεύονται και επεκτείνονται και σε μητρωϊκή μορφή. Οι ορισμοί δίνονται ως εξής.

Ορισμός 1.3 Ένας n × n πίνακας G(s) του οποίου τα στοιχεία του είναι συναρτήσεις των σύνθετων μεταβλητών s, ονομάζεται ΘΠ εάν

1. Η G(s) έχει στοιχεία τα οποία είναι αναλυτικά για Re[s] > 0.
2. G

∗

(s) = G(s∗
) για Re[s] > 0.
3. Το G

T

(s∗
) + G(s) είναι θετικά ημιορισμένο για Re[s] > 0.

όπου το ∗ αντιστοιχεί στον συζυγή μιγαδικό.

Ορισμός 1.4 Ένας n × n πίνακας G(s) είναι ΑΘΠ αν ο πίνακας G(s − ε) είναι ΘΠ για κάποιο ε > 0.

Ικανές και αναγκαίες συνθήκες στο πεδίο της συχνότητας για τον G(s) να είναι ΑΘΠ, δίνονται

από τα παρακάτω θεωρήματα.; πως το G(s) + GT ΑΘΠ αν και μόνο αν; limω→∞; (−jω)] > 0, D + DT ≥ 0 αν det[D + DT; (−jω)] > 0 αν det[D + DT

Θεώρημα 1.3 Έστω ότι έχουμε έναν n × n ρητό πίνακα συναρτήσεων μεταφοράς

όπου οι A, B, C και D είναι πραγματικοί πίνακες με καλώς ορισμένες διαστάσεις. Υποθέτουμε (−s) έχει βαθμό n σχεδόν παντού στο μιγαδικό επίπεδο. Τότε, ο G(s) είναι

1. Όλα τα στοιχεία του G(s) είναι αναλυτικά στο Re[s] ≥ 0.

Ικανές και αναγκαίες συνθήκες για του πίνακες A, B, C και D στη (1.3) για να είναι ο G(s) ΘΠ, ΑΘΠ δίνονται από τα λήμματα τα οποία γενικεύονται από τα λήμματα Μίας Εισόδου Μίας Εξόδου σε Πολλών Εισόδων Πολλών Εξόδων.

12 1.2. Θετικά Πραγματικοί και Αυστηρά Θετικά Πραγματικοί Πίνακες Συναρτήσεων Μεταφοράς

Θεώρημα 1.4 Υποθέτουμε ότι ο πίνακας μεταφοράς G(s) δίνεται από τη σχέση (1.3) και είναι τέτοια ώστε το G(s) + G(−s) έχει βαθμό n σχεδόν σε όλο το μιγαδικό επίπεδο, η det(sI − A) έχει όλα τα μηδενικά στο ανοικτό αριστερό μιγαδικό επίπεδο και το (A, B) είναι πλήρες ελέγξιμο. Τότε, ο G(s) είναι ΑΘΠ αν και μόνο αν για οποιονδήποτε πραγματικό συμμετρικό και θετικά ορισμένο πίνακα L, υπάρχει ένας πραγματικός συμμετρικός και θετικά ορισμένος πίνακας P, ένα βαθμωτό μέγεθος v > 0, οι πραγματικοί πίνακες Q και Κ, τέτοια ώστε να ισχύει
A

T

P + PA = −QQT − vL

P + PA = −QQT − 2γP

Λήμμα 1.5 Ας υποθέσουμε ότι ο πίνακας μεταφοράς G(s) έχει τους πόλους να προσπίπτουν στο αριστερό μιγαδικό επίπεδο σύμφωνα με τη σχέση Re[s] < −γ, όπου το γ > 0 και το (A, B, C, D) είναι η ελάχιστη αποτύπωση του πίνακα G(s). Τότε, ο πίνακας G(s) είναι ΑΘΠ αν και μόνο αν ο πίνακας P = PT > 0, και υπάρχουν οι πίνακες Q, K τέτοιοι ώστε


Σχήμα 1.2: Γενικό μπλοκ διάγραμμα συστήματος ανάδρασης.

Οι ΑΘΠ ιδιότητες των πινάκων μεταφοράς χρησιμοποιούνται για την ανάλυση προσαρμοστικών σχημάτων που χρησιμοποιούνται σε συστήματα Πολλών Εισόδων Πολλών Εξόδων με παρόμοιο τρόπο όπως και στα συστήματα Μίας Εισόδου Μίας Εξόδου.

Ανάδρασης; στημα Ανάδρασης; Εσωτερική Ευστάθεια; Συναρτήσεις Ευαισθησίας και Συναρτήσεις Συμπλη-; ρωματικής Ευαισθησίας; Αρχή Εσωτερικού Μοντέλου; τηρούμε πως η G0

# 2. Ευστάθεια Γραμμικών Χρονικά Αμετάβλητων Συστημάτων

2.1 Γενικευμένο Γραμμικά και Χρονικά Αμετάβλητο Σύ-

## 2.1 Γενικευμένο Γραμμικά και Χρονικά Αμετάβλητο Σύστημα Ανάδρασης

Το μπλοκ διάγραμμα ενός τυπικού συστήματος ανάδρασης εμφανίζεται στο σχήμα 1.2. Παρα-(s) αποτελεί την συνάρτηση μεταφοράς της διεργασίας και οι συναρτήσεις μεταφοράς C(s), F(s) αποτελούν τον αντισταθμιτή ελέγχου και αντισταθμιτή ανάδρασης, αντίστοιχα. Η είσοδος ελέγχου u που παράγεται από την ανάδραση, έχει αλλοιωθεί από την είσοδο θορύβου du και παράγεται η είσοδος u0 της διεργασίας. Ομοίως, η έξοδος της διεργασίας y0 αλλοιώνεται από τον θόρυβο d για να σχηματιστεί η πραγματική έξοδος της διεργασίας y. Η μετρούμενη έξοδος yn αλλοιώνεται και αυτή από θόρυβο dn

, όπου το αποτέλεσμα αποτελεί την είσοδο του αντισταθμιτή F(s), του οποίου η έξοδος ye αποτελεί την ανάδραση που θα αφαιρεθεί από την επιθυμητή είσοδο y

∗
, έτσι ώστε να σχηματιστεί το σήμα σφάλματος e.
Οι συναρτήσεις μεταφοράς G0

(s), C(s), F(s)είναι γενικά γνήσιες και αιτιατές, ωστόσο μπορούν να είναι είτε ρητές είτε άρρητες, το οποίο σημαίνει πως μπορεί να υπάρχουν χρονικές καθυστερήσεις.
Το σύστημα ανάδρασης μπορεί να γραφτεί σε μία πιο συμπαγή μητρωϊκή μορφή Ε/Ε, με το διάνυσμα εισόδου να είναι το R = [y∗
, du

, d, dn

]

T
και τα διανύσματα εξόδου να είναι το E = [e, u0
, y, yn

]

T
και το Y = [y0
, ye

, u]T
. Η γενικευμένη μορφή είναι
E = H(s)R, | Y = I1E + I2R | (2.1)

όπου

H(s) = 1
1 + FCG0

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
1 | −FG0 | −F | −F
C | 1 | −FC | −FC
CG0 | G0 | 1 | −FCG0
CG0 | G0 | 1 | 1

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
I1 =

⎡
⎢⎢⎢⎢⎢⎢

⎣

0 0 1 0
−1 0 0 0
0 1 0 0

⎤
⎥⎥⎥⎥⎥⎥

⎦

, I2 =

⎡
⎢⎢⎢⎢⎢⎢

⎣

0 | 0 | −1 0
1 | 0 | 0 | 0
0 −1 | 0 | 0

⎤
⎥⎥⎥⎥⎥⎥

⎦

13

14 | 2.2. Εσωτερική Ευστάθεια

## 2.2 Εσωτερική Ευστάθεια

Η σχέση (2.1) συσχετίζει όλα τα σήματα του συστήματος με τις εξωτερικές εισόδους y

∗
, du

, d, dn

Από πρακτικής άποψης είναι σημαντικό να εγγυηθεί πως για οποιοδήποτε φραγμένο σήμα εισόδου R, όλα τα σήματα του κλειστού βρόχου να είναι φραγμένα. Σύμφωνα με τα παραπάνω θα οριστεί η έννοια της εσωτερικής ευστάθειας.

Ορισμός 2.1 Το σύστημα ανάδρασης είναι εσωτερικά ευσταθές αν για οποιαδήποτε εξωτερική είσοδο R, τα σήματα Y, E είναι φραγμένα και κατ' επέκτασιν ισχύει

||Y||∞ ≤ c1

||R||∞, | ||E||∞ ≤ c2
||R||∞ | (2.2)

για κάποιες σταθερές c1

, c2 ≥ 0 που είναι ανεξάρτητες από το R.

Μια ικανή και αναγκαία συνθήκη για το σύστημα ανάδρασης (2.1) να είναι εσωτερικά ευσταθές, θα πρέπει κάθε στοιχείο του πίνακα μεταφοράς H(s) να έχει ευσταθείς πόλους, δηλαδή να βρίσκονται στο ανοικτό αριστερό μιγαδικό επίπεδο.
Η έννοια της εσωτερικής ευστάθειας μπορεί να είναι μπερδευτική στους αναγνώστες, καθώς στα περισσότερα προπτυχιακά βιβλία, η ευστάθεια ενός συστήματος ανάδρασης ελέγχεται με την εύρεση των ριζών του χαρακτηριστικού πολυωνύμου

1 + FCG0 = 0
Το παρακάτω παράδειγμα θα λύσει τις διαφορές μεταξύ των δύο τρόπων ανάλυσης της ευστάθειας.

Παράδειγμα 2.1 Έστω ότι έχουμε τα εξής

G0

(s) = 1
s − 2

, C(s) = s − 2
s − 5

, F(s) = 1

για τα οποία η χαρακτηριστική εξίσωση είναι η εξής

1 + FCG0 = 1 +

(s − 2)
(s + 5)(s − 2) = 1 +

1
s + 5
= 0 | (2.3)

Υπάρχει μόνο μία ρίζα στο s = −6, το οποίο σημαίνει πως έχουμε ευστάθεια. Αντιθέτως, ο πίνακας μεταφοράς H(s) υπολογίστηκε και έχει τιμή

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
s + 6

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
s + 5 −(s + 5)/(s − 2) −(s + 5) −(s + 5)
s − 2 | s + 5 | −(s − 2) −(s − 2)
1 | (s + 5)/(s − 2) | s + 5 | 1
1 | (s + 5)/(s − 2) | s + 5 | s + 5

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
(2.4)

το οποίο μας υποδεικνύει μία φραγμένη διαταραχή du θα δημιουργήσει μη φραγμένα σήματα e, y, yn

, με αποτέλεσμα το σύστημα κλειστού βρόχου να μην είναι εσωτερικά ευσταθές. Θα πρέπει να σημειωθεί πως στον υπολογισμό των σχέσεων (2.3) και (2.4), υποθέτουμε πως το s+a
s+a g (s) και g (s) είναι οι ίδιες συναρτήσεις μεταφοράς για οποιαδήποτε σταθερά α. Στη σχέση (2.3), η απαλοιφή του πόλου στο s = 2 του G0

(s) από το μηδενικό στο s = 2 του C(s) δεν έχει επιρροή στην εσωτερική ευστάθεια. Αυτό το παράδειγμα επιδεικνύει την πλήρη αποτελεσματικότητα της εσωτερικής ευστάθειας συγκριτικά με την κλασσική ευστάθεια που ορίζεται από τις ρίζες του χαρακτηριστικού πολυωνύμου 1+FCG0 = 0. Αν ωστόσο

Κεφάλαιο 2. Ευστάθεια Γραμμικών Χρονικά Αμετάβλητων Συστημάτων Ανάδρασης | 15

οι συναρτήσεις μεταφοράς G0

, C, F είναι σχετικά πρώτες, δηλαδή G0

(s) = n0(s)
p0(s) , C(s) = nc
| (s) pc (s) ,
F(s) = nf

(s)
pf

(s) , τότε μια ικανή και αναγκαία συνθήκη για εσωτερική ευστάθεια είναι πως οι ρίζες της χαρακτηριστικής εξίσωσης

p0pcpf + n0ncnf = 0 | (2.5)

να βρίσκονται στο ανοικτό αριστερό μιγαδικό επίπεδο. Για παράδειγμα, αν n0 = 1, p0 = s−2, nc = s − 2, pc = s + 5, nf = 1, pf = 1, τότε θα έχουμε

(s − 2)(s + 5) + (s − 2) = (s − 2)(s + 6) = 0

όπου θα υπάρχει μία ασταθής ρίζα, με συνέπεια το σύστημα κλειστού βρόχου να μην είναι εσωτερικά ευσταθές.

## 2.3 Συναρτήσεις Ευαισθησίας και Συναρτήσεις Συμπληρωματικής Ευαισθησίας

Καθώς η εσωτερική ευστάθεια μας εγγυάται πως όλα τα σήματα του κλειστού βρόχου είναι φραγμένα για οποιεσδήποτε φραγμένες εισόδους, οι προδιαγραφές για την απόδοση περιορίζουν το μέγεθος κάποιων φραγμάτων των σημάτων. Για παράδειγμα, ένας βασικός στόχος ενός συστήματος κλειστού βρόχου είναι να κρατά το σφάλμα μεταξύ της εξόδου y με το επιθυμητό σήμα y

∗
| μικρό στην
παρουσία εξωτερικών εισόδων, όπως επιθυμητές εισόδους, φραγμένες διαταραχές και θόρυβος. Ας υποθέσουμε πως έχουμε ένα σύστημα κλειστού βρόχου σύμφωνα με το σχήμα 1.2, με το F(s) = 1 και το du = 0. Χρησιμοποιώντας τη σχέση (2.1), μπορούμε να έχουμε τις εξής σχέσεις ανάμεσα στην έξοδο της διεργασίας y με τις εξωτερικές εισόδους y

∗
, d, dn

: y = T0y

∗ + S0d − T0dn | (2.6)

όπου τα
S0 ≜

1
1 + CG0

, T0 ≜

CG0
1 + CG0
είναι η συνάρτηση ευαισθησίας και συνάρτηση συμπληρωματικής ευαισθησίας αντίστοιχα. Επιπλέον, μπορούμε να διαπιστώσουμε πως ισχύει η εξής σχέση
S0 + T0 = 1 | (2.7)

Από τη σχέση (2.6) παρατηρούμε πως για να έχουμε καλή παρακολούθηση και απόρριψη της διαταραχής εξόδου, θα πρέπει να επιλεχθεί το σύστημα ανοιχτού βρόχου L0 ≜ CG0 τόσο μεγάλο, έτσι ώστε να έχουμε το S0 ≈ 0 και το T0 ≈ 1. Αντιθέτως, η ελαχιστοποίηση της επίδρασης του θορύβου της μέτρησης dn στο y χρειάζεται το L0 να είναι μικρό, έτσι ώστε το T0 ≈ 0, το οποίο μας δίνει από τη σχέση (2.7) το S0 ≈ 1. Το παραπάνω σκεπτικό μας δείχνει τους συμβιβασμούς που προκύπτουν κατά τη σχεδίαση συστημάτων κλειστού βρόχου, το οποίο είναι η σωστή παρακολούθηση και απόρριψη της διαταραχής (|L0

| ≫ 1, S0 ≈ 0, T0 ≈ 1) να ανταλλαχθεί με τη μείωση του θορύβου μέτρησης (|L0

| ≪ 1, S0 ≈ 1, T0 ≈ 0). Σε πολλά προβλήματα ελέγχου, τα y

∗
, d συνήθως είναι
σήματα χαμηλής συχνότητας και το dn

επιδρά στο σύστημα μόνο σε υψηλές συχνότητες. Έτσι σε αυτή την περίπτωση το C(s) πρέπει να σχεδιαστεί έτσι ώστε σε χαμηλές συχνότητες το L0 να είναι μεγάλο, με S0 ≈ 0, T0 ≈ 1, και σε υψηλές συχνότητες το L0 να είναι μικρό με S0 ≈ 1, T0 ≈ 0. Άλλος ένας λόγος που χρειαζόμαστε το κέρδος ανοιχτού βρόχου L0 να είναι μικρό είναι πως στις

16 | 2.4. Αρχή Εσωτερικού Μοντέλου

υψηλές συχνότητες υπάρχουν αβεβαιότητες από το δυναμικό μοντέλο της διεργασίας, του οποίου οι επιδράσεις θα μελετηθούν σε παρακάτω κεφάλαια.

## 2.4 Αρχή Εσωτερικού Μοντέλου

Σε πολλά προβλήματα ελέγχου, η επιθυμητή είσοδος y

∗
μπορεί να μοντελοποιηθεί ως

Qr

(s)y∗ = 0 | (2.8)

όπου Qr

(s) είναι ένα γνωστό πολυώνυμο, και s ≜ d dt είναι ο διαφορικός τελεστής. Για παράδειγμα, αν το y

∗ = constant, τότε Qr
(s) = s. Όταν το y

∗ = t, τότε το Qr

(s) = s²
και όταν το y

∗ = Asin(ω0
t)
για κάποια σταθερά A, ω0

, τότε το Qr

(s) = s²+ω²
0

, κ.α.. Αντίστοιχα, μία ντετερμινιστική διαταραχή d μπορεί να μοντελοποιηθεί ως

Qd

(s)d = 0 | (2.9)
για κάποιο γνωστό Qd

(s), το οποίο είναι διαθέσιμο σε περίπτωση γνώσης της πληροφορίας που σχετίζεται με τον θόρυβο d. Για παράδειγμα, αν το d είναι ένα ημιτονοειδές σήμα με άγνωστο πλάτος και φάση, αλλά με γνωστή γωνιακή συχνότητα ωd

, τότε μπορεί να μοντελοποιηθεί ο θόρυβος με την σχέση (2.9) όπου το Qd

(s) = s² + ω²
d
Η ιδέα πίσω από την Αρχή Εσωτερικού Μοντέλου είναι πως όταν συμπεριληφθεί ο παράγοντας 1
Qr

(s)Qd

(s) στον αντισταθμιτή C(s), τότε θα εξαλειφθεί η επίδραση των y

∗
, d στο σφάλμα παρακολούθησης e = y∗ − y. Για να δούμε πως λειτουργεί η ιδέα αυτή θα θεωρήσουμε πως έχουμε το σύστημα του σχήματος 1.2 με το F(s) = 1, du = dn = 0 και με επιθυμητή είσοδο y

∗
και θόρυβο
d που ικανοποιούν τις σχέσεις (2.8) και (2.9) αντίστοιχα με γνωστά πολυώνυμα Qr (s), Qd

(s). Τώρα
θα αντικαταστήσουμε το C(s) του σχήματος 1.2 με

C(s) = ̄

C(s)
Q(s), Q(s) = Qr

(s)Qd

(s) | (2.10)

όπου το C(s) της σχέσης (2.10) έχει επιλεχθεί με τέτοιον τρόπο, έτσι ώστε οι πόλοι κάθε στοιχείου του H(s) της (2.1) με την αντικατάσταση του C(s) από το C(s) ̄ να είναι ευσταθείς. Από την σχέση (2.6), με τα du = dn = 0 και με την αντικατάσταση του C με το C/Q, θα προκύψει

e = y∗ − y =

1

1 + CG0
Q

y

∗ −

1

1 + CG0
Q

d = 1
Q + CG0

Q(y∗ − d)

Επειδή το Q = QrQd

, τα y

∗
, d θα εξαλειφθούν λόγω των σχέσεων (2.8) και (2.9), με αποτέλεσμα να έχουμε

e =

1
Q + CG0

[0]

όπου μαζί με την ευστάθεια του 1/(Q + CG0

) που εξασφαλίστηκε από την επιλογή του C(s), θα έχουμε πως το σφάλμα e(t) = y∗
(t) − y(t) θα τείνει στο 0 εκθετικά γρήγορα. Η ιδιότητα της ακριβής παρακολούθησης από την αρχή του εσωτερικού μοντέλου μπορεί να αποδειχθεί και με τη χρήση των συναρτήσεων ευαισθησίας και συμπληρωματικής ευαισθησίας S0

, T0 στις συχνότητες των y

∗
, d. Για παράδειγμα, εάν η y

∗ = sin(ω0
t) και d = sin(ω1

t), με το
Q(s) = (s² + ω²
0

)(s² + ω²
1

), τότε θα έχουμε

S0 =

Q
Q + CG0

, T0 =

CG0
Q + CG0

Κεφάλαιο 2. Ευστάθεια Γραμμικών Χρονικά Αμετάβλητων Συστημάτων Ανάδρασης | 17

και S0
(jω0

) = S0

(jω1

) = 0, T0
(jω0

) = T0

(jω1

) = 1.
Μια ειδική κατηγορία της αρχής εσωτερικού μοντέλου αποτελεί ο ολοκληρωτικός έλεγχος όπου το Q(s) = s. Αυτός ο έλεγχος χρησιμοποιείται ευρέως στη βιομηχανία καθώς εξαλείφει τις επιδράσεις των επιθυμητών ενεργειών που εφαρμόζονται στο σύστημα και των διαταραχών στο σφάλμα παρακολούθησης.

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

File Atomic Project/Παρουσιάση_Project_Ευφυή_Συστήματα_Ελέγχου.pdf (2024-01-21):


# Εθνικό Μετσόβιο Πολυτεχνείο

## ΔΠΜΣ Συστήματα Αυτοματισμού

### Μάθημα: Ευφυή Συστήματα Ελέγχου και Ρομποτικής Εργασία Εξαμήνου

## Θετικά Πραγματικές Συναρτήσεις και Ευστάθεια Γραμμικών και Χρονικά Αμετάβλητων Συστημάτων Ανάδρασης

## Γεώργιος Κρομμύδας - 02121208

Αθήνα, Ιανουάριος 2024

# Δομή Παρουσίασης

1. Εισαγωγή
2. Θετικά Πραγματικές Συναρτήσεις μίας Μεταβλητής
3. Θετικά Πραγματικοί Πίνακες Συναρτήσεων Μεταφοράς
4. Ευστάθεια Γραμμικών και Χρονικά Αμετάβλητων Συστημάτων
5. Εσωτερική Ευστάθεια Συστημάτων Ανάδρασης
6. Συναρτήσεις Ευαισθησίας και Συμπληρωματικής Ευαισθησίας
7. Αρχή Εσωτερικού Μοντέλου
8. Βιβλιογραφία
Εξαμηνιαία Εργασία | Γεώργιος Κρομμύδας | Θετικά Πραγματικές Συναρτήσεις και Ευστάθεια LTI Συστημάτων Ανάδρασης | 2

# 1. Εισαγωγή

- Θετικά Πραγματικές Συναρτήσεις και Αυστηρά Θετικά Πραγματικές

Συναρτήσεις μιας μεταβλητής.

- Θετικά Πραγματικές Συναρτήσεις και Αυστηρά Θετικά Πραγματικές

Συναρτήσεις πολλών μεταβλητών.

- Ευστάθεια ΓΧΑΣ Ανάδρασης.
Εξαμηνιαία Εργασία | Γεώργιος Κρομμύδας | Θετικά Πραγματικές Συναρτήσεις και Ευστάθεια LTI Συστημάτων Ανάδρασης | 3

# 2. Θετικά Πραγματικές Συναρτήσεις μίας Μεταβλητής

Εξαμηνιαία Εργασία | Γεώργιος Κρομμύδας | Θετικά Πραγματικές Συναρτήσεις και Ευστάθεια LTI Συστημάτων Ανάδρασης | 4

Ορισμός

Μία γνήσια ρητή συνάρτηση G(s) με μιγαδική μεταβλητή s = σ + jω ονομάζεται ΘΠ

(Θετικά Πραγματική), αν

i. Η G(s) είναι πραγματική για πραγματικά s.
ii. Το ℜe | G s | ≥ 0 για όλα τα ℜe | s | > 0.

Λήμμα
Μία γνήσια ρητή συνάρτηση μεταφοράς G(s) είναι ΘΠ αν και μόνο αν
i. Η G(s) είναι πραγματική για πραγματικά s.
ii. Η G(s) είναι αναλυτική στο ℜe | s | > 0, και οι πόλοι που βρίσκονται πάνω στον

φανταστικό άξονα είναι απλοί με τους φανταστικούς συντελεστές των πόλων να είναι

θετικοί και πραγματικοί.

iii. Για όλες τις πραγματικές τιμές ω, τις οποίες το s = jω δεν αποτελεί πόλο της G(s), ένας

έχει ℜe | G jω | ≥ 0.

# Αυστηρά Θετικά Πραγματικές συναρτήσεις μιας Μεταβλητής

Εξαμηνιαία Εργασία | Γεώργιος Κρομμύδας | Θετικά Πραγματικές Συναρτήσεις και Ευστάθεια LTI Συστημάτων Ανάδρασης | 5

Ορισμός

Ας υποθέσουμε πως η G(s) δεν είναι ταυτόσημη μηδέν για όλα τα s. Τότε η G(s) είναι ΑΘΠ

(Αυστηρά Θετικά Πραγματική Συνάρτηση) αν το G(s − ε) είναι ΘΠ για κάποιο ε > 0.

Θεώρημα

Υποθέτουμε πως μία ρητή συνάρτηση μεταφοράς G(s) με μιγαδική μεταβλητή s = σ + jω είναι

πραγματική για πραγματικό s και δεν είναι ταυτόσημα μηδέν για όλα τα s. Έστω n

∗ ο σχετικός

βαθμός της G s = Z(s)/R(s) με το | n
∗ | ≤ 1. Τότε, η G s είναι ΑΘΠ αν και μόνο αν
i. | Η G(s) είναι αναλυτική στο ℜe | s | ≥ 0.
ii. Η ℜe | G(jω) | ≥ 0, ∀ ω ∈ −∞, ∞ .

iii. a. Όταν το n

| ∗ = 1, τότε lim
ω | →∞
| ω
2ℜe | G(jω) | > 0.
b. Όταν το n
| ∗ = −1 , τότε lim
ω | →∞
| | ℜe | G(jω)
jω | > 0.

# ΘΠ και ΑΘΠ Συναρτήσεις Μεταφοράς

Εξαμηνιαία Εργασία | Γεώργιος Κρομμύδας | Θετικά Πραγματικές Συναρτήσεις και Ευστάθεια LTI Συστημάτων Ανάδρασης | 6

Πόρισμα

i. Η G(s) είναι ΘΠ (ΑΘΠ) αν και μόνο αν η 1/G s είναι ΘΠ (ΑΘΠ).
ii. Αν η G s είναι ΑΘΠ, τότε, | n
∗ | ≤ 1, και οι πόλοι και τα μηδενικά της
G s βρίσκονται στο ℜe | s | < 0.
iii. Αν το | n
∗ | > 1, τότε η G s δεν είναι ΘΠ.
- Στην περίπτωση που το n

∗
= 0, τότε ικανές και αναγκαίες συνθήκες αποτελούν τα

(i), (ii) του θεωρήματος.

- Tο διάγραμμα Nyquist μιας ΘΠ (ΑΘΠ) G jω είναι στο ℜe | s | > 0.
- Σε ημιτονοειδής απόκριση η | ∠G jω | ≤ 90°, ∀ ω

# Παράδειγμα

Εξαμηνιαία Εργασία; Γεώργιος Κρομμύδας; Θετικά Πραγματικές Συναρτήσεις και Ευστάθεια LTI Συστημάτων Ανάδρασης; Έστω η G s =; ➢ Η G s είναι αναλυτική στο ℜe; ➢ Το lim

είναι μια ρητή και γνήσια συνάρτηση

μεταφοράς με σχετικό βαθμό n

Η συνάρτηση μεταφοράς είναι ΘΠ, ωστόσο δεν είναι ΑΘΠ.

Σχήμα 1: Διάγραμμα Nyquist Συνάρτησης Μεταφοράς G s
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

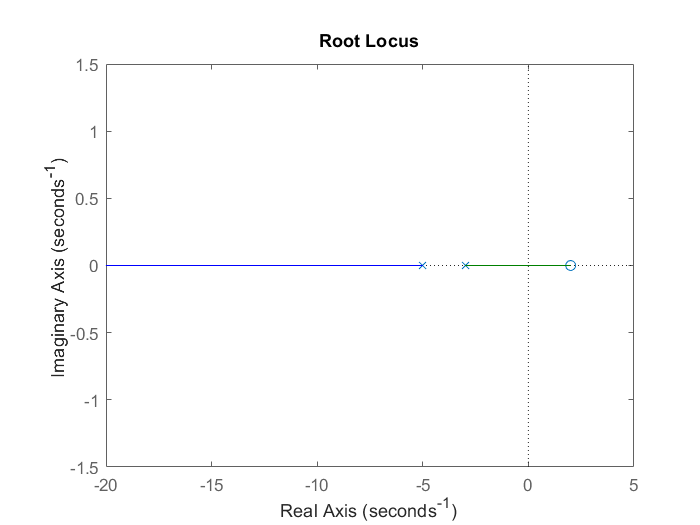
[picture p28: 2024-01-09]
Atomic Project/Images/Locus Plot G3.png

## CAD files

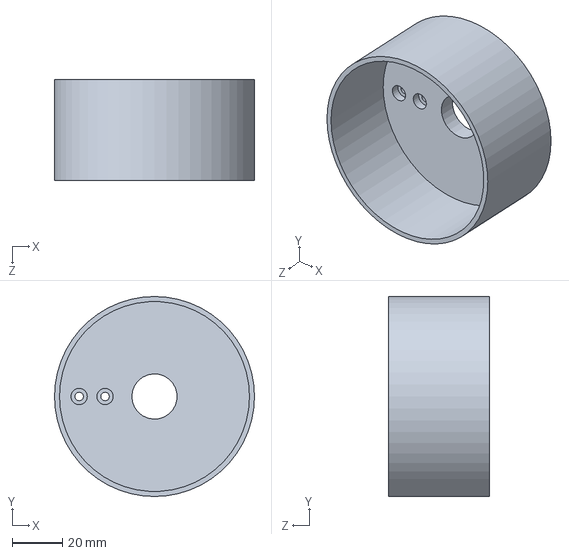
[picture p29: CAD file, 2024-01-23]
Team Project/3D Printing parts/base_tank.SLDPRT
79.5 x 79.5 x 40.0 mm

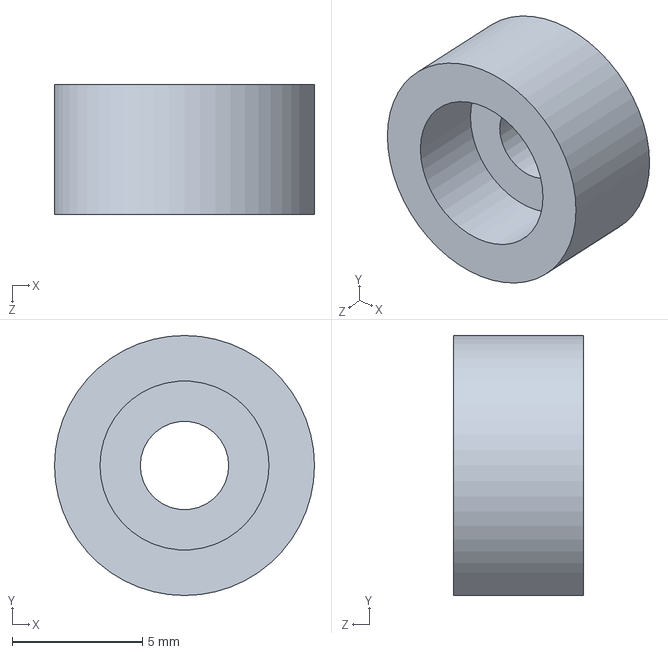
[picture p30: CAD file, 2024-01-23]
Team Project/3D Printing parts/m3_test.SLDPRT
10.0 x 10.0 x 5.00 mm

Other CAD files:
Team Project/3D Printing parts/base_tank.3MF
Team Project/3D Printing parts/m3_test.3MF

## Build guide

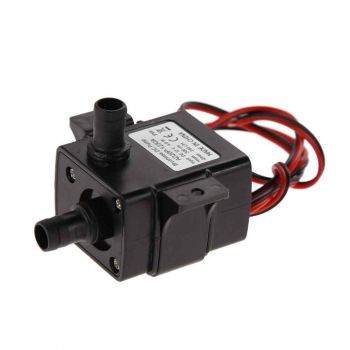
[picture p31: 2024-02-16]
Team Project/Construction Components/water pump.jpg

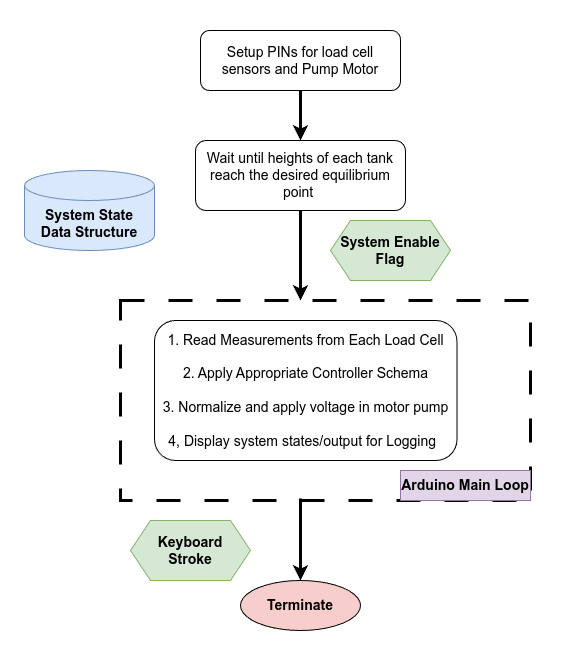
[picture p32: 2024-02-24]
Team Project/Construction Components/flow_chart_project.png

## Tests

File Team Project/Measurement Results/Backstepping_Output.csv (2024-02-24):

 | h1 | h2 | time_arduino | time_python | state
0 | 0.0 | 0.0 | 0.0 | 1.0894083976745605 | 0
1 | 0.0 | 0.0 | 0.0 | 2.101910352706909 | 0
2 | 0.0 | 0.0 | 0.0 | 3.113776683807373 | 0
3 | 0.0 | 0.0 | 0.0 | 4.125149250030518 | 0
4 | 0.0 | 0.0 | 0.0 | 5.139519929885864 | 0
5 | 0.0 | 0.0 | 0.0 | 6.154890060424805 | 0
6 | 0.0 | 0.0 | 0.0 | 7.172258138656616 | 0
7 | 0.0 | 0.0 | 0.0 | 8.178633689880371 | 0
8 | 0.0 | 0.0 | 0.0 | 9.194446563720703 | 0
9 | 0.0 | 0.0 | 0.0 | 10.209877967834473 | 0
10 | 0.0 | 0.0 | 0.0 | 11.213749647140503 | 0
11 | 0.0 | 0.0 | 0.0 | 12.222206354141235 | 0
12 | 0.0 | 0.0 | 0.0 | 13.237189054489136 | 0
13 | 0.0 | 0.0 | 0.0 | 14.247562170028687 | 0
14 | 0.0 | 0.0 | 0.0 | 15.276923418045044 | 0
15 | 0.0 | 0.0 | 0.0 | 16.29198932647705 | 0
16 | 0.0 | 0.0 | 0.0 | 17.29464054107666 | 0
17 | 0.0 | 0.0 | 0.0 | 18.306520223617554 | 0
18 | 0.0 | 0.0 | 0.0 | 19.321491718292236 | 0
19 | 0.0 | 0.0 | 0.0 | 20.328832149505615 | 0
20 | 0.0 | 0.0 | 0.0 | 21.346938371658325 | 0
21 | 0.0 | 0.0 | 0.0 | 22.354975700378418 | 0
22 | 0.0 | 0.0 | 0.0 | 23.370014190673828 | 0
23 | 0.0 | 0.0 | 0.0 | 24.378942012786865 | 0
24 | 0.0 | 0.0 | 0.0 | 25.3909113407135 | 0
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

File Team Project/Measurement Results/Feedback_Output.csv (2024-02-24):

 | h2(x1000) | xm | time_arduino | time_python | volt | law | e0(x1000) | e1(x1000) | h1 | h2 | theta1 | theta2 | beta | dtheta1 | dtheta2 | dbeta | H1, H2 x 1000
47 | 20.09 | 20 | 44867 | 46.18600464 | 0 | -12.91 | 0.12 | 0.08 | 35.04 | 20.12 | 10500 | 10500 | 1999.92 | 0.08 | -0.05 | -0.6 | ypoloipa x 1.000.000
48 | 20.12 | 20 | 44997 | 46.31913066 | 0 | 12.4 | 0.15 | -0.3 | 35.24 | 20.15 | 10500 | 10500 | 1999.91 | -0.12 | 0.07 | -1.08
49 | 20.15 | 20.01 | 45127 | 46.44768429 | 204 | 34.16 | 0.21 | -0.67 | 35.47 | 20.22 | 10500 | 10500 | 1999.84 | -0.3 | 0.18 | -7.12
50 | 20.22 | 20.02 | 45259 | 46.57972741 | 204 | 55.39 | 0.27 | -1.03 | 35.27 | 20.3 | 10500 | 10500 | 1999.66 | -0.48 | 0.28 | -18.26
51 | 20.3 | 20.04 | 45392 | 46.71468472 | 204 | 78.62 | 0.29 | -1.38 | 35.05 | 20.33 | 10499.99 | 10500.01 | 1999.3 | -0.67 | 0.39 | -35.64
52 | 20.33 | 20.06 | 45526 | 46.85012579 | 204 | 100.56 | 0.31 | -1.71 | 34.69 | 20.37 | 10499.98 | 10500.01 | 1998.72 | -0.84 | 0.5 | -57.78
53 | 20.37 | 20.08 | 45660 | 46.98026371 | 204 | 118.23 | 0.38 | -2.03 | 34.63 | 20.46 | 10499.97 | 10500.02 | 1997.92 | -1 | 0.59 | -80.39
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

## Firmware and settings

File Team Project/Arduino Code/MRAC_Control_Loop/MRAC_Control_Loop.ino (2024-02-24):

#include <BasicLinearAlgebra.h>
#include <HX711.h>
#include <stdio.h>

#define PI 3.1415926535897932384626433832795
#define V_LOW 0
#define V_HIGH 5
#define V_BINARY_LOW 0
#define V_BINARY_HIGH 255

// HX711_top circuit wiring
const int LOADCELL_DOUT_PIN_top = 7;
const int LOADCELL_SCK_PIN_top = 6;
const float scale_top_value = 854.48241206; // divide with [gr]

HX711 scale_top;

// HX711_bottom circuit wiring
const int LOADCELL_DOUT_PIN_bot = 9;
const int LOADCELL_SCK_PIN_bot = 8;
const float scale_bot_value = 142479.4/199; // divide with [gr]
float h2_cur;
float h2_prev;

HX711 scale_bot;

// Pin definitions for water pump
const int ENA = 10; // PWM
const int MOTOR1_PIN1 = 2; // 
const int MOTOR1_PIN2 = 3;

// time constanst
float time_prev = 0.0;
float time_cur = 0.0;


// Define System Parameters
#define a1 PI *pow(2 * pow(10, -3), 2)
#define a2 PI *pow(2 * pow(10, -3), 2)
// #define R 0.04 
#define R 0.0775/2 // in [m]
#define A PI *pow(R, 2) // in [m^2]
#define g 9.81 // [m/s^2]
#define Km 240 * pow(10, -3) / (5 * 3600)
#define rho 1*pow(10,3) // [kg/m^2]

// Define Adaptive Feedback Linearization Controller Parameters
#define gammax 500000
#define gammar 100000
#define dt 0.01 // in [sec]

const float theta1 = ((a1 / A) * sqrt(2 * g));
const float theta2 = ((a2 / A) * sqrt(2 * g));
const float b = Km / A;
//const float h_max = pow(10, -3) / A;
const float h_max = 0.06;
const float h1_e = h_max / 4;
const float h2_e = pow(theta2 / theta1, 2) * h1_e;
const float u_e = (theta1 / b) * sqrt(h1_e);
const float a2m = 4;
const float a1m = 2 * sqrt(a2m);
const float K1 = a2m;
const float K2 = 2*sqrt(a2m);
const int system_state_len = 7;
float system_state[] = {0, 0, 0, 0, 0, 0, 0};

// Global Variable
bool enabled = false;
char userInput;

void setup() {
  Serial.begin(9600);

  // Setup load cell (TOP)
  scale_top.begin(LOADCELL_DOUT_PIN_top, LOADCELL_SCK_PIN_top);
  scale_top.set_scale(scale_top_value);
  scale_top.tare();

  // Setup load cell (BOTTOM)
  scale_bot.begin(LOADCELL_DOUT_PIN_bot, LOADCELL_SCK_PIN_bot);
  scale_bot.set_scale(scale_bot_value); 
  scale_bot.tare();

  // Setup motor driver
  pinMode(ENA, OUTPUT);
  pinMode(MOTOR1_PIN1,OUTPUT);
  pinMode(MOTOR1_PIN2,OUTPUT);
  // Provide Direction
  digitalWrite(MOTOR1_PIN1, HIGH);
  digitalWrite(MOTOR1_PIN2, LOW);
  
  // Initial state
  // system_state[0] = h1_e;
  // system_state[1] = h2_e;
  system_state[4] = -40;
  system_state[5] = -12;
  system_state[6] = 24;

}

void loop() {
    if(Serial.available()> 0){ 
        // Serial.print('1');
        userInput = Serial.read();     
        if(userInput == 'g'){  
    
  if (!enabled) {
      initialization();
    }
    // Control Loop
    if (enabled) {
      h2_prev = system_state[1];
      readTopLoadCellMeasurement();
      readBotLoadCellMeasurement();
      h2_cur = system_state[1];
      time_cur = millis();
      float h2_dot = (h2_cur - h2_prev)/(time_cur - time_prev);
      float pump_value = MRAC(h2_dot);
      if (pump_value<0){pump_value = 0;}
      if (pump_value>5){pump_value = 3;}
      // Transform to [V]
      int volt_pump_value =
          map(pump_value, V_LOW, V_HIGH, V_BINARY_LOW, V_BINARY_HIGH);
      
      sendPump(volt_pump_value);
      delay(dt * 1000);
      h2_prev = system_state[1];
      time_prev = millis();
      Serial.print(system_state[1]*1000);
        Serial.print(",");
        Serial.print((system_state[2]+h2_e)*1000);
        Serial.print(",");
        Serial.print(millis());
        Serial.print(",");
        Serial.print("volt");
        Serial.print(",");
        Serial.print(volt_pump_value);
        Serial.print(",");
      }
    }
    else if (userInput == 'c'){
      sendPump(0);
    }
  }
}
void initialization() {

  float h1 = 0;
  float h2 = 0;
  sendPump(90); // MAX 255 
  while (h1 < h1_e || h2 < h2_e) {
  // while (true){
    h1 = readTopLoadCellMeasurement();
    h2 = readBotLoadCellMeasurement();
  }
  system_state[0] = h1;
  system_state[1] = h2;
  enabled = true;
  Serial.println("Target Reached");

  return;
}

// *==== Control Functions ====*

float MRAC(float h2_dot) {

  float r = ref() - h2_e;
  // BLA::Matrix<2, 2> Am = {0, 1, -a2m, -a1m};
  // BLA::Matrix<2, 1> Bm = {0, b};
  // BLA::Matrix<2, 2> P = {5.6461, 10, 10, 23.4787};
  float P11 = 5.6461;
  float P12 = 10;
  float P22 = 23.4787;

  // Decompose state variables
  // Decompose state variables
  float h1 = system_state[0];
  float h2 = system_state[1];
  float xm = system_state[2];
  float xm_dot = system_state[3];
  float Kx1_est = system_state[4];
  float Kx2_est = system_state[5];
  float Kr_est = system_state[6];
  
  float dxm0 = xm_dot;
  float dxm1 = -a2m*xm - a1m*xm_dot + a2m*r ;
  
  // Apply MRAC Controller
  float e0 = h2 - h2_e - xm;
  float e1 = h2_dot - xm_dot;
  float dKx0 = -gammax*(h2-h2_e)*(e0*P12 + e1*P22);
  float dKx1 = -gammax*h2_dot*(e0*P12 + e1*P22);
  float dKr = -gammar*r*(e0*P12 + e1*P22);
  
  // Projection
  if(Kr_est <= 0 && dKr < 0){
    dKr = 0;
  }
  if(Kr_est >= 1000 && dKr > 0){
    dKr = 0;
  }
  if(Kx1_est >= 0 && dKx0 > 0){
    dKx0 = 0;
  }
  if(Kx1_est <= -1000 && dKx0 < 0){
    dKx0 = 0;
  }

  if(Kx2_est >= 0 && dKx1 > 0){
    dKx1 = 0;
  }
  if(Kx2_est <= -1000 && dKx1 < 0){
    dKx1 = 0;
  }

  
  float u = Kx1_est*(h2-h2_e) + Kx2_est*h2_dot + Kr_est*r + 1.76;

  // Compute new state
  system_state[0] = h1;
  system_state[1] = h2;
  system_state[2] = xm + dt * dxm0;
  system_state[3] = xm_dot + dt * dxm1;
  system_state[4] = Kx1_est + dKx0 * dt;
  system_state[5] = Kx2_est + dKx1 * dt;
  system_state[6] = Kr_est + dKr * dt;

Serial.print("law");
  Serial.print(",");  
  Serial.print(u);
  Serial.print(","); 
  Serial.print("error");
  Serial.print(",");
  Serial.print(e0*1000);
  Serial.print(",");
  Serial.print(e1*1000);
  Serial.print(",");
  Serial.print("state: ");
  Serial.print(",");
  // Serial.print(system_state[0]*1000);
  // Serial.print(",");
  // Serial.print(system_state[1]*1000);
  // Serial.print(",");
  // Serial.print(system_state[2]*1000);
  // Serial.print(",");
  // Serial.print(system_state[3]*1000);
  // Serial.print(",");
  Serial.print(system_state[4]*1000);
  Serial.print(",");
  Serial.print(system_state[5]*1000);
  Serial.print(",");
  Serial.print(system_state[6]*1000);
  Serial.print(",");
  Serial.print(system_state[6]*1000);
  Serial.print(",");
  Serial.print(dKx0*1000);
  Serial.print(",");
  Serial.print(dKx1*1000);
  Serial.print(",");
  Serial.println(dKr*1000);
  
  return u;
}

double ref() { return h_max/2; }

// *==== SENSOR FUNCTIONS ====*

float readTopLoadCellMeasurement() {
  // Read from top load cell
  float top_load_cell_measurement = scale_top.get_units(1)/1000; // in [Kg]
  float h1 = top_load_cell_measurement / (A * rho);  // in [m]
  system_state[0] = h1;

  return h1;
}

float readBotLoadCellMeasurement() {
  // Read from bot load cell
  float bot_load_cell_measurement = scale_bot.get_units(1)/1000; // in [Kg]  
  float h2 = bot_load_cell_measurement / (A * rho); // in [m]
  system_state[1] = h2;

  // TODO: Print height 

  return h2;
}

void sendPump(int value) { analogWrite(ENA, value); }

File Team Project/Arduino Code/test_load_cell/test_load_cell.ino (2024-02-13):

#include <Arduino.h>
#include <HX711.h>

// HX711_top circuit wiring
const int LOADCELL_DOUT_PIN_top = 7;
const int LOADCELL_SCK_PIN_top = 6;

// HX711_bottom circuit wiring
const int LOADCELL_DOUT_PIN_bot = 9;
const int LOADCELL_SCK_PIN_bot = 8;

const float scale_top_value = 854.48241206; // divide with [gr]
const float scale_bot_value = 142479.4/199; // divide with [gr]

HX711 scale_top;
HX711 scale_bot;

void setup() {
  Serial.begin(9600);
  Serial.println("HX711 Demo");

  Serial.println("Initializing the scale");

  // Initialize library with data output pin, clock input pin and gain factor.
  // Channel selection is made by passing the appropriate gain:
  // - With a gain factor of 64 or 128, channel A is selected
  // - With a gain factor of 32, channel B is selected
  // By omitting the gain factor parameter, the library
  // default "128" (Channel A) is used here.
  // scale_top.reset();

  // *=== TOP LOAD CELL ===*
  scale_top.begin(LOADCELL_DOUT_PIN_top, LOADCELL_SCK_PIN_top);
  
  scale_top.set_scale(scale_top_value); // this value is obtained by calibrating the scale with known weights; see the README for details
  scale_top.tare(); // reset the scale to 0

  // *=== BOT LOAD CELL ===*

  scale_bot.begin(LOADCELL_DOUT_PIN_bot, LOADCELL_SCK_PIN_bot);
  scale_bot.set_scale(scale_bot_value); // this value is obtained by calibrating the scale with known weights; see the README for details
  scale_bot.tare(); // reset the scale to 0

  Serial.println("Readings:");
}

void loop() {
  Serial.print("scale_top reading:\t");
  Serial.print(scale_top.get_units(), 1);
  Serial.print("\t| average:\t");
  Serial.println(scale_top.get_units(10), 1);

  Serial.println("----------------------------------");

  Serial.print("scale_bot reading:\t");
  Serial.print(scale_bot.get_units(), 1);
  Serial.print("\t| average:\t");
  Serial.println(scale_bot.get_units(10), 1);

  Serial.println("================================");

  delay(1000);
}
